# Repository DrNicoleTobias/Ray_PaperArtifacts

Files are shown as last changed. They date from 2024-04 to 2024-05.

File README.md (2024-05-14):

# Ray Sensor Documentation Notes

Ray is a batteryless, doorframe/passageway-mounted room-level occupancy monitoring sensor that uses changes in indoor ambient light reflections to detect people entering and exiting a room or hallway and estimate their direction of travel.

<table style="width: 100%; border-collapse: collapse;">
  <tr>
    <td style="width: 100%; text-align: center;">
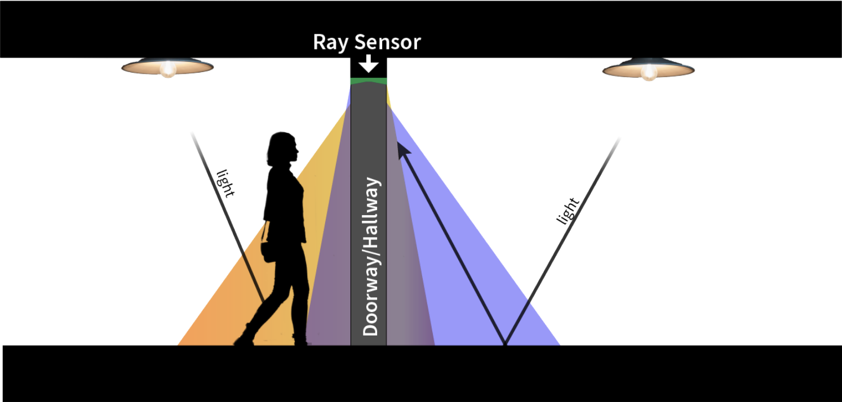
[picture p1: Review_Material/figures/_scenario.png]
Ray Use Scenario
      
      <br>
      <strong>Ray Use Scenario/Concept</strong>
    </td>
  </tr>
</table>

In this document, we provide the abstract of the work with highlights from our experiments, comments for the JSys reviewers, a layout of the folder/file structure, and instructions on how to build a Ray sensor and set it and a base station up for deployment.

# Abstract
Room-level occupancy-tracking systems enable intelligent control of building functions like air conditioning and power delivery to adapt to the needs of their occupants. Unfortunately, existing occupancy-tracking systems are bulky, have short battery lifetimes, are not privacy-preserving, or only provide coarse-grain occupancy information. Furthermore, retrofitting existing infrastructure with wired sensors is prohibitively expensive.

In this paper, we present Ray, a batteryless, doorframe/passageway-mounted room-level occupancy monitoring sensor that uses changes in indoor ambient light reflections to detect people entering and exiting a room or hallway and estimate direction of travel. We evaluated Ray in mixed lighting conditions on both sides of the doorway in an office-style setting, using subjects with a wide variety of physical characteristics. We conducted 881 controlled experiments in 7 doorways with 9 individuals and achieved a total detection accuracy of 100% and movement direction accuracy averaging 96.4%. Furthermore, we deployed Ray sensors for 64 days in 5 locations, comparing them with a commercial batteryless occupancy sensor. Ray outperformed the commercial sensor, particularly where traffic is moderate to heavy. Ray demonstrates that ambient light reflections provide both a promising low-cost, long-term sustainable option for monitoring how people use buildings and an exciting new research direction for batteryless computing.

# Artifact Evaluation - For JSys Reviewers
The artifacts associated with this paper consist of both hardware and software for building a functioning deployment of the Ray sensor.

We are including the custom PCB designs, Bill of Materials, and 3D prototype housing files used to create a Ray sensor. PDFs of the schematic and Design files are also included for reviewer convenience. Software for training and the firmware that runs the Ray sensor and base station are also provided. Documentation includes how to build, set up, tune, train, and deploy a Ray sensor as well as how to set up a base station for receiving the sensor data.

As the claims of this work are of the effectiveness of our custom Ray sensor, it is hard to automate items for testing and evaluation without actually having a physical sensor built, trained, and deployed for reviewers to test. After speaking with the chair of the Artifact Evaluation Board, we determined the best way to demonstrate the usability and reproducibility of this work is by providing the design files (raw and as PDFs for convenience), and making several demonstration videos to show the system working in controlled scenarios, in the presence of confounding cases, and when comparing to a commercial occupancy sensor. We hope they allow enough insight to judge the effectiveness, claims, and reproducibility of the work as it is hard to exactly recreate some of these experiments as they were gathered from live individuals walking through passageways.

# Folder/File Layout
This repo stores code, hardware files, and other technical documents for the project. Subdirectories are described below:

## Hardware
This folder contains all of the custom PCB Eagle design files (PDFs of the schematic and board design files are also included for reviewer convenience), Bill of Materials (BOM), and 3D prototype housing/enclosures files used to create a Ray sensor.

## Review_Material
This folder contains some of the additional artifact information for the working sensor including a Video Demo (.mp4) and a sampling of the data collected from both the controlled and uncontrolled experiments of the paper.  The Video Demo showcases the Ray sensor operating during a range of activities. These include people walking through doorways under the sensor, pass-by events where a person walks near the sensor but does not pass under it, and confounding cases like lingering and many people walking in a tight group. We also demonstrate in the video a comparison between the  sensor and the commercially available EnOcean sensor (a batteryless PIR-based occupancy sensor), showing that Ray is able to more accurately estimate the number of people during higher traffic conditions. 

Due to the nature of this project, much of the data gathering and ground truth labeling required manual intervention and processing to account for the amount of corner cases and fuzzy timing between two different sensors and ground truth.  A sampling of the manual data gathering for the controlled and uncontrolled experiments has been provided and the resulting excel files for the uncontrolled experiments are provided for review.  There are no scripts to run, table data for the uncontrolled experiments (Tables 5 and 6) came directly from excel formulas in the excel files for each location.

## Software
All software provided is either C code compiled and run on the MSP430FR5994 chips used for our sensor and base station or Python3 scripting code that is processed on a base station or laptop. Because there are variations in component quality and in doorway and lighting conditions, users want to train the classifier model on data more closely related to the test environment to improve accuracy. In that event, The following subfolders contain the code needed to gather the raw features from a Ray sensor (0_Get_Features) and train a new decision tree classifier model using those features (1_Train_Model). Once trained, the model will need to be manually implemented in the experiment code subfolders 2_Controlled_Studies and 3_Uncontrolled_Studies (specific locations to change are mentioned in those folders' ReadMe documentation.

### 0_Get_Features
This folder contains the firmware for both the Ray sensor and for a base station for gathering raw training data. The data gathered by the base station and sensor firmware here is intended for training a supervised classification model, in our case a decision tree model. This model should capture directional information from many individual events of common in and out events and can also include some additional example training data for some confounding, yet common, cases such as pass-by events. Have sample subjects walk in and out in a controlled manner to capture what the raw features from the sensor look like under local lighting conditions and environment. Collect this data using what is received at the base station and the result for that data that you wish to train with in a CSV file for use in training the model in the next step.

### 1_Train_Model
This folder contains a Python script called makedecisions.py that will use the CSV file of data gathered from the 0_Get_Features scripts/code in order to train a new decision tree to update the models for testing or real world deployment.

### 2_Controlled_Studies
This folder contains the firmware for both the Ray sensor and for a base station to receive packets from a Ray Sensor using the CC1101 Radio with a MSP430FR994 LaunchPad where the Ray Sensor sends a single packet for individual controlled events.

### 3_Uncontrolled_Studies
This folder contains the firmware for both the Ray sensor and for a base station to receive full packets from a deployed Ray Sensor using the CC1101 Radio with a MSP430FR994 LaunchPad where the Ray Sensor to send complete packets containing a sequence of 5 events, an estimate of their time between events, heartbeats in the absence of activity for 2 minutes, and history of the last two packets sent for redundancy.

# Building a Ray Sensor

In this section, we describe the steps it takes to build a physical Ray Sensor for deployment.

<table style="width: 150%; border-collapse: collapse;">
  <tr>
    <td style="width: 50%; text-align: center;">
      Ray Use Scenario
      <br>
      <strong>Ray PCB Close Up</strong>
    </td>
    <td style="width: 100%; text-align: center;">
      Ray Use Scenario
      <br>
      <strong>Ray Full Sensor</strong>
    </td>
  </tr>
</table>

## Housing/Enclosure, Parts, and Assembly
Our prototype hardware integrates a modular custom printed circuit board (PCB) housed in a 3D-printed plastic enclosure, four solar panels, and a TI CC1101 radio.

### Custom PCB
The PCB for the Ray sensor consists of three modular parts: a Solar_Module, a MCU_Module, and a Radio_Module. All design files for these modules and the Bill of Materials for all necessary PCB components can be found in the Hardware/PCB_Designs/ folder. Boards can be fabricated at many places online, such as OSHpark etc, and the components can be populated by hand or by a manufacturer as well. Design files can be viewed directly by a program like Eagle, but PDFs have been made available for convenience of viewing. The Solar_Module attaches to the MCU_Module and the MCU_Module attaches to the Radio_Module.

### 3D Enclosure
The 3D printed mounting system is made of PLA plastic and contains the PCB, solar cells, and necessary wiring connecting them. Enclosure designs to house the PCB and attach the solar panels to can be found in Hardware/3D_Enclosure/PCB_Housing_and_20_DegBody_Assembly.stl with a second file Hardware/3D_Enclosure/PCB_Housing_Cap.stl to make a cap to cover the PCB during deployment. The enclosure provides a nesting place for the solar cells, which angles the solar cell slots such that two of the four of the solar cells are pointed toward the entry, while the rest are pointed toward the exit.

### Connecting Solar Panels
Four solar panels need to be attached to the enclosure, where they will be divided into two sets of two panels each, one facing inward (the direction the radio antenna is pointing) and one set facing outward. The inward set of solar panels are connected in series and connected to the SOLAR1 terminal of the Solar Module PCB. The outward facing panels are also connected in series and then added to the SOLAR2 terminal.

### Tune the Detectors
Ray uses a detection circuit to determine when to wake up the microcontroller to assess the possible event. The detector circuitry is tunable using trim potentiometers (trim pots) pre-installation in deployment. Testers may find that, depending on the lighting conditions of a particular doorway, the sensitivity of the detector circuit's trim pots may need adjusting. We found in our experiments that we did need to adjust the trim pots some for the general lighting conditions and found that they generally worked for other similar lighting conditions without needing to be readjusted for every doorway. Using a screwdriver on TM1 for monitoring SOLAR1 or TM2 for monitoring SOLAR2 from the Solar_Module PCB schematics, turning to one direction will move the detection threshold and make the detectors more sensitive while turning in the opposite direction will make them less sensitive.

### Attaching a Radio
The Ray PCB also uses a TI CC1101 radio for communication that is to be connected to the Radio_Module in Hardware/PCB_Designs/. The TI CC1101 radio board is an off-the-shelf board that we designed a plug-in for on the Radio_Module boards. For our purposes, we considered the direction the antenna was pointing to be inward when mounting the sensor for practice, but one could train and adjust the code if pointing the other direction is preferred.

### Installing on a doorway
With all the parts assembled, tuned, connected, and attached to the 3D printed enclosure, the Ray sensor can be attached to the top of a doorway/passageway frame with solar panels facing down any preferred orientation. For our experiments, we affixed the 3D enclosure to a piece of wood with magnets screwed to the other side for ease in attaching and removing the sensor on different doorway/passageway frames, as most within our office building had metal frames or structures.

## Setting up a Base Station
To receive the data packets from the Ray Sensor, you will need a MSP430FR5994 LaunchPad and another off-the-shelf CC1101 Radio.  The radio will need to be connected to the LaunchPad’s pins as follows:
```
	*MSP430FR5994*	←    *CC1101*
		VCC	←	VCC
	 	GND	←	GND
	 	P3.4	←	GDO0
	 	P3.6	←	GDO2
	 	P4.3  	←	CSN
	 	P5.0  	←	MOSI
	 	P5.1 	←	MISO
	 	P5.2  	←	SCK 
```
And as documented in the top comment of each basestation_receive.c code in the folders containing base station code. If these pins need to be modified for a particular setup, there is an /includes/pins.h file in each folder containing base station code that can be easily modified.  Once attached, the base station firmware will need to be installed to the LaunchPad simply by connecting the LaunchPad by USB to a computer with msp-gcc installed.  Navigate to the firmware folder of interest, update the makefile as suggested in that folder’s readme, and then simply run “make install” to install the firmware on the LaunchPad.   Data can be gathered by simply reading off what is sent over serial or by using a script that grabs what is coming across from the LaunchPad over serial to a database.

## Training the event classification model
### Gather Raw Feature Data
All code needed to gather features to train a new model is located in the /Software/0_Get_Features/ folder for both the base station and the sensor.  Connect the LaunchPad to install the sensors firmware using the on board programmer (requires removing some jumpers) then return the jumpers and install the base station firmware for data collection.  Attach the sensor to a doorway or passageway face down, orientated in the direction you wish to train as inward vs outward.  Gather the data sent from the sensor to the base station over the serial port from many different individual controlled events and denote the ground truth for supervised training.  Record all of this data in a CSV file that will be used to train a new decision tree model.

### Train Model
To train a new decision for a new deployable environment, the following Python3 libraries must be installed: pandas, graphviz, and scikit-learn.  Once installed, navigate to the Software/1_Train_Model/ folder and locate the makedecisions.py file.  The file will need an updated path to the CSV feature data that was collected and there are several different classifier options available to train with.  Simply run “python3 makedecisions.py” to execute that code.  A visual graph will be generated for you to assess just how the training data falls in the model.
Some sample training data is available in that folder from our experimental setup that can be run with the makedecisions.py script in its current state to test how that script works.

### Translate Decision Tree Diagram to Implementation**
Now that a tree has been generated by the makedecisions.py script and the training data gathered, it will need to be manually translated and implemented in the deployable code for evaluating_event() found in both 2_Controlled_Experiments/RaySensor/SensorControlExperiments.c and 3_Uncontrolled_Experiments/RaySensor/SensorControlExperiments.c.  The documentation in both places will reference the line numbers where that function resides.  Once implemented, the firmware can be installed/uploaded to the sensor and the sensor can be deployed.

### Installing Firmware
The Ray firmware is designed to be ultra-low power, even in active mode, and has low computational complexity, offloading the bulk of the detection to the hardware circuits. All firmware code in the Software folder basically requires the same setup in order to program either the launchpad or the Ray Sensor.
1. Change the SUPPORT_FILE_DIRECTORY in the makefile to your msp430 gcc include
   path.
2. Hook up a MSP430FR5994 LaunchPad to your computer.
3. Connect the sensor to the Programmer pins on the LaunchPad (some jumpers may need to be removed to accomplish this) and plug them in to the appropriate programming pins on the MCU_Module.
4. Use "make install" to load the program into your device.
5. Detach from the programmer and reconnect the PCB in the enclosure and the unit is ready to be deployed. (Skip steps 3 and 5 if programming a MSP430 LaunchPad for a base station)

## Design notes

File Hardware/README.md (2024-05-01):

This folder contains all PCB hardware module files, Bill of Materials (BOM) associated with each module and the design files to 3D print a prototyping enclosure and cap/cover for the finished sensor PCB.

# PCB_Designs
This folder contains all of the design files for the custom Ray PCB modules (Solar, MCU, and Radio) as well as PDFs of these design files for viewers convenience.  These files were created using the AutoDesk Eagle Software.

# 3D_Enclosure
This folder is for the various 3D housing models that have been created for housing the custom PCB and solar panels for the final Ray Sensor.  

**BOM.xlsx**
This is the Bill of Materials that lists the parts/components used for each of the custom PCB modules (arranged by tabs).

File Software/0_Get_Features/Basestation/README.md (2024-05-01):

#### Intro
This is the firmware for a base station to  Receive packets using the CC1101 Radio with a MSP430FR994 launchpad.

#### Setup
1. Change the SUPPORT_FILE_DIRECTORY in the makefile to your msp430 gcc include
   path.
2. Hook up a MSP430FR5994 LaunchPad to your computer.
3. Use "make install" to load the program into your device.

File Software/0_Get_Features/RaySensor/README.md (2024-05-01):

#### Intro
This is the firmware for the Ray Sensor to send Raw Feature packets using the CC1101 Radio with a MSP430FR994 launchpad.  The features can be trimmed down to just ch1_start, ch1_end, ch2_start, ch2_end and the rest post processed from those values if you need to save energy due to packet size.

#### Setup
1. Change the SUPPORT_FILE_DIRECTORY in the makefile to your msp430 gcc include
   path.
2. Hook up a MSP430FR5994 LaunchPad to your computer.
3. Connect the sensor to the Programmer pins on the launchpad (You may need to remove some jumpers to accomplish this) and plug them in to the appropriate programming pins on the MCU_Module.
4. Use "make install" to load the program into your device.
5. Detach from programmer and reconnect the PCB in the enclosure and you are ready to deploy.

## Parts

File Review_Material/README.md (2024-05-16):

# Review_Materials

This folder contains some of the additional artifact information for the working sensor including a Video Demo (.mp4) and a sampling of the data collected from both the controlled and uncontrolled experiments of the paper. 

## Controlled Tests
<table style="width: 100%; border-collapse: collapse;">
  <tr>
    <td style="width: 100%; text-align: center;">
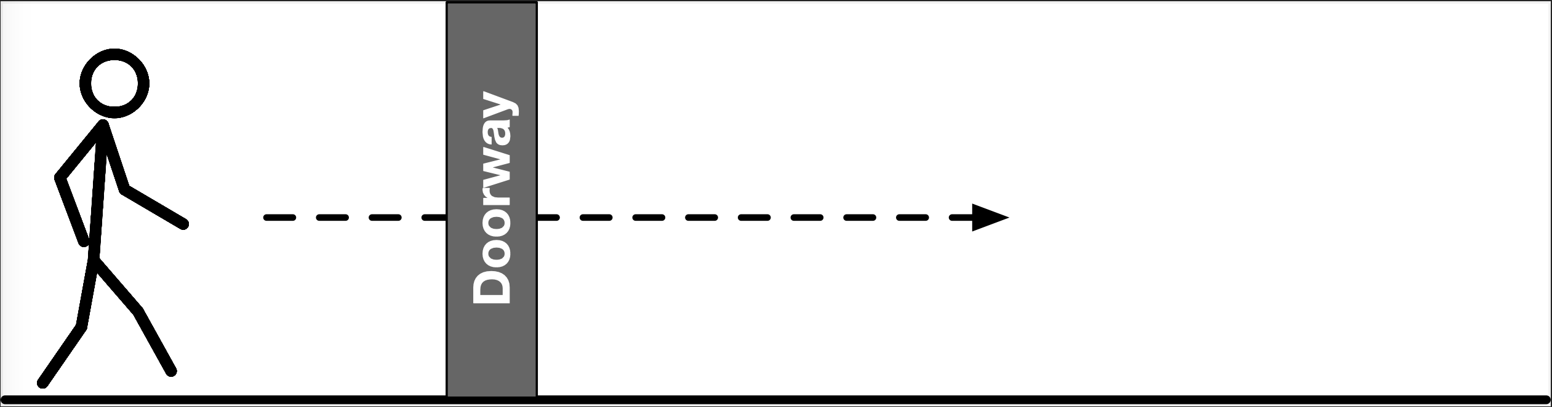
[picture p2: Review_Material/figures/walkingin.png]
Testing the Sensor: Controlled
      
      <br>
      <strong>Testing the Sensor: Controlled</strong>
    </td>
  </tr>
</table>
For the controlled experiments we collected data manually with the sensor sending out a single packet after each detected event.  We asked a subject to walk through the passageway where we would record the direction classified by out sensor in the column for the ground truth of the sensor as you can see in some of the samples provided in controlled_data_samples.pdf.  Most of the recordings were pretty straight forward, but occasionally other people (not affiliated with the experiment) would traverse the hallway or near the doorway and would trigger the sensor.  When this occurred, we marked that at a clobbered packet, discounted that info as it was not part of the control, and requested the subject to do another clean run to make up for the clobbered test.  This file shows that our sensor did well at detecting all of the events but occasionally classified them incorrectly.

## Video Demo

The Video Demo (SensorDemo.mp4) showcases the Ray sensor operating during a range of activities. These include people walking through doorways under the sensor, pass-by events where a person walks near the sensor but does not pass under it, and confounding cases like lingering and many people walking in a tight group. We also demonstrate in the video a comparison between the sensor and the commercially available EnOcean sensor (a batteryless PIR-based occupancy sensor), showing that Ray is able to more accurately estimate the number of people during higher traffic conditions.

## Uncontrolled Deployment

<table style="width: 100%; border-collapse: collapse;">
  <tr>
    <td style="width: 100%; text-align: center;">
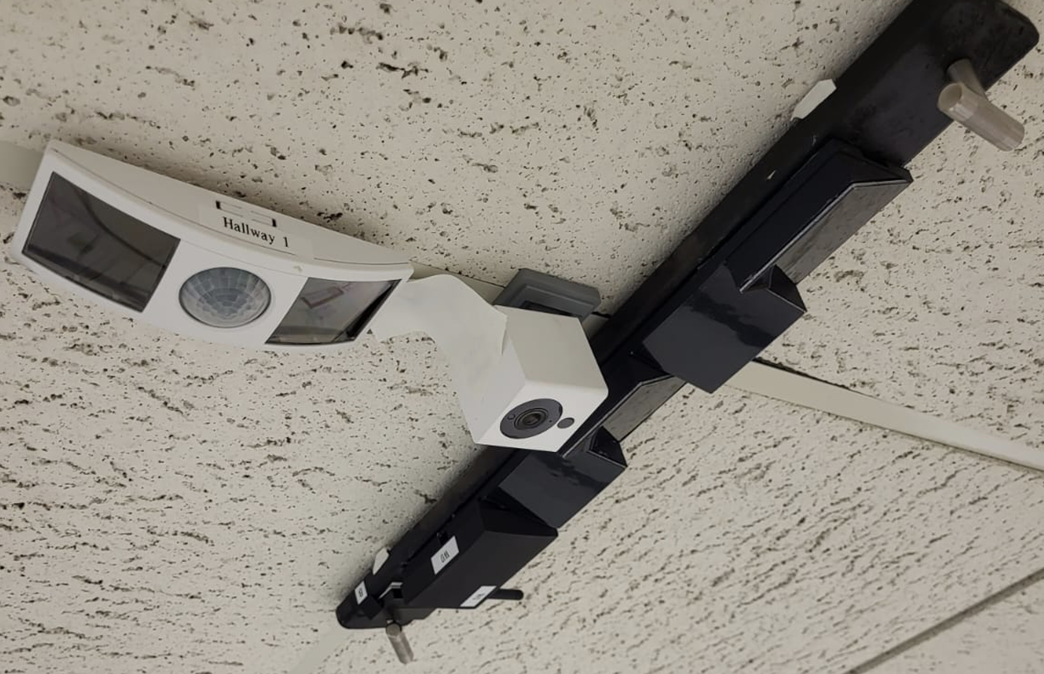
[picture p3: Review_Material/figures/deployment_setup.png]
Deployment Setup
      
      <br>
      <strong>Deployment Setup</strong>
    </td>
  </tr>
</table>

Due to the nature of this project, much of the data gathering and ground truth labeling required manual intervention and processing to account for the amount of corner cases and fuzzy timing between two different sensors and ground truth. A sampling of the manual data gathering for the controlled and uncontrolled experiments has been provided and the resulting excel files for the uncontrolled experiments are provided for review. There are no scripts to run, table data for the uncontrolled experiments (Tables 5 and 6) came directly from excel formulas in the excel files for each location.

### Ground Truth
Ground truth was captured by an off the shelf Wyze camera that was constantly powered and capturing data.  Video was collected, processed to pull out any frames with movement, and then manually labeled.  The field of view was different for the camera than for either sensor and with reliable power had a more accurate sense of time.  This made matching up our sensor data and commercial sensor data to compare a bit of a manual process as well.

### Our Sensor vs Ground Truth
<table style="width: 100%; border-collapse: collapse;">
  <tr>
    <td style="width: 100%; text-align: center;">
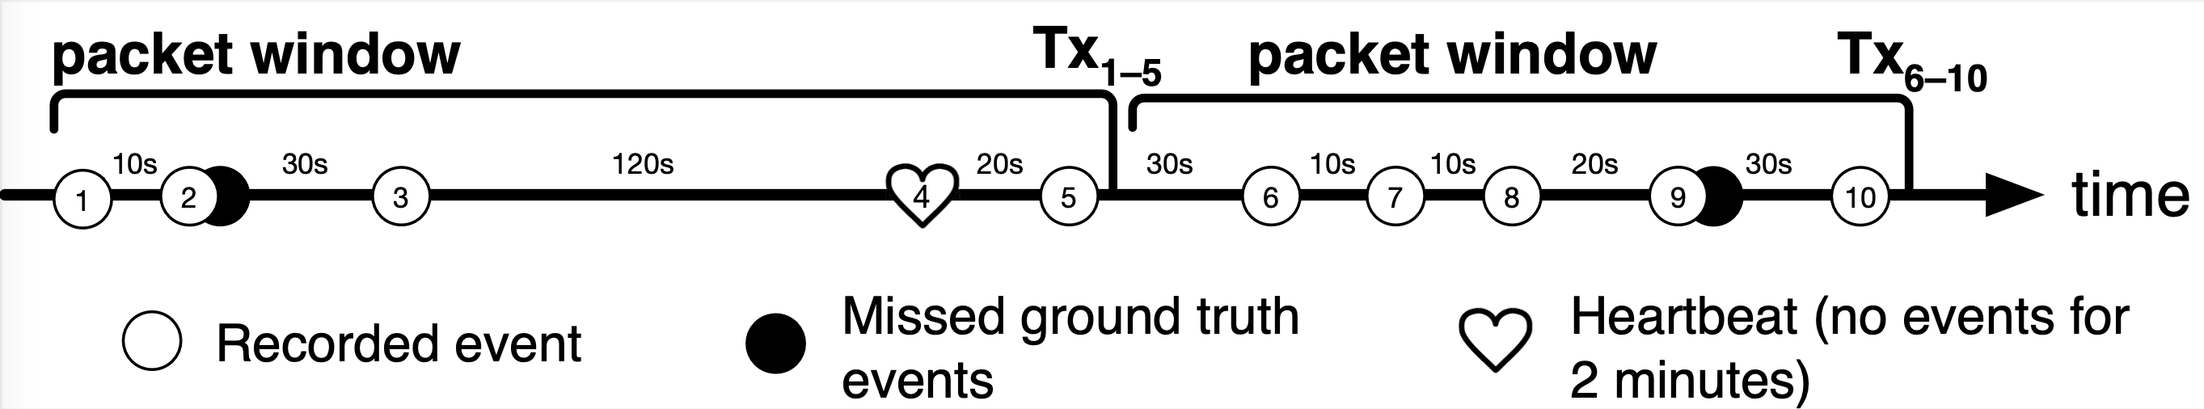
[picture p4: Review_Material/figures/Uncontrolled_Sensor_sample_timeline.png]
Example Sensor Event Timeline
      
      <br>
      <strong>Example Sensor Event Timeline</strong>
    </td>
  </tr>
</table>

### Our Sensor vs Commercial Sensor (EnOcean)

<table style="width: 100%; border-collapse: collapse;">
  <tr>
    <td style="width: 100%; text-align: center;">
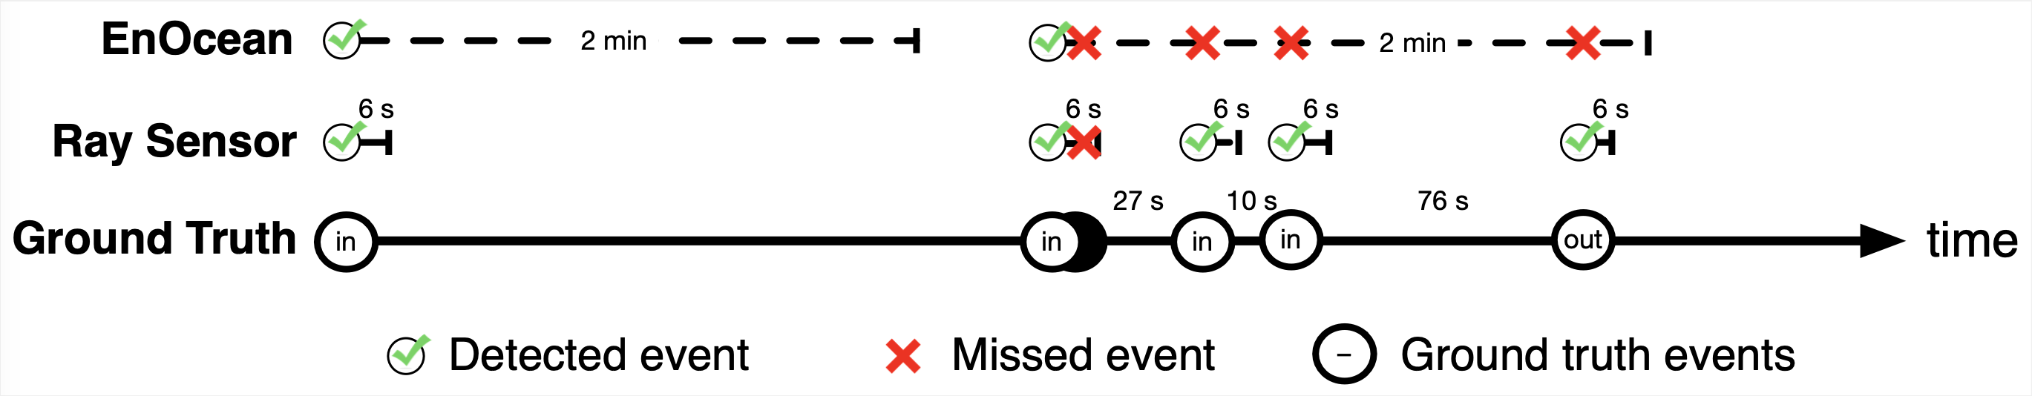
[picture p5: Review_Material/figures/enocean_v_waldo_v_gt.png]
Example Sensor Comparison Timeline
      
      <br>
      <strong>Example Sensor Comparison Timeline</strong>
    </td>
  </tr>
</table>

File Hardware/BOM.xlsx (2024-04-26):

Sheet: SolorPanel_Mod
Index | Quantity | Part Number | Manufacturer P/N | Description | Customer Reference | Unit Price USD | Extended Price USD | Price per 1000 | Extended Price per 1000 | Purchased From
1 | 2 | ED10561-ND | OSTVN02A150 | CONN TERM BLOCK 2.54MM 2POS PCB | Solar1, Solar2 | 0.92 | $1.84 | $312.49 | $624.98 | Digi-Key
2 | 1 | P0.0GCT-ND | ERJ-3GEY0R00V | RES SMD 0 OHM JUMPER 1/10W 0603 | R0 | 0.1 | $0.10 | $7.65 | $7.65 | Digi-Key
4 | 1 | 749-1754-1-ND | MCT06030C5102FP500 | RES 51K OHM 1% 1/10W 0603 | R2 | 0.15 | $0.15 | $48.88 | $48.88 | Digi-Key
6 | 1 | YAG4565CT-ND | RT0603BRD07499KL | RES SMD 499K OHM 0.1% 1/10W 0603 | R4 | 0.31 | $0.31 | $43.56 | $43.56 | Digi-Key
7 | 2 | 511-SFR03EZPF7503CT-ND | SFR03EZPF7503 | 750 kOhms ±1% 0.1W, 1/10W Chip Resistor 0603 | R1, R10 | 0.14 | $0.28 | $21.38 | $42.76 | Digi-Key
8 | 1 | 311-1.20MHRCT-ND | RC0603FR-071M2L | RES SMD 1.2M OHM 1% 1/10W 0603 | R3 | 0.1 | $0.10 | $3.45 | $3.45 | Digi-Key
9 | 1 | YAG3326CT-ND | RC0603FR-071M3L | RES SMD 1.3M OHM 1% 1/10W 0603 | R5 | 0.1 | $0.10 | $3.45 | $3.45 | Digi-Key
10 | 4 | 311-2.00MHRCT-ND | RC0603FR-072ML | RES SMD 2M OHM 1% 1/10W 0603 | R6, R7, R8, R9 | 0.1 | $0.40 | $3.45 | $13.80 | Digi-Key
13 | 4 | 478-1227-1-ND | 06035C103KAT2A | CAP CER 10000PF (10nF) 50V X7R 0603 | C1, C4, C5, C6 | 0.1 | $0.40 | $7.53 | $30.12 | Digi-Key
14 | 1 | 1276-1012-1-ND | CL10F104ZB8NNNC | CAP CER 0.1UF 50V Y5V 0603 | C3 | 0.1 | $0.10 | $6.61 | $6.61 | Digi-Key
16 | 2 | 490-10510-1-ND | GRM21BR60G107ME15L | CAP CER 100UF 4V X5R 0805 | C2*stacked | 1.04 | $2.08 | $1040.00 | $2080.00 | Digi-Key
17 | 1 | BZT52C5V1-FDICT-ND | BZT52C5V1-7-F | DIODE ZENER 5.1V 500MW SOD123 | Z1 | 0.22 | $0.22 | $45.42 | $45.42 | Digi-Key
18 | 1 | RB751S40T1GOSCT-ND | RB751S40T1G | DIODE SCHOTTKY 30V 30MA SOD523 | D1 | 0.21 | $0.21 | $44.52 | $44.52 | Digi-Key
19 | 1 | 576-2923-1-ND | MIC841HYC5-TR | IC COMP SNGL W/REF SC70-5 | MIC | 0.77 | $0.77 | $600.00 | $600.00 | Digi-Key
20 | 1 | 1662-2522-1-ND | S-1313D22-N4T1U4 | IC REG LINEAR 2.2V 200MA SC82AB | REG | 1.45 | $1.45 | $663.00 | $663.00 | Mouser
21 | 2 | TC33X-104ECT-ND | TC33X-2-104E | TRIMMER 100K OHM 0.1W J LEAD TOP | TM1, TM2 | 0.28 | $0.56 | $174.22 | $348.44 | Digi-Key
22 | 2 | 296-37910-1-ND | TLV3691IDCKR | IC COMPARATOR NANO-POWER SC70-5 | C_COMP, B_COMP | 1.31 | $2.62 | $596.28 | $1192.56 | Digi-Key
23 | 4 | n/a | SKU 313070004 | 0.5W Solar Panel 55x70 | solar panels | 1.95 | $7.80 | $1660.00 | $6640.00 | SEEEDstudio
24 | 1 | 401-1999-1-ND | JS102011SAQN | SWITCH SLIDE SPDT 300MA 6V | S1 | 0.64 | $0.64 | $433.70 | $433.70 | Digi-Key
25 | 1 | 609-3371-ND | 68602-208HLF | CONN HEADER 8POS .100 STR 15AU | J1 | 0.59 | $0.59 | $306.47 | $306.47 | Digi-Key
26 | 10 | A106145CT-ND | RCU-0C | PC TEST POINT NATURAL | VIN, VCC, BDIFF, CDIFF, BRAW, CRAW, BREF, CREF, BRES, CRES | 0.26 | $2.60 | $123.95 | $1239.50 | Digi-Key
27 | 4 | S9014E-03-ND | GRPB031VWVN-RC | CONN HEADER .050" 3POS PCB GOLD | JP2, JP3, JP23, JP24 | 0.28 | $1.12 | $130.72 | $522.88 | Digi-Key
28 | 4 | 952-1731-ND | M50-2000005 | CONN SHUNT 1.27MM BLACK W/HANDLE | JP2, JP3, JP23, JP24 | 0.44 | $1.76 | $208.56 | $834.24 | Digi-Key
 |  |  |  |  |  | total: | 26.2 |  | 15.77599
 | 52
updated 2/14/23

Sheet: MCU_Mod
Index | Quantity | Part Number | Manufacturer P/N | Description | Customer Reference | Unit Price USD | Extended Price USD | Price per 1000 | Extended Price per 1000 | Purchased From
1 | 1 | 541-820HCT-ND | CRCW0603820RFKEA | RES SMD 820 OHM 1% 1/10W 0603 | R1 | 0.1 | $0.10 | $7.01 | $7.01 | Digi-Key
2 | 1 | RMCF0603FT2M00CT-ND | RMCF0603FT2M00 | RES 2M OHM 1% 1/10W 0603 | R3 | 0.1 | $0.10 | $9.32 | $9.32 | Digi-Key
3 | 1 | RMCF0603JT12M0CT-ND | RMCF0603JT12M0 | RES 12M OHM 5% 1/10W 0603 | R2 | 0.1 | $0.10 | $3.72 | $3.72 | Digi-Key
4 | 1 | 311-47.0KHRCT-ND | RC0603FR-0747KL | RES SMD 47K OHM 1% 1/10W 0603 | R4 | 0.1 | $0.10 | $3.45 | $3.45
5 | 0 | 1276-1192-1-ND | CL10A106KP8NNNC | CAP CER 10UF 10V X5R 0603 | C1*, C6* | 0.19 | $0.00 | $37.85 | $0.00 | Digi-Key
6 | 4 | 1276-1012-1-ND | CL10F104ZB8NNNC | CAP CER 0.1UF 50V Y5V 0603 | C2, C3, C4*, C5*, C9, C10 | 0.1 | $0.40 | $6.61 | $26.44 | Digi-Key
7 | 2 | 1276-2228-1-ND | CL10C220JB8NFNC | CAP CER 22PF 50V C0G/NP0 0603 | C7, C8 | 0.1 | $0.20 | $10.89 | $21.78 | Digi-Key
8 | 1 | 490-4931-1-ND | GCM188R71H222KA37D | CAP CER 2200PF 50V X7R 0603 | C11 | 0.19 | $0.19 | $36.21 | $36.21
9 | 1 | RB751S40T1GOSCT-ND | RB751S40T1G | DIODE SCHOTTKY 30V 30MA SOD523 | D1 | 0.21 | $0.21 | $44.52 | $44.52 | Digi-Key
10 | 1 | 160-1183-1-ND | LTST-C190GKT | LED GREEN CLEAR CHIP SMD | D2 | 0.24 | $0.24 | $44.18 | $44.18 | Digi-Key
11 | 1 | 296-45416-1-ND | MSP430FR5994IRGZT | IC MCU 16BIT 256KB FRAM 48VQFN | U1 | 13.28 | $13.28 | $8650.86 | $8650.86 | Digi-Key
12 | 1 | ISL21080DIH309Z-TKCT-ND | ISL21080DIH309Z-TK | IC VREF SERIES 0.9V SOT23-3 | U2 | 2.06 | $2.06 | $1224.30 | $1224.30 | Digi-Key
13 | 0 | 296-47911-1-ND | LPV821DBVR | ZERO-DRIFT LOW POWER AMPLIFIER | U3*, U4* | 2.42 | $0.00 | $1189.64 | $0.00 | Digi-Key
14 | 1 | SER4071CT-ND | FC-135R 32.7680KA-A3 | CRYSTAL 32.7680KHZ 12.5PF SMT | Q1 | 1.18 | $1.18 | $919.10 | $919.10 | Digi-Key
15 | 1 | 490-5216-1-ND | BLM18HE152SN1D | FERRITE BEAD 1.5 KOHM 0603 1LN | L1 | 0.19 | $0.19 | $60.78 | $60.78 | Digi-Key
16 | 2 | S9014E-03-ND | GRPB031VWVN-RC | CONN HEADER .050" 3POS PCB GOLD | Jumpers (ON, Batt_jmp) | 0.28 | $0.56 | $130.72 | $261.44 | Digi-Key
17 | 2 | 952-1731-ND | M50-2000005 | CONN SHUNT 1.27MM BLACK W/HANDLE | Jumpers Caps | 0.44 | $0.88 | $208.56 | $417.12 | Digi-Key
18 | 1 | ED10561-ND | OSTVN02A150 | CONN TERM BLOCK 2.54MM 2POS PCB | Batt | 0.92 | $0.92 | $312.49 | $312.49 | Digi-Key
19 | 1 | S7072-ND | PPTC042LFBN-RC | CONN HEADER FMALE 8PS .1" DL TIN | Solar-1 | 0.67 | $0.67 | $368.64 | $368.64 | Digi-Key
20 | 1 | S7074-ND | PPTC062LFBN-RC | CONN HEADER FMAL 12PS .1" DL TIN | Radio_conn | 0.79 | $0.79 | $433.44 | $433.44 | Digi-Key
21 | 3 | A106145CT-ND | RCU-0C | PC TEST POINT NATURAL | test point probes | 0.26 | $0.78 | $123.95 | $371.85 | Digi-Key
 |  |  |  |  |  | total: | $22.95 |  | $13.22
updated 2/14/23 |  |  |  |  | * = DNP

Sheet: Radio_Mod
Index | Quantity | Part Number | Manufacturer P/N | Description | Customer Reference | Unit Price USD | Extended Price USD | Unit Price per 1000 | Extended Price per 1000 | Purchased From
1 | 1 | 749-1615-1-ND | MCT06030C2203FP500 | RES 220K OHM 1% 1/10W 0603 | R2 | 0.15 | $0.15 | $22.64 | $22.64 | Digi-Key
2 | 2 | RMCF0603JT12M0CT-ND | RMCF0603JT12M0 | RES 12M OHM 5% 1/10W 0603 | R1, R3 | 0.1 | $0.20 | $3.72 | $7.44
3 | 2 | 490-10510-1-ND | GRM21BR60G107ME15L | CAP CER 100UF 4V X5R 0805 | C1*stacked | 1.04 | $2.08 | $1040.00 | $2080.00 | Digi-Key
4 | 1 | RB751S40T1GOSCT-ND | RB751S40T1G | DIODE SCHOTTKY 30V 30MA SOD523 | D1 | 0.21 | $0.21 | $44.52 | $44.52 | Digi-Key
5 | 2 | 3313J-1-205ECT-ND | 3313J-1-205E | TRIMMER 2M OHM 0.125W J LEAD TOP | TM1, TM2 | 0.29 | $0.58 | $186.34 | $372.68 | Digi-Key
6 | 1 | 1662-2522-1-ND | S-1313D22-N4T1U4 | IC REG LINEAR 2.2V 200MA SC82AB | REG | 1.45 | $1.45 | $663.00 | $663.00 | Digi-Key
7 | 2 | 296-37910-1-ND | TLV3691IDCKR | IC COMPARATOR NANO-POWER SC70-5 | Hi-lo-1, Hi-lo-2 | 1.31 | $2.62 | $596.28 | $1192.56 | Digi-Key
8 | 1 | S6105-ND | PPTC052LFBN-RC | CONN HEADER FEM 10POS .1" DL TIN | cc1101_conn | 0.69 | $0.69 | $378.72 | $378.72 | Digi-Key
9 | 1 | S2021E-06-ND | PBC06DABN | CONN HEADER .100 DUAL STR 12POS | radio_conn | 0.98 | $0.98 | $608.40 | $608.40 | Digi-Key
10 | 6 | A106145CT-ND | RCU-0C | PC TEST POINT NATURAL | test point probes | 0.26 | $1.56 | $123.95 | $743.70 | Digi-Key
11 | 3 | S9014E-03-ND | GRPB031VWVN-RC | CONN HEADER .050" 3POS PCB GOLD | Jumpers (ON, Batt_jmp) | 0.28 | $0.84 | $130.72 | $392.16 | Digi-Key
12 | 3 | 952-1731-ND | M50-2000005 | CONN SHUNT 1.27MM BLACK W/HANDLE | Jumpers Caps | 0.44 | $1.32 | $208.56 | $625.68 | Digi-Key
13 | 1 | N/a | RF1100SE | CC1101 Wireless RF Transceiver 315/433/868/915MHZ + SMA Antenna Wireless Module | CC1101 Radio + Antenna | 11.5 | $11.50 | $1150.00 | $1150.00 | Amazon
 |  |  |  |  |  | total: | $24.18 |  | $8.28
updated 2/14

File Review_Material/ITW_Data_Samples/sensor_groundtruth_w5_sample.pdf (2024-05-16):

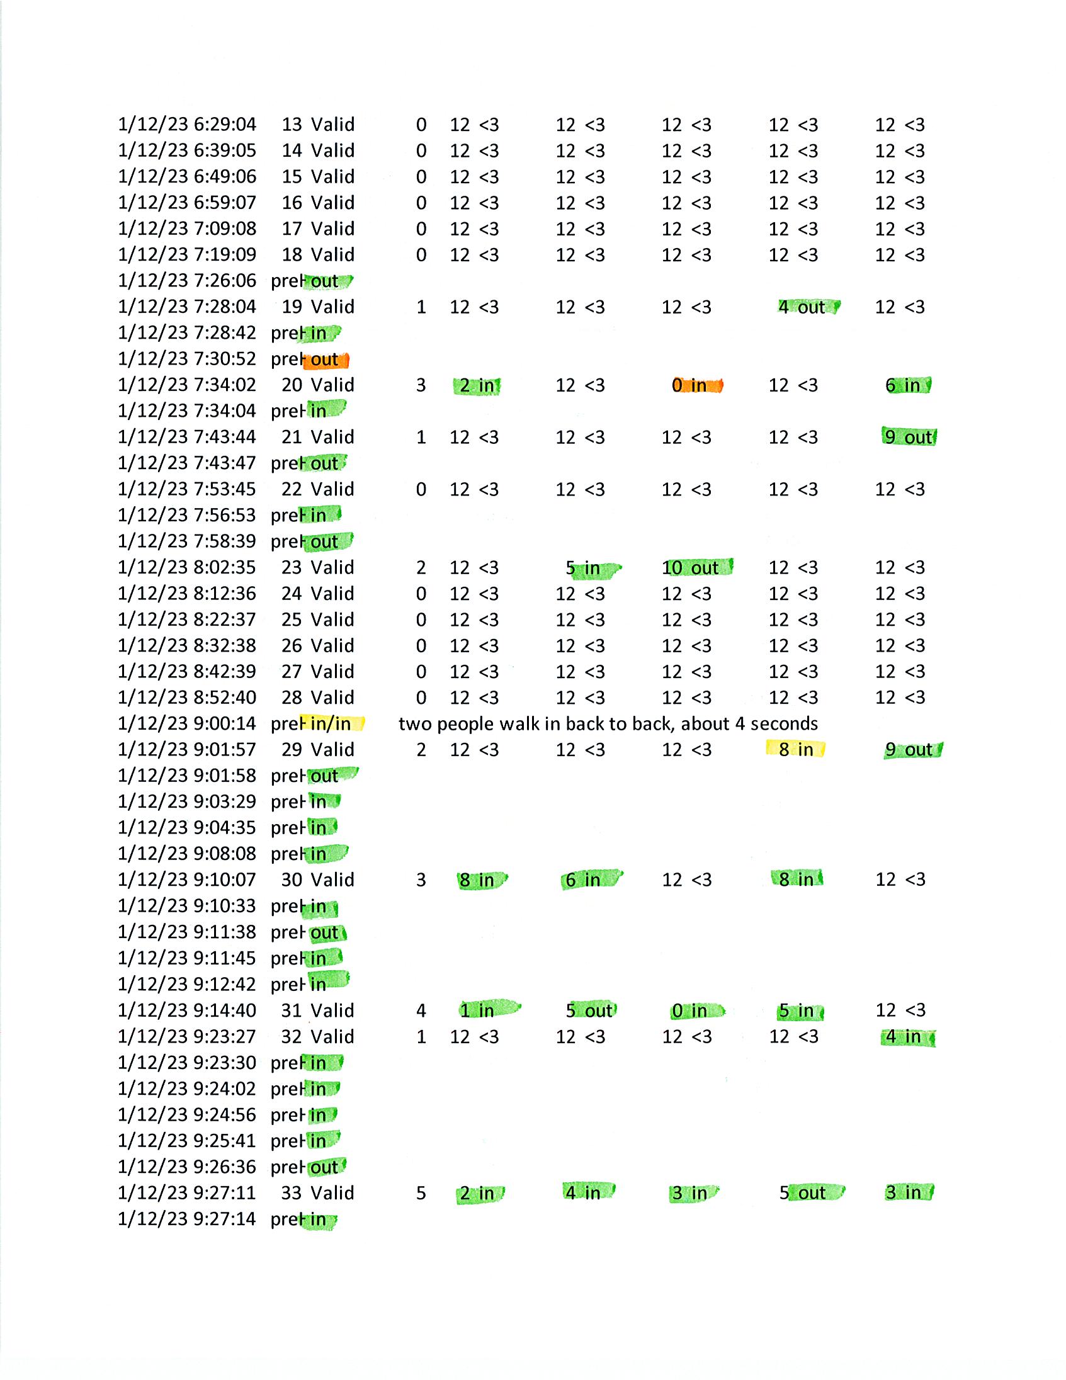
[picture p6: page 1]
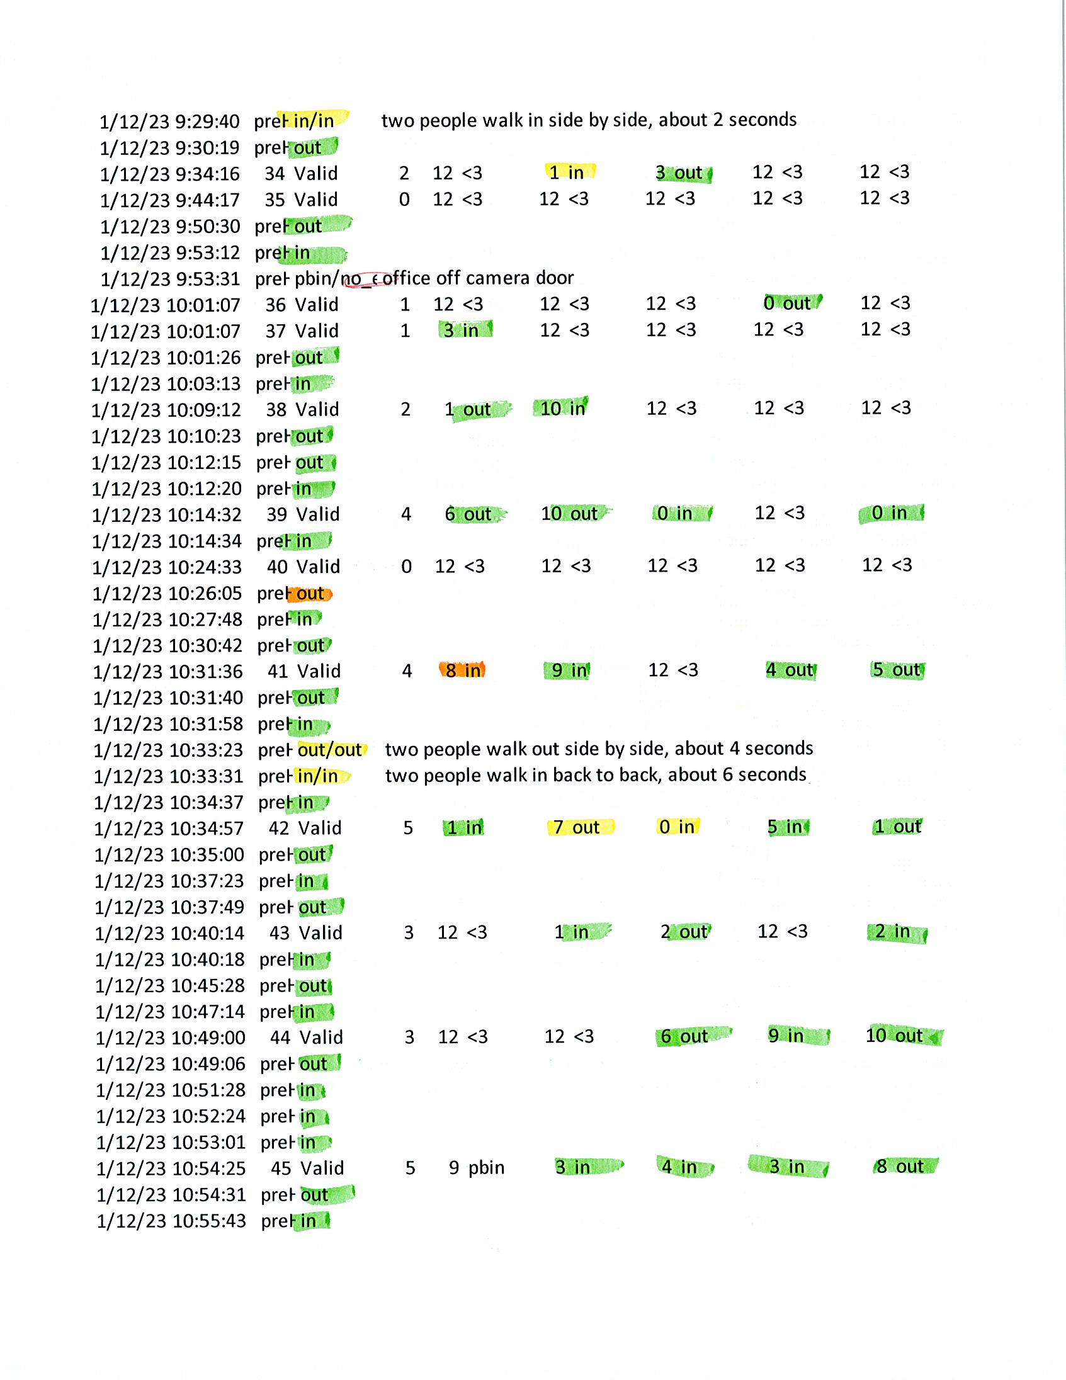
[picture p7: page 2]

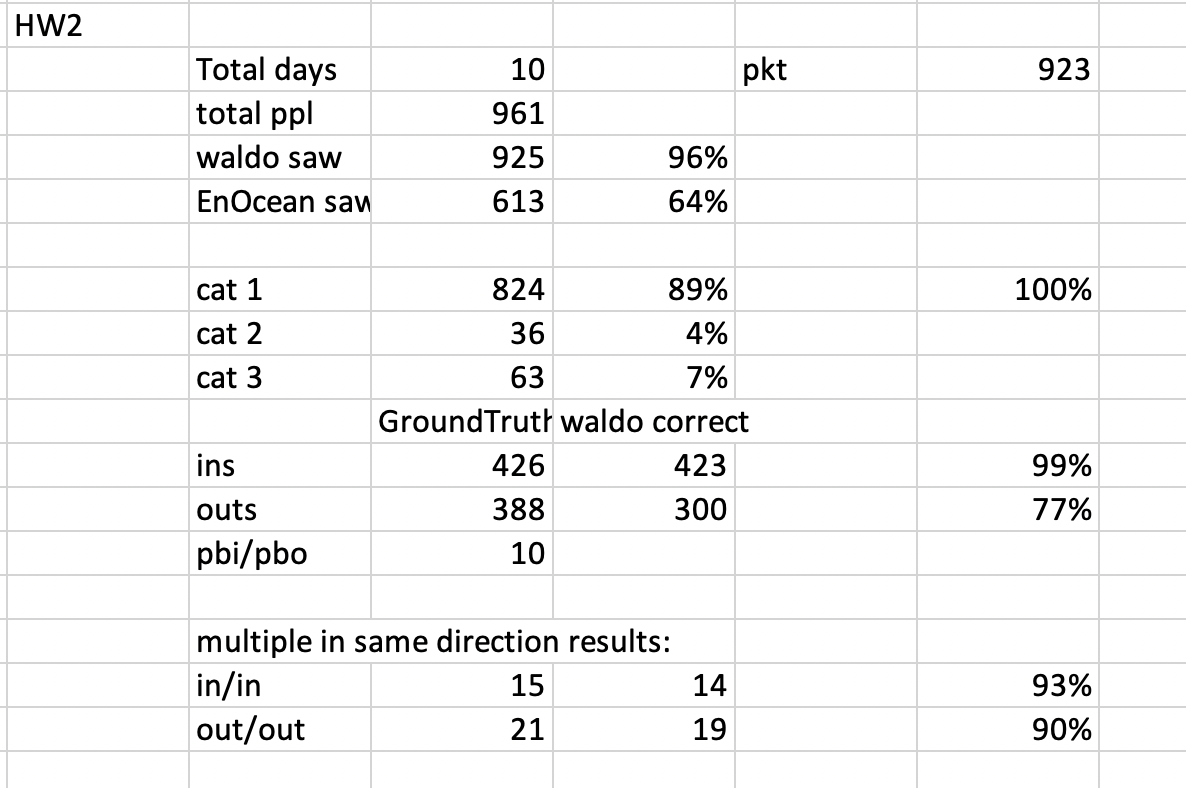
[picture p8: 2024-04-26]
Review_Material/ITW_Data_Samples/W2_HW2_Summary.png

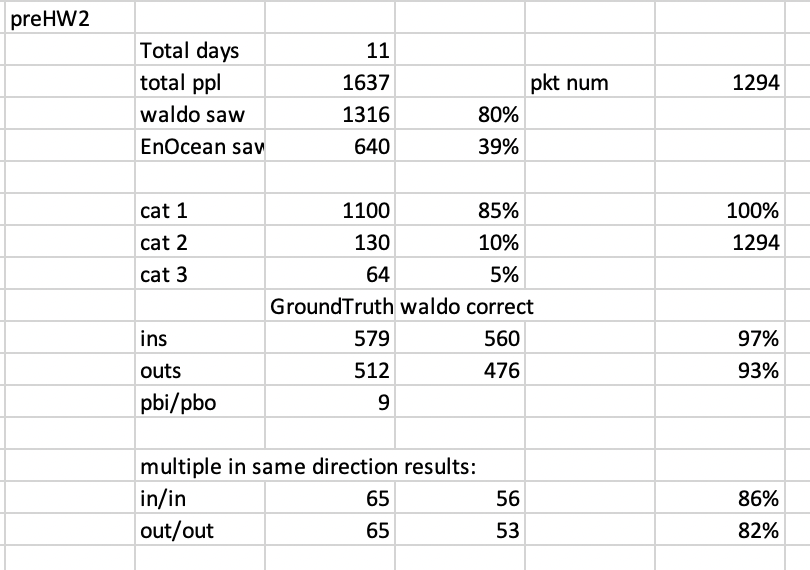
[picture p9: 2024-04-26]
Review_Material/ITW_Data_Samples/W5_preHW2_Summary.png

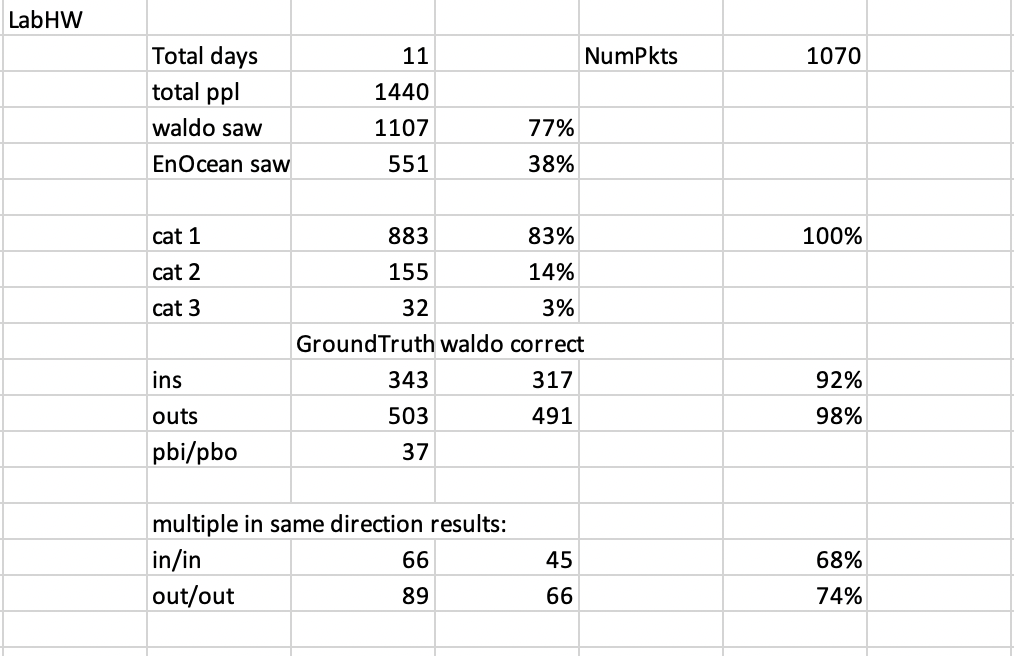
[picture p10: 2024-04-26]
Review_Material/ITW_Data_Samples/W4_LabHW_Summary.png

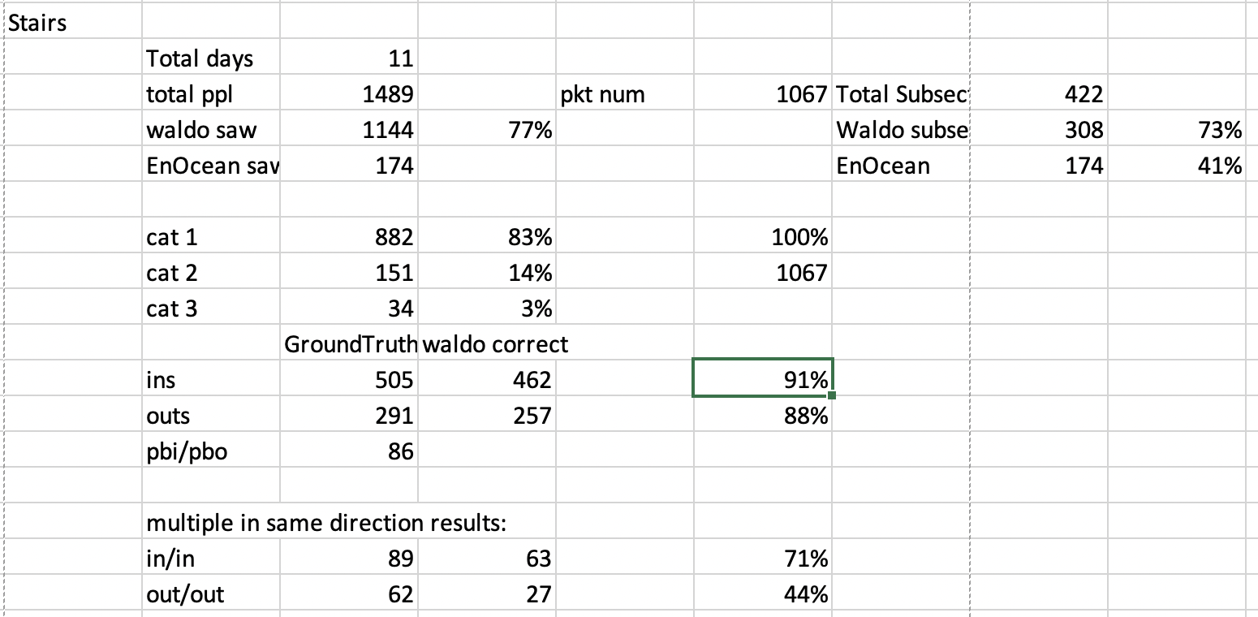
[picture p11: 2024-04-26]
Review_Material/ITW_Data_Samples/W3_Stairs_Summary.png

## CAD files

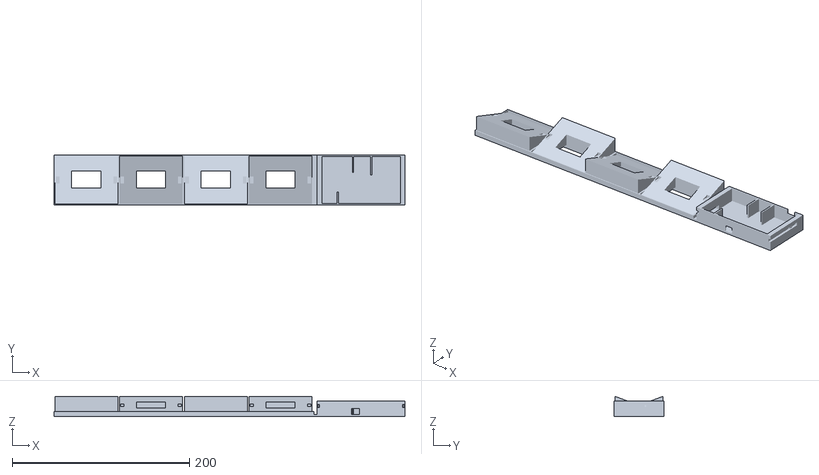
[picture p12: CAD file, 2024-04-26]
Hardware/3D_Enclosure/PCB_Housing_and_20_DegBody_Assembly.stl
395.9 x 56.0 x 22.8

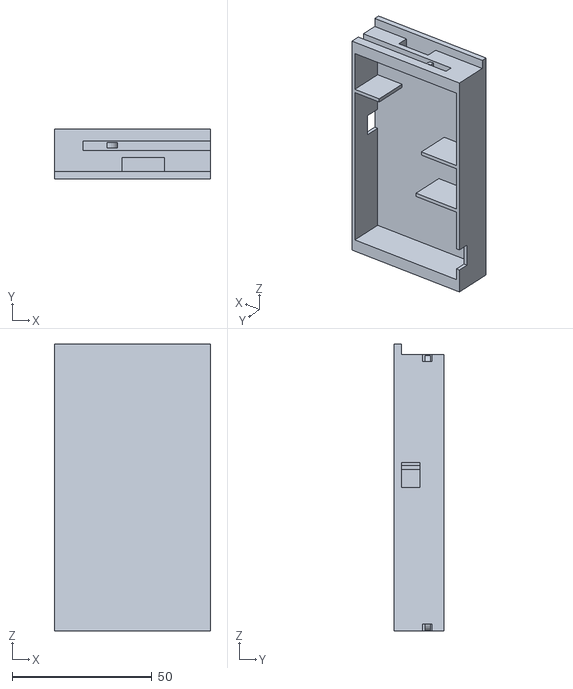
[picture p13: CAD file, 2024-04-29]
Hardware/3D_Enclosure/PCB_Housing.stl
56.0 x 17.8 x 102.9

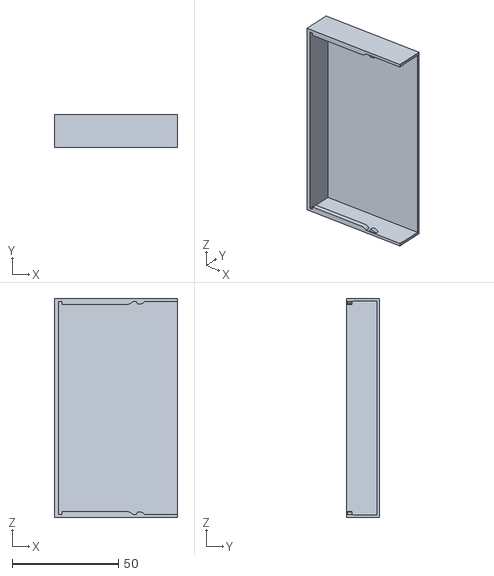
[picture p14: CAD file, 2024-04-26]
Hardware/3D_Enclosure/PCB_Housing_Cap.stl
58.0 x 15.3 x 103.1

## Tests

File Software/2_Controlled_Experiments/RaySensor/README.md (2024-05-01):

#### Intro
SensorControlExperiments.c is the firmware for the Ray Sensor to send a single packet for individual controlled events from its Radio_Module and CC1101 Radio provided there is enough energy available to do so.  Each packet will containing a sequence of the classified result as well as some feature data in the event that you want to infer why an event was a false positive etc.  Be sure to update the evaluate_event() method on line 395 with the equivalent decision tree code from the model that was trained previously.

#### Setup
1. Change the SUPPORT_FILE_DIRECTORY in the makefile to your msp430 gcc include
   path.
2. Hook up a MSP430FR5994 LaunchPad to your computer.
3. Connect the sensor to the Programmer pins on the launchpad (You may need to remove some jumpers to accomplish this) and plug them in to the appropriate programming pins on the MCU_Module.
4. Use "make install" to load the program into your device.
5. Detach from programmer and reconnect the PCB in the enclosure and you are ready to deploy.

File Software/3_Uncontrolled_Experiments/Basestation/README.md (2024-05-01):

#### Intro
This is the firmware for a base station to Receive packets using the CC1101 Radio with a MSP430FR994 launchpad.

#### Setup
1. Change the SUPPORT_FILE_DIRECTORY in the makefile to your msp430 gcc include
   path.
2. Hook up a MSP430FR5994 LaunchPad to your computer.
3. Use "make install" to load the program into your device.

#### Gathering Data
You can choose to grab the data direct from a serial port and direct it to a file or grab the information and send it to a database.  ITWbaystation.py is a python3 script that we would run on our basestation that the MSP430 Launchpad was connected to by USB to grab the data and send it to an SQL Database for later processing.  If you want to use this script you would need to update line 22 with the appropriate serial port, and lines 54-57 and 60-64 with appropriate values for your database and basestation ID if you have more than one basestation.

#### Commercial Sensor Comparison (EnOcean)
The folder EnOcean_Sensor_PacketDecoder contains 2 python scripts and instructions on their use to collect and decode the packets sent from the commercial sensor for later comparison with the our Sensor's data and Ground Truth.

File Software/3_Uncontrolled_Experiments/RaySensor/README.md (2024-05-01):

#### Intro
ITWDeploymentCode.c is the firmware for the Ray Sensor to send complete packets from its Radio_Module and CC1101 Radio provided there is enough energy available to do so.  Each packet will containing a sequence of 5 events, an estimate of their time between events, and history of the last two packets sent for redundancy.  This version of the code also includes sending heartbeat event when there has been no activity detected in approximately 2 minutes. Be sure to update the evaluate_event() method on line 453 with the equivalent decision tree code from the model that was trained previously.

#### Setup
1. Change the SUPPORT_FILE_DIRECTORY in the makefile to your msp430 gcc include
   path.
2. Hook up a MSP430FR5994 LaunchPad to your computer.
3. Connect the sensor to the Programmer pins on the launchpad (You may need to remove some jumpers to accomplish this) and plug them in to the appropriate programming pins on the MCU_Module.
4. Use "make install" to load the program into your device.
5. Detach from programmer and reconnect the PCB in the enclosure and you are ready to deploy.

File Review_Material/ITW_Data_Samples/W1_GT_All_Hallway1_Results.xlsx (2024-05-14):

Date/Time | Location | GT People Count/event | Category | Ground Truth Label | Description of ground truth if not simple in/out event | Sensor and GT agree | Multiple people same direction results | Waldo/Ray Classifiation | Detect ppl/event | EnOcean Detection
2022-12-09 06:52 | Hallway1 | 1 | 1 | in |  |  |  | pbi | 1 | hit | HW1
2022-12-09 06:53 | Hallway1 | 1 | 1 | out |  | out |  | out | 1 | miss |  | Total days | 11
2022-12-09 06:56 | Hallway1 | 1 | 1 | in |  | in |  | in | 1 | hit |  | total ppl | 452 |  | pkt num | 437
2022-12-09 07:08 | Hallway1 | 1 | 1 | out |  | out |  | out | 1 | hit |  | waldo saw | 434 | 96.01769912%
2022-12-09 07:09 | Hallway1 | 1 | 1 | in |  |  |  | pbi | 1 | miss |  | EnOcean saw | 304 | 67.25663717%
2022-12-09 07:43 | Hallway1 | 1 | 1 | out |  | out |  | out | 1 | hit
2022-12-09 07:45 | Hallway1 | 1 | 1 | in |  |  |  | pbi | 1 | hit |  | cat 1 | 399 | 91.30434783% |  | 99.77116705%
2022-12-09 07:46 | Hallway1 | 1 | 1 | in |  | in |  | in | 1 | miss |  | cat 2 | 16 | 3.661327231% |  | 436
2022-12-09 07:47 | Hallway1 | 1 | 1 | out | out, but slowly looking up at the camera (grace) | out |  | out | 1 | miss |  | cat 3 | 21 | 4.805491991%
2022-12-09 07:54 | Hallway1 | 1 | 1 | out |  | out |  | out | 1 | hit |  |  | GroundTruth | waldo correct
2022-12-09 08:20 | Hallway1 | 1 | 1 | out |  | out |  | out | 1 | hit |  | ins | 201 | 143 |  | 71.14427861%
2022-12-09 08:39 | Hallway1 | 1 | 1 | in |  | in |  | in | 1 | hit |  | outs | 190 | 182 |  | 95.78947368%
2022-12-09 08:39 | Hallway1 | 1 | 1 | out |  | out |  | out | 1 | miss |  | pbi/pbo | 8 | 4 |  | 50%
2022-12-09 08:40 | Hallway1 | 1 | 1 | in |  | in |  | in | 1 | miss
2022-12-09 08:45 | Hallway1 | 1 | 1 | in |  |  |  | pbi | 1 | hit |  | multiple in same direction results:
2022-12-09 08:48 | Hallway1 | 1 | 1 | out |  | out |  | out | 1 | hit |  | in/in | 9 | 8 |  | 88.88888889%
2022-12-09 08:56 | Hallway1 | 1 | 1 | in |  | in |  | in | 1 | hit |  | out/out | 7 | 6 |  | 85.71428571%
2022-12-09 08:57 | Hallway1 | 1 | 3 | pbout/in | kai goes into office |  |  | in | 1 | miss
2022-12-09 09:00 | Hallway1 | 1 | 3 | in/linger | student to kai's office |  |  | pbo/pbo | 1 | hit
2022-12-09 09:05 | Hallway1 | 1 | 1 | in | Sami comes in to office | in |  | in | 1 | hit
2022-12-09 09:19 | Hallway1 | 1 | 1 | out |  | out |  | out | 1 | hit
2022-12-09 09:25 | Hallway1 | 1 | 1 | out |  | out |  | out | 1 | hit
2022-12-09 09:28 | Hallway1 | 1 | 1 | out |  | out |  | out | 1 | hit
2022-12-09 09:32 | Hallway1 | 1 | 3 | out/linger | Sami leaves office then walks over to tutoring lab, about 7 seconds |  |  | pbo/pbo | 1 | hit
2022-12-09 09:33 | Hallway1 | 1 | 1 | in |  |  |  | pbi | 1 | miss
2022-12-09 09:37 | Hallway1 | 1 | 1 | out |  | out |  | out | 1 | hit
2022-12-09 09:43 | Hallway1 | 1 | 1 | out |  | out |  | out | 1 | hit
2022-12-09 09:45 | Hallway1 | 1 | 1 | in |  | in |  | in | 1 | hit
2022-12-09 09:48 | Hallway1 | 1 | 1 | in |  |  |  | pbi | 1 | hit
2022-12-09 09:57 | Hallway1 | 1 | 1 | in | student from last event exits in after closing the door |  |  | out | 1 | hit
2022-12-09 10:21 | Hallway1 | 1 | 1 | in |  |  |  | pbi | 1 | hit
2022-12-09 10:23 | Hallway1 | 1 | 1 | in |  | in |  | in | 1 | hit
2022-12-09 10:24 | Hallway1 | 1 | 1 | out |  | out |  | out | 1 | miss
2022-12-09 10:30 | Hallway1 | 1 | 1 | in |  | in |  | in | 1 | hit
2022-12-09 10:33 | Hallway1 | 1 | 1 | out |  | out |  | out | 1 | hit
2022-12-09 10:35 | Hallway1 | 1 | 1 | pbout | sami lingering outside of the tutoring room | pb |  | pbo | 1 | hit
2022-12-09 10:36 | Hallway1 | 1 | 3 | curiosity | sami walks under sensor from tutoring room, waves, then turns back to tutoring room |  |  | pbo | 1 | miss
2022-12-09 10:43 | Hallway1 | 1 | 1 | out |  | out |  | out | 1 | hit
2022-12-09 10:44 | Hallway1 | 1 | 1 | in |  | in |  | in | 1 | miss
2022-12-09 10:45 | Hallway1 | 1 | 1 | in |  | in |  | in | 1 | miss
2022-12-09 10:49 | Hallway1 | 1 | 1 | out |  | out |  | out | 1 | hit
2022-12-09 10:51 | Hallway1 | 1 | 1 | in |  | in |  | in | 1 | miss
2022-12-09 10:56 | Hallway1 | 1 | 1 | in |  |  |  | pbi | 1 | hit
2022-12-09 10:56 | Hallway1 | 1 | 1 | out |  | out |  | out | 1 | miss
2022-12-09 10:58 | Hallway1 | 1 | 1 | in |  | in |  | in | 1 | hit
2022-12-09 10:58 | Hallway1 | 1 | 1 | in |  | in |  | in | 1 | miss
2022-12-09 11:05 | Hallway1 | 2 | 2 | out/out | Sami and another person exit out together in quick succession |  | out | out | 1 | hit
2022-12-09 11:09 | Hallway1 | 1 | 1 | out |  | out |  | out | 1 | hit
2022-12-09 11:18 | Hallway1 | 1 | 1 | in |  | in |  | in | 1 | hit
2022-12-09 11:22 | Hallway1 | 1 | 1 | out |  | out |  | out | 1 | hit
2022-12-09 11:23 | Hallway1 | 1 | 1 | in |  |  |  | pbi | 1 | miss
2022-12-09 11:50 | Hallway1 | 1 | 1 | in |  | in |  | in | 1 | hit
2022-12-09 11:52 | Hallway1 | 1 | 1 | in |  |  |  | pbi | 1 | hit
2022-12-09 11:59 | Hallway1 | 1 | 1 | in |  |  |  | pbi | 1 | hit
2022-12-09 12:17 | Hallway1 | 1 | 1 | out |  | out |  | out | 1 | hit
2022-12-09 12:24 | Hallway1 | 1 | 1 | out |  | out |  | out | 1 | hit
2022-12-09 12:26 | Hallway1 | 1 | 1 | out |  | out |  | out | 1 | hit
2022-12-09 12:30 | Hallway1 | 1 | 1 | in |  |  |  | pbi | 1 | hit
2022-12-09 12:31 | Hallway1 | 1 | 1 | out |  | out |  | out | 1 | miss
2022-12-09 12:32 | Hallway1 | 1 | 1 | in |  |  |  | pbi | 1 | miss
2022-12-09 12:44 | Hallway1 | 1 | 1 | in |  | in |  | in | 1 | hit
2022-12-09 12:45 | Hallway1 | 1 | 1 | out |  | out |  | out | 1 | miss
2022-12-09 12:49 | Hallway1 | 1 | 1 | out |  | out |  | out | 1 | hit
2022-12-09 12:50 | Hallway1 | 1 | 1 | in |  | in |  | in | 1 | miss
2022-12-09 13:09 | Hallway1 | 1 | 1 | out |  | out |  | out | 1 | hit
2022-12-09 13:27 | Hallway1 | 1 | 1 | in |  | in |  | in | 1 | hit
2022-12-09 14:05 | Hallway1 | 1 | 1 | out |  | out |  | out | 1 | hit
2022-12-09 14:38 | Hallway1 | 1 | 1 | out |  |  |  | in | 1 | hit
2022-12-09 15:33 | Hallway1 | 1 | 1 | out |  | out |  | out | 1 | hit
2022-12-09 17:41 | Hallway1 | 1 | 1 | in |  |  |  | pbi | 1 | hit
2022-12-09 18:13 | Hallway1 | 1 | 1 | out | to tutoring room | out |  | out | 1 | hit
2022-12-09 18:53 | Hallway1 | 1 | 1 | in |  |  |  | pbi | 1 | hit
2022-12-09 18:54 | Hallway1 | 1 | 1 | out | to tutoring room | out |  | out | 1 | miss
2022-12-09 21:11 | Hallway1 | 1 | 1 | in |  |  |  | pbi | 1 | hit
2022-12-09 21:37 | Hallway1 | 1 | 1 | out |  | out |  | out | 1 | hit
2022-12-09 21:46 | Hallway1 | 1 | 1 | in |  | in |  | in | 1 | hit
2022-12-10 17:52 | Hallway1 | 1 | 1 | in |  | in |  | in | 1 | hit
2022-12-11 16:35 | Hallway1 | 1 | 1 | in |  |  |  | pbi | 1 | hit
2022-12-11 20:21 | Hallway1 | 1 | 1 | in |  | in |  | in | 1 | hit
2022-12-12 01:24 | Hallway1 | 1 | 1 | in |  | in |  | in | 1 | hit
2022-12-12 08:09 | Hallway1 | 1 | 1 | out |  | out |  | out | 1 | hit
2022-12-12 08:10 | Hallway1 | 1 | 1 | in |  | in |  | in | 1 | miss
2022-12-12 08:10 | Hallway1 | 1 | 1 | out |  | out |  | out | 1 | miss
2022-12-12 08:11 | Hallway1 | 1 | 1 | in |  | in |  | in | 1 | hit
2022-12-12 08:12 | Hallway1 | 1 | 1 | out |  | out |  | out | 1 | miss
2022-12-12 08:17 | Hallway1 | 1 | 1 | in |  | in |  | in | 1 | hit
2022-12-12 09:43 | Hallway1 | 1 | 3 | in/linger | janitor passing slowly in for a good 15 seconds sweeping as he passes |  |  | in/in | 1 | hit
2022-12-12 09:44 | Hallway1 | 1 | 1 | out | janitor passes back through and stops on edge of gt video view | out |  | out | 1 | miss
2022-12-12 09:46 | Hallway1 | 1 | 1 | out |  | out |  | out | 1 | hit
2022-12-12 09:51 | Hallway1 | 1 | 1 | in |  |  |  | pbi | 1 | hit
2022-12-12 09:52 | Hallway1 | 1 | 1 | out |  | out |  | out | 1 | miss
2022-12-12 09:54 | Hallway1 | 1 | 1 | in |  | in |  | in | 1 | hit
2022-12-12 10:21 | Hallway1 | 1 | 1 | in |  |  |  | pbi | 1 | hit
2022-12-12 10:32 | Hallway1 | 1 | 1 | out |  | out |  | out | 1 | hit
2022-12-12 10:35 | Hallway1 | 1 | 1 | out |  | out |  | out | 1 | hit
2022-12-12 10:36 | Hallway1 | 1 | 1 | in |  | in |  | in | 1 | miss
2022-12-12 11:02 | Hallway1 | 1 | 1 | in |  | in |  | in | 1 | miss
2022-12-12 11:03 | Hallway1 | 1 | 1 | in | Elliott starts to come in then stops under the sensor and then proceeds in, about 8 seconds | in |  | in | 1 | hit
2022-12-12 11:18 | Hallway1 | 1 | 1 | out |  | out |  | out | 1 | hit
2022-12-12 11:19 | Hallway1 | 1 | 1 | in |  | in |  | in | 1 | miss
2022-12-12 11:20 | Hallway1 | 1 | 1 | out |  | out |  | out | 1 | hit
2022-12-12 11:20 | Hallway1 | 1 | 1 | in |  | in |  | in | 1 | miss
2022-12-12 11:21 | Hallway1 | 1 | 1 | out |  | out |  | out | 1 | miss
2022-12-12 11:22 | Hallway1 | 1 | 1 | in |  |  |  | pbi | 1 | hit
2022-12-12 11:22 | Hallway1 | 1 | 1 | out |  | out |  | out | 1 | miss
2022-12-12 11:25 | Hallway1 | 1 | 1 | in |  |  |  | pbi | 1 | hit
2022-12-12 11:27 | Hallway1 | 1 | 1 | out |  | out |  | out | 1 | hit
2022-12-12 11:27 | Hallway1 | 1 | 1 | in |  |  |  | pbi | 1 | miss
2022-12-12 11:41 | Hallway1 | 1 | 1 | out |  | out |  | out | 1 | hit
2022-12-12 11:42 | Hallway1 | 1 | 1 | in |  |  |  | pbi | 1 | miss
2022-12-12 11:49 | Hallway1 | 1 | 1 | out |  | out |  | out | 1 | hit
2022-12-12 11:59 | Hallway1 | 1 | 1 | in |  | in |  | in | 1 | hit
2022-12-12 12:14 | Hallway1 | 1 | 1 | in |  | in |  | in | 1 | hit
2022-12-12 12:15 | Hallway1 | 1 | 1 | out |  | out |  | out | 1 | miss
2022-12-12 12:17 | Hallway1 | 1 | 1 | out |  | out |  | out | 1 | hit
2022-12-12 12:22 | Hallway1 | 1 | 1 | in |  |  |  | pbi | 1 | hit
2022-12-12 12:36 | Hallway1 | 1 | 1 | out |  | out |  | out | 1 | hit
2022-12-12 12:37 | Hallway1 | 1 | 1 | in |  |  |  | pbi | 1 | miss
2022-12-12 13:07 | Hallway1 | 1 | 1 | out |  | out |  | out | 1 | hit
2022-12-12 13:09 | Hallway1 | 1 | 1 | in |  | in |  | in | 1 | miss
2022-12-12 13:09 | Hallway1 | 1 | 1 | in |  | in |  | in | 1 | hit
2022-12-12 13:09 | Hallway1 | 1 | 1 | out |  | out |  | out | 1 | miss
2022-12-12 13:11 | Hallway1 | 1 | 3 | uturn | in then switch back to out |  |  | pbo | 1 | miss
2022-12-12 13:13 | Hallway1 | 1 | 1 | out |  | out |  | out | 1 | hit
2022-12-12 13:16 | Hallway1 | 1 | 1 | in |  | in |  | in | 1 | hit
2022-12-12 13:46 | Hallway1 | 1 | 1 | out |  | out |  | out | 1 | hit
2022-12-12 13:46 | Hallway1 | 1 | 1 | out |  | out |  | out | 1 | miss
2022-12-12 13:48 | Hallway1 | 1 | 1 | in |  | in |  | in | 1 | hit
2022-12-12 13:52 | Hallway1 | 1 | 1 | out |  | out |  | out | 1 | hit
2022-12-12 13:53 | Hallway1 | 1 | 1 | in |  |  |  | pbi | 1 | miss
2022-12-12 14:01 | Hallway1 | 1 | 1 | in |  | in |  | in | 1 | hit
2022-12-12 14:02 | Hallway1 | 1 | 1 | out |  | out |  | out | 1 | miss
2022-12-12 14:11 | Hallway1 | 1 | 1 | out | slow | out |  | out | 1 | hit
2022-12-12 14:11 | Hallway1 | 1 | 1 | in |  |  |  | pbi | 1 | miss
2022-12-12 14:20 | Hallway1 | 1 | 1 | in |  | in |  | in | 1 | hit
2022-12-12 14:21 | Hallway1 | 1 | 1 | out |  | out |  | out | 1 | miss
2022-12-12 14:41 | Hallway1 | 1 | 1 | out |  | out |  | out | 1 | hit
2022-12-12 14:48 | Hallway1 | 2 | 2 | out/out | two people walk out in succession, one a second after the other |  |  | pbo | 1 | hit
2022-12-12 14:50 | Hallway1 | 2 | 2 | in/in | two people walk in in succession, one a second after the other |  | in | in | 1 | hit
2022-12-12 15:03 | Hallway1 | 1 | 1 | out |  | out |  | out | 1 | hit
2022-12-12 15:04 | Hallway1 | 1 | 1 | in |  |  |  | pbi | 1 | miss
2022-12-12 15:26 | Hallway1 | 1 | 1 | out |  | out |  | out | 1 | hit
2022-12-12 15:28 | Hallway1 | 1 | 1 | in |  |  |  | pbi | 1 | hit
2022-12-12 16:15 | Hallway1 | 1 | 1 | out |  |  |  | pbi | 1 | hit
2022-12-12 16:16 | Hallway1 | 1 | 1 | in |  | in |  | in | 1 | miss
2022-12-12 16:22 | Hallway1 | 1 | 1 | out |  | out |  | out | 1 | miss
2022-12-12 16:22 | Hallway1 | 1 | 1 | in |  |  |  | pbi | 1 | miss
2022-12-12 16:54 | Hallway1 | 1 | 1 | in |  | in |  | in | 1 | hit
2022-12-12 18:50 | Hallway1 | 1 | 1 | in |  | in |  | in | 1 | hit
2022-12-12 18:53 | Hallway1 | 1 | 1 | out |  | out |  | out | 1 | hit
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

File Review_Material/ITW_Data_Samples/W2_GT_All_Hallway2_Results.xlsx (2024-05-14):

Date/Time | Location | GT People Count/event | Category | Ground Truth Label | Description of ground truth if not simple in/out event | Sensor and GT agree | Multiple people same direction results | Waldo/Ray Classifiation | Detect ppl/event | EnOcean Detection
2022-12-09 06:52 | Hallway2 | 1 | 1 | in |  | in |  | in | 1 | hit | HW2
2022-12-09 06:53 | Hallway2 | 1 | 1 | out |  |  |  | pbo | 1 | miss |  | Total days | 10 |  | pkt | 924
2022-12-09 06:56 | Hallway2 | 1 | 1 | in |  | in |  | in | 1 | hit |  | total ppl | 961
2022-12-09 07:09 | Hallway2 | 1 | 3 | uturn | out just enough to toss trash then back in |  |  | in | 1 | hit |  | waldo saw | 925 | 96.25390219%
2022-12-09 07:43 | Hallway2 | 1 | 1 | out |  |  |  | pbo | 1 | hit |  | EnOcean saw | 613 | 63.78772112%
2022-12-09 07:45 | Hallway2 | 1 | 1 | in |  | in |  | in | 1 | miss
2022-12-09 07:46 | Hallway2 | 1 | 1 | in |  | in |  | in | 1 | hit |  | cat 1 | 824 | 89.17748918% |  | 99.89177489%
2022-12-09 07:54 | Hallway2 | 1 | 1 | out |  |  |  | pbo | 1 | hit |  | cat 2 | 36 | 3.896103896%
2022-12-09 08:06 | Hallway2 | 1 | 1 | out |  | out |  | out | 1 | hit |  | cat 3 | 63 | 6.818181818%
2022-12-09 08:10 | Hallway2 | 1 | 1 | in |  | in |  | in | 1 | hit |  |  | GroundTruth | waldo correct
2022-12-09 08:27 | Hallway2 | 1 | 1 | in |  | in |  | in | 1 | hit |  | ins | 426 | 423 |  | 99.29577465%
2022-12-09 08:32 | Hallway2 | 1 | 1 | out |  |  |  | pbo | 1 | hit |  | outs | 388 | 300 |  | 77.31958763%
2022-12-09 08:38 | Hallway2 | 1 | 1 | out | jacob | out |  | out | 1 | hit |  | pbi/pbo | 10 | 6 |  | 60%
2022-12-09 08:38 | Hallway2 | 1 | 1 | in |  | in |  | in | 1 | miss
2022-12-09 08:39 | Hallway2 | 1 | 1 | out |  | out |  | out | 1 | miss |  | multiple in same direction results:
2022-12-09 08:40 | Hallway2 | 1 | 1 | in |  | in |  | in | 1 | hit |  | in/in | 15 | 14 |  | 93.33333333%
2022-12-09 08:45 | Hallway2 | 1 | 1 | in |  | in |  | in | 1 | hit |  | out/out | 21 | 19 |  | 90.47619048%
2022-12-09 08:48 | Hallway2 | 1 | 1 | out |  |  |  | pbo | 1 | hit
2022-12-09 08:56 | Hallway2 | 1 | 1 | in |  | in |  | in | 1 | hit
2022-12-09 08:57 | Hallway2 | 1 | 1 | in |  | in |  | in | 1 | miss
2022-12-09 08:58 | Hallway2 | 1 | 1 | in |  | in |  | in | 1 | hit
2022-12-09 09:01 | Hallway2 | 1 | 1 | out |  | out |  | out | 1 | hit
2022-12-09 09:03 | Hallway2 | 1 | 1 | out |  |  |  | pbo | 1 | miss
2022-12-09 09:05 | Hallway2 | 1 | 1 | in |  | in |  | in | 1 | hit
2022-12-09 09:06 | Hallway2 | 1 | 1 | in |  | in |  | in | 1 | miss
2022-12-09 09:19 | Hallway2 | 1 | 1 | out |  | out |  | out | 1 | hit
2022-12-09 09:33 | Hallway2 | 1 | 1 | in |  | in |  | in | 1 | hit
2022-12-09 09:33 | Hallway2 | 1 | 1 | out |  | out |  | out | 1 | miss
2022-12-09 09:36 | Hallway2 | 1 | 1 | in |  | in |  | in | 1 | hit
2022-12-09 09:37 | Hallway2 | 1 | 1 | out |  | out |  | out | 1 | miss
2022-12-09 09:43 | Hallway2 | 1 | 1 | out |  | out |  | out | 1 | hit
2022-12-09 09:45 | Hallway2 | 1 | 1 | in |  | in |  | in | 1 | hit
2022-12-09 09:48 | Hallway2 | 1 | 1 | in | slowly, messing with bookbag | in |  | in | 1 | hit
2022-12-09 09:52 | Hallway2 | 1 | 1 | in |  | in |  | in | 1 | hit
2022-12-09 09:53 | Hallway2 | 1 | 1 | out |  | out |  | out | 1 | miss
2022-12-09 10:03 | Hallway2 | 1 | 1 | out |  | out |  | out | 1 | hit
2022-12-09 10:35 | Hallway2 | 1 | 3 | uturn | dropping off trash then back in, then back again |  |  | in | 1 | hit
2022-12-09 10:43 | Hallway2 | 1 | 3 | uturn | dropping off trash then back in |  |  | pbi | 1 | hit
2022-12-09 10:44 | Hallway2 | 1 | 3 | pbout/linger/in | linger on pbout, then trash, then finally in |  |  | in/in | 1 | miss
2022-12-09 10:49 | Hallway2 | 1 | 1 | out |  | out |  | out | 1 | hit
2022-12-09 10:51 | Hallway2 | 1 | 1 | in |  | in |  | in | 1 | hit
2022-12-09 10:51 | Hallway2 | 1 | 1 | out |  | out |  | out | 1 | miss
2022-12-09 10:56 | Hallway2 | 1 | 1 | in |  | in |  | in | 1 | hit
2022-12-09 11:05 | Hallway2 | 2 | 2 | out/out | two people, both traveling out in close succession |  | out | out | 1 | hit
2022-12-09 11:09 | Hallway2 | 1 | 1 | out |  |  |  | pbo | 1 | hit
2022-12-09 11:18 | Hallway2 | 1 | 1 | in |  | in |  | in | 1 | hit
2022-12-09 11:22 | Hallway2 | 1 | 1 | out |  | out |  | out | 1 | hit
2022-12-09 11:23 | Hallway2 | 1 | 1 | in |  | in |  | in | 1 | miss
2022-12-09 11:49 | Hallway2 | 1 | 1 | in |  | in |  | in | 1 | hit
2022-12-09 11:59 | Hallway2 | 1 | 1 | in |  | in |  | in | 1 | hit
2022-12-09 12:10 | Hallway2 | 1 | 3 | out/pbout/in | messing with the trashcan for a good 30 seconds |  |  | out/pbo/pbo/in | 1 | hit
2022-12-09 12:17 | Hallway2 | 1 | 1 | out |  | out |  | out | 1 | hit
2022-12-09 12:24 | Hallway2 | 1 | 1 | out |  |  |  | in | 1 | hit
2022-12-09 12:29 | Hallway2 | 1 | 1 | out |  | out |  | out | 1 | hit
2022-12-09 12:30 | Hallway2 | 1 | 1 | in | slowly, messing with recycling | in |  | in | 1 | miss
2022-12-09 12:30 | Hallway2 | 1 | 1 | in |  | in |  | in | 1 | miss
2022-12-09 12:31 | Hallway2 | 1 | 1 | out |  | out |  | out | 1 | hit
2022-12-09 12:32 | Hallway2 | 1 | 1 | in |  | in |  | in | 1 | miss
2022-12-09 12:32 | Hallway2 | 1 | 1 | in |  | in |  | in | 1 | miss
2022-12-09 12:33 | Hallway2 | 1 | 1 | out |  | out |  | out | 1 | miss
2022-12-09 12:44 | Hallway2 | 1 | 1 | in |  | in |  | in | 1 | hit
2022-12-09 12:45 | Hallway2 | 1 | 1 | out |  | out |  | out | 1 | miss
2022-12-09 12:49 | Hallway2 | 1 | 1 | out |  | out |  | out | 1 | hit
2022-12-09 12:50 | Hallway2 | 1 | 1 | in |  | in |  | in | 1 | miss
2022-12-09 12:52 | Hallway2 | 1 | 1 | out |  | out |  | out | 1 | hit
2022-12-09 12:58 | Hallway2 | 1 | 1 | in |  | in |  | in | 1 | hit
2022-12-09 13:09 | Hallway2 | 1 | 1 | out |  | out |  | out | 1 | hit
2022-12-09 13:24 | Hallway2 | 1 | 1 | out |  | out |  | out | 1 | hit
2022-12-09 13:27 | Hallway2 | 1 | 1 | in |  | in |  | in | 1 | hit
2022-12-09 13:29 | Hallway2 | 1 | 1 | in |  | in |  | in | 1 | hit
2022-12-09 13:46 | Hallway2 | 1 | 1 | in |  | in |  | in | 1 | hit
2022-12-09 13:49 | Hallway2 | 1 | 3 | out/pbout | out, slowly messing with the trash then continuing out |  |  | pbo | 1 | hit
2022-12-09 13:54 | Hallway2 | 1 | 3 | pbout/in/pbin | janitor mopping out side of door, walking in, then mopping inside of door for a good 15 seconds |  |  | pbo/pbo | 1 | hit | *
2022-12-09 14:05 | Hallway2 | 1 | 1 | out |  | out |  | out | 1 | hit
2022-12-09 14:38 | Hallway2 | 1 | 1 | out |  | out |  | out | 1 | hit
2022-12-09 21:37 | Hallway2 | 1 | 1 | out |  | out |  | out | 1 | hit
2022-12-09 21:46 | Hallway2 | 1 | 1 | in | trash, then in | in |  | in | 1 | hit
2022-12-10 17:52 | Hallway2 | 1 | 1 | in | normal in | in |  | in | 1 | hit
2022-12-11 14:13 | Hallway2 | 1 | 1 | out |  | out |  | out | 1 | hit
2022-12-11 16:34 | Hallway2 | 1 | 1 | in |  | in |  | in | 1 | hit
2022-12-11 18:49 | Hallway2 | 1 | 1 | in |  | in |  | in | 1 | hit
2022-12-11 20:21 | Hallway2 | 1 | 1 | in |  | in |  | in | 1 | hit
2022-12-12 01:14 | Hallway2 | 1 | 1 | out |  |  |  | pbi | 1 | hit
2022-12-12 01:24 | Hallway2 | 1 | 1 | in |  | in |  | in | 1 | hit
2022-12-12 07:37 | Hallway2 | 1 | 1 | in |  | in |  | in | 1 | hit
2022-12-12 07:42 | Hallway2 | 1 | 1 | out |  | out |  | out | 1 | hit
2022-12-12 07:46 | Hallway2 | 1 | 1 | in |  | in |  | in | 1 | hit
2022-12-12 07:57 | Hallway2 | 1 | 1 | in |  | in |  | in | 1 | hit
2022-12-12 08:02 | Hallway2 | 1 | 1 | out |  |  |  | pbo | 1 | hit
2022-12-12 08:09 | Hallway2 | 1 | 1 | out | jacob | out |  | out | 1 | hit
2022-12-12 08:10 | Hallway2 | 1 | 1 | in | jacob | in |  | in | 1 | miss
2022-12-12 08:10 | Hallway2 | 1 | 1 | out | jacob | out |  | out | 1 | miss
2022-12-12 08:11 | Hallway2 | 1 | 1 | in | jacob | in |  | in | 1 | hit
2022-12-12 08:12 | Hallway2 | 1 | 1 | out | jacob |  |  | pbo | 1 | miss
2022-12-12 08:17 | Hallway2 | 1 | 1 | in | jacob | in |  | in | 1 | hit
2022-12-12 08:55 | Hallway2 | 1 | 1 | in |  | in |  | in | 1 | hit
2022-12-12 08:58 | Hallway2 | 1 | 1 | in |  | in |  | in | 1 | hit
2022-12-12 09:02 | Hallway2 | 2 | 2 | out/out | two people walk out together |  | out | out | 1 | hit
2022-12-12 09:09 | Hallway2 | 1 | 1 | out |  | out |  | out | 1 | hit
2022-12-12 09:14 | Hallway2 | 1 | 1 | in |  | in |  | in | 1 | hit
2022-12-12 09:20 | Hallway2 | 1 | 1 | in |  | in |  | in | 1 | hit
2022-12-12 09:23 | Hallway2 | 1 | 1 | out |  | out |  | out | 1 | hit
2022-12-12 09:23 | Hallway2 | 2 | 2 | in/in | two people walk in together one right after the other |  | in | in | 1 | miss
2022-12-12 09:24 | Hallway2 | 1 | 3 | out/Linger | out/linger with one person and another joins to exit them going out |  |  | out/out | 1 | miss
2022-12-12 09:42 | Hallway2 | 1 | 1 | in |  | in |  | in | 1 | hit
2022-12-12 09:47 | Hallway2 | 1 | 1 | out |  | out |  | out | 1 | hit
2022-12-12 09:50 | Hallway2 | 1 | 1 | in |  | in |  | in | 1 | hit
2022-12-12 09:52 | Hallway2 | 1 | 1 | out |  | out |  | out | 1 | miss
2022-12-12 09:52 | Hallway2 | 1 | 3 | out/pbout | walked out to sweep then stopped |  |  | pbo/pbo | 1 | miss
2022-12-12 09:54 | Hallway2 | 1 | 1 | in |  | in |  | in | 1 | hit
2022-12-12 09:55 | Hallway2 | 1 | 1 | out |  |  |  | pbo | 1 | miss
2022-12-12 09:55 | Hallway2 | 1 | 1 | in |  | in |  | in | 1 | miss
2022-12-12 09:57 | Hallway2 | 1 | 3 | uturn | out for a second and back in |  |  | pbi | 1 | hit
2022-12-12 10:00 | Hallway2 | 1 | 1 | in |  | in |  | in | 1 | hit
2022-12-12 10:01 | Hallway2 | 1 | 1 | out |  | out |  | out | 1 | miss
2022-12-12 10:05 | Hallway2 | 1 | 1 | in |  | in |  | in | 1 | hit
2022-12-12 10:09 | Hallway2 | 1 | 1 | out |  |  |  | pbo | 1 | hit
2022-12-12 10:18 | Hallway2 | 1 | 1 | out |  | out |  | out | 1 | hit
2022-12-12 10:19 | Hallway2 | 1 | 1 | in |  | in |  | in | 1 | miss
2022-12-12 10:21 | Hallway2 | 1 | 1 | in |  | in |  | in | 1 | hit
2022-12-12 10:32 | Hallway2 | 1 | 1 | out |  | out |  | out | 1 | hit
2022-12-12 10:35 | Hallway2 | 1 | 1 | out |  | out |  | out | 1 | hit
2022-12-12 10:36 | Hallway2 | 1 | 1 | in |  | in |  | in | 1 | miss
2022-12-12 10:47 | Hallway2 | 1 | 1 | out |  | out |  | out | 1 | hit
2022-12-12 10:51 | Hallway2 | 1 | 1 | in |  | in |  | in | 1 | hit
2022-12-12 11:24 | Hallway2 | 1 | 1 | in |  | in |  | in | 1 | hit
2022-12-12 11:27 | Hallway2 | 1 | 1 | out |  | out |  | out | 1 | hit
2022-12-12 11:27 | Hallway2 | 1 | 1 | in |  | in |  | in | 1 | miss
2022-12-12 11:27 | Hallway2 | 1 | 1 | in |  | in |  | in | 1 | miss
2022-12-12 11:28 | Hallway2 | 1 | 1 | out |  | out |  | out | 1 | miss
2022-12-12 11:36 | Hallway2 | 1 | 1 | in | janitor walking in slowly with a cart, about 6 seconds | in |  | in | 1 | hit
2022-12-12 11:39 | Hallway2 | 1 | 1 | in |  | in |  | in | 1 | hit
2022-12-12 11:39 | Hallway2 | 1 | 1 | out | janitor walking out slowly with a cart, about 6 seconds | out |  | out | 1 | miss
2022-12-12 11:40 | Hallway2 | 1 | 1 | out |  | out |  | out | 1 | miss
2022-12-12 11:41 | Hallway2 | 1 | 1 | out |  | out |  | out | 1 | hit
2022-12-12 11:41 | Hallway2 | 1 | 1 | in |  | in |  | in | 1 | miss
2022-12-12 11:49 | Hallway2 | 1 | 1 | out |  | out |  | out | 1 | hit
2022-12-12 11:58 | Hallway2 | 1 | 1 | in |  | in |  | in | 1 | hit
2022-12-12 11:58 | Hallway2 | 1 | 1 | in |  | in |  | in | 1 | miss
2022-12-12 12:04 | Hallway2 | 1 | 1 | in |  | in |  | in | 1 | hit
2022-12-12 12:05 | Hallway2 | 1 | 1 | out |  | out |  | out | 1 | miss
2022-12-12 12:08 | Hallway2 | 1 | 1 | in |  | in |  | in | 1 | hit
2022-12-12 12:15 | Hallway2 | 1 | 1 | out |  | out |  | out | 1 | hit
2022-12-12 12:17 | Hallway2 | 1 | 1 | out |  |  |  | pbo | 1 | hit
2022-12-12 12:21 | Hallway2 | 1 | 1 | in |  | in |  | in | 1 | hit
2022-12-12 12:31 | Hallway2 | 1 | 1 | in |  | in |  | in | 1 | hit
2022-12-12 12:32 | Hallway2 | 1 | 1 | out |  | out |  | out | 1 | miss
2022-12-12 12:36 | Hallway2 | 1 | 1 | out |  |  |  | pbo | 1 | hit
2022-12-12 12:37 | Hallway2 | 1 | 1 | in |  | in |  | in | 1 | miss
2022-12-12 12:44 | Hallway2 | 1 | 1 | in |  | in |  | in | 1 | hit
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

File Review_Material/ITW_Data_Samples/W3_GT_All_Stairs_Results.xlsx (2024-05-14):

Date/Time | Location | GT People Count/event | Category | Ground Truth Label | Description of ground truth if not simple in/out event | Sensor and GT agree | Multiple people same direction results | Waldo/Ray Classifiation | Detect ppl/event | EnOcean Detection
2023-01-10 16:42 | Stairs | 1 | 1 | in |  | in |  | in | 1 |  | Stairs
2023-01-10 16:46 | Stairs | 1 | 1 | out |  | out |  | out | 1 |  |  | Total days | 11
2023-01-10 16:46 | Stairs | 1 | 1 | in |  | in |  | in | 1 |  |  | total ppl | 1489 |  | pkt num | 1068 | Total Subsection | 422
2023-01-10 16:47 | Stairs | 1 | 1 | pbin |  | pb |  | pbi | 1 |  |  | waldo saw | 1144 | 76.83008731% |  |  | Waldo subsection | 308 | 72.98578199%
2023-01-10 16:47 | Stairs | 1 | 1 | out |  | out |  | out | 1 |  |  | EnOcean saw | 174 |  |  |  | EnOcean | 174 | 41.23222749%
2023-01-10 16:47 | Stairs | 1 | 1 | in |  |  |  | pbo | 1
2023-01-10 16:47 | Stairs | 3 | 2 | in/in | three people walk in one after the other after the other, 6 seconds |  | in | in | 1 |  |  | cat 1 | 882 | 82.58426966% |  | 99.90636704% | cat1-pb | 796 | 74.5%
2023-01-10 16:47 | Stairs | 1 | 1 | out |  | out |  | out | 1 |  |  | cat 2 | 151 | 14.13857678% |  | 1067
2023-01-10 16:47 | Stairs | 1 | 1 | in |  | in |  | in | 1 |  |  | cat 3 | 34 | 3.183520599% |  |  | cat3+pb | 120 | 11.2%
2023-01-10 16:48 | Stairs | 1 | 1 | out |  | out |  | out | 1 |  |  |  | GroundTruth | waldo correct
2023-01-10 16:48 | Stairs | 1 | 1 | in |  | in |  | in | 1 |  |  | ins | 505 | 462 |  | 91.48514851%
2023-01-10 16:48 | Stairs | 1 | 1 | out |  | out |  | out | 1 |  |  | outs | 291 | 257 |  | 88.3161512%
2023-01-10 16:49 | Stairs | 1 | 1 | in |  | in |  | in | 1 |  |  | pbi/pbo | 86 | 67 |  | 77.90697674%
2023-01-10 16:49 | Stairs | 1 | 1 | out |  | out |  | out | 1
2023-01-10 16:49 | Stairs | 1 | 1 | in |  | in |  | in | 1 |  |  | multiple in same direction results:
2023-01-10 17:06 | Stairs | 2 | 2 | in/in | two people walk in one after the other after the other, 6 seconds |  | in | in | 1 | hit |  | in/in | 89 | 63 |  | 70.78651685%
2023-01-10 17:22 | Stairs | 1 | 1 | out |  | out |  | out | 1 | hit |  | out/out | 62 | 27 |  | 43.5483871%
2023-01-10 17:41 | Stairs | 3 | 2 | in/in | three people walk in one after the other after the other, 6 seconds |  | in | in | 1 | hit
2023-01-10 17:46 | Stairs | 4 | 2 | out/out | four folks walk out one, a second later three more back to back to back, about 10 seconds |  | out | out | 1 | hit
2023-01-10 17:47 | Stairs | 2 | 2 | in/in | two people walk in one after the other after the other, 7 seconds |  | in | in | 1 | miss
2023-01-10 17:49 | Stairs | 2 | 2 | out/out | two people walk out one after the other after the other, 7 seconds |  | out | out | 1 | hit
2023-01-10 17:54 | Stairs | 1 | 1 | out |  | out |  | out | 1 | hit
2023-01-10 19:44 | Stairs | 1 | 1 | in |  | in |  | in | 1 | hit
2023-01-10 19:45 | Stairs | 1 | 1 | in |  | in |  | in | 1 | miss
2023-01-10 19:45 | Stairs | 1 | 1 | in |  | in |  | in | 1 | miss
2023-01-11 01:55 | Stairs | 1 | 1 | in |  | in |  | in | 1 | hit
2023-01-11 06:49 | Stairs | 1 | 1 | out |  | out |  | out | 1 | hit
2023-01-11 06:51 | Stairs | 1 | 1 | in |  | in |  | in | 1 | miss
2023-01-11 07:34 | Stairs | 1 | 1 | out |  | out |  | out | 1 | hit
2023-01-11 07:40 | Stairs | 1 | 1 | in |  | in |  | in | 1 | hit
2023-01-11 07:41 | Stairs | 1 | 1 | out |  | out |  | out | 1 | miss
2023-01-11 08:11 | Stairs | 1 | 1 | in |  | in |  | in | 1 | hit
2023-01-11 08:18 | Stairs | 1 | 1 | in |  | in |  | in | 1 | hit
2023-01-11 08:27 | Stairs | 1 | 1 | in |  | in |  | in | 1 | hit
2023-01-11 08:30 | Stairs | 1 | 1 | in | entering amy's lab, about 8 seconds | in |  | in | 1 | hit
2023-01-11 08:34 | Stairs | 1 | 1 | in |  | in |  | in | 1 | hit
2023-01-11 08:40 | Stairs | 1 | 1 | out | out from prior event | out |  | out | 1 | hit
2023-01-11 08:41 | Stairs | 1 | 1 | in |  | in |  | in | 1 | miss
2023-01-11 08:42 | Stairs | 1 | 1 | out |  | out |  | out | 1 | hit
2023-01-11 08:47 | Stairs | 1 | 1 | out |  | out |  | out | 1 | hit
2023-01-11 08:52 | Stairs | 1 | 1 | in |  | in |  | in | 1 | hit
2023-01-11 08:57 | Stairs | 1 | 1 | in |  | in |  | in | 1 | hit
2023-01-11 08:59 | Stairs | 1 | 1 | in |  | in |  | in | 1 | hit
2023-01-11 09:01 | Stairs | 1 | 1 | in |  | in |  | in | 1 | miss
2023-01-11 09:11 | Stairs | 1 | 1 | out |  | out |  | out | 1 | hit
2023-01-11 09:28 | Stairs | 1 | 1 | in |  | in |  | in | 1 | hit
2023-01-11 09:30 | Stairs | 4 | 2 | in/in | in to amy's lab, pause to open door, then followed closely by 3 others, about 9 seconds |  |  | in/in | 2 | hit
2023-01-11 09:39 | Stairs | 1 | 1 | in |  |  |  | pbo | 1 | hit
2023-01-11 09:41 | Stairs | 1 | 1 | in |  | in |  | in | 1 | miss
2023-01-11 09:42 | Stairs | 1 | 1 | out |  |  |  | pbo | 1 | hit
2023-01-11 09:44 | Stairs | 1 | 1 | in |  | in |  | in | 1 | hit
2023-01-11 09:51 | Stairs | 2 | 2 | out/out | two people exit together slowly |  | out | out | 1 | hit
2023-01-11 09:56 | Stairs | 2 | 2 | in/in |  |  | in | in | 1 | hit
2023-01-11 09:57 | Stairs | 1 | 1 | pbin |  | pb |  | pbi | 1 | miss
2023-01-11 09:58 | Stairs | 2 | 2 | in/in | two people walk in one after the other, about 7 seconds |  | in | in | 1 | miss
2023-01-11 09:59 | Stairs | 1 | 1 | in |  | in |  | in | 1 | hit
2023-01-11 10:01 | Stairs | 2 | 2 | in/in | two people walk in together, one is crazy tall, about 9 seconds |  | in | in | 1 | hit
2023-01-11 10:01 | Stairs | 1 | 1 | in |  | in |  | in | 1 | miss
2023-01-11 10:02 | Stairs | 1 | 1 | in |  | in |  | in | 1 | miss
2023-01-11 10:03 | Stairs | 1 | 1 | out |  | out |  | out | 1 | miss
2023-01-11 10:04 | Stairs | 1 | 1 | in |  | in |  | in | 1 | hit
2023-01-11 10:05 | Stairs | 1 | 1 | in |  | in |  | in | 1 | hit
2023-01-11 10:05 | Stairs | 2 | 2 | in/in | two people walk in one after the other, about 6 seconds |  | in | in | 1 | miss
2023-01-11 10:05 | Stairs | 1 | 1 | out |  |  |  | in | 1 | miss
2023-01-11 10:06 | Stairs | 1 | 1 | in |  | in |  | in | 1 | miss
2023-01-11 10:10 | Stairs | 1 | 1 | in |  | in |  | in | 1 | hit
2023-01-11 10:21 | Stairs | 1 | 1 | in |  | in |  | in | 1 | hit
2023-01-11 10:22 | Stairs | 1 | 1 | out |  | out |  | out | 1 | miss
2023-01-11 10:27 | Stairs | 4 | 2 | out/out | four people come out of amy's lab back to back, about 8 seconds |  | out | out | 1 | hit
2023-01-11 10:29 | Stairs | 1 | 1 | in |  | in |  | in | 1 | hit
2023-01-11 10:30 | Stairs | 1 | 1 | in |  | in |  | in | 1 | miss
2023-01-11 10:31 | Stairs | 1 | 1 | out | about 5 seconds | out |  | out | 1 | hit
2023-01-11 10:32 | Stairs | 1 | 1 | in | in to amy's lab, pause by door | in |  | in | 1 | miss
2023-01-11 10:33 | Stairs | 1 | 1 | pbin | someone else comes out of Amy's lab then walks down the hall | pb |  | pbi | 1 | miss
2023-01-11 10:35 | Stairs | 1 | 1 | pbin | person comes back to amy's lab | pb |  | pbi | 1 | hit
2023-01-11 10:38 | Stairs | 1 | 1 | out |  | out |  | out | 1 | hit
2023-01-11 10:38 | Stairs | 6 | 2 | out/out | 6 people walk out one after the other, about 15 seconds |  |  | pbi/pbo | 2 | miss
2023-01-11 10:38 | Stairs | 1 | 1 | out |  |  |  | in | 1 | miss
2023-01-11 10:43 | Stairs | 1 | 1 | pbin | someone comes out of amy's lab | pb |  | pbi | 1 | hit
2023-01-11 10:43 | Stairs | 1 | 1 | in |  |  |  | pbo | 1 | miss
2023-01-11 10:50 | Stairs | 1 | 1 | pbin | person comes back to amy's lab | pb |  | pbi | 1 | hit
2023-01-11 10:51 | Stairs | 1 | 1 | in |  | in |  | in | 1 | miss
2023-01-11 10:52 | Stairs | 1 | 1 | out |  | out |  | out | 1 | hit
2023-01-11 10:55 | Stairs | 1 | 1 | out |  | out |  | out | 1 | hit
2023-01-11 10:55 | Stairs | 2 | 2 | in/in | two people come in a bit spread out but in around 6 seconds |  | in | in | 1 | miss
2023-01-11 11:05 | Stairs | 1 | 1 | in |  |  |  | pbo | 1 | hit
2023-01-11 11:06 | Stairs | 2 | 2 | in/in |  |  | in | in | 1 | miss
2023-01-11 11:06 | Stairs | 1 | 1 | in |  | in |  | in | 1 | miss
2023-01-11 11:07 | Stairs | 1 | 1 | in |  | in |  | in | 1 | hit
2023-01-11 11:07 | Stairs | 1 | 1 | out |  | out |  | out | 1 | miss
2023-01-11 11:08 | Stairs | 1 | 1 | in |  | in |  | in | 1 | miss
2023-01-11 11:08 | Stairs | 1 | 1 | in |  | in |  | in | 1 | miss
2023-01-11 11:09 | Stairs | 1 | 1 | out |  | out |  | out | 1 | hit
2023-01-11 11:11 | Stairs | 1 | 1 | in |  | in |  | in | 1 | miss
2023-01-11 11:13 | Stairs | 1 | 1 | in |  | in |  | in | 1 | hit
2023-01-11 11:13 | Stairs | 1 | 1 | in |  | in |  | in | 1 | miss
2023-01-11 11:18 | Stairs | 1 | 1 | out |  | out |  | out | 1 | hit
2023-01-11 11:27 | Stairs | 1 | 1 | pbin |  | pb |  | pbi | 1 | hit
2023-01-11 11:29 | Stairs | 1 | 1 | pbin |  | pb |  | pbi | 1 | hit
2023-01-11 11:41 | Stairs | 1 | 1 | in |  | in |  | in | 1 | hit
2023-01-11 11:42 | Stairs | 1 | 1 | out | came out of amy's lab | out |  | out | 1 | miss
2023-01-11 11:45 | Stairs | 1 | 1 | in | came in to amy's lab | in |  | in | 1 | hit
2023-01-11 11:52 | Stairs | 1 | 1 | out | came out of amy's lab | out |  | out | 1 | hit
2023-01-11 11:54 | Stairs | 3 | 2 | out/out | one person exits, probably counts as it's own out, then two people come out together, about 10 seconds |  |  | in/in | 2 | hit
2023-01-11 11:54 | Stairs | 7 | 2 | out/out | seven people go out back to back to back, about 13 seconds |  |  | in | 1 | miss
2023-01-11 11:56 | Stairs | 1 | 1 | out | out with a bit of a pause before continuing out, about 3 seconds | out |  | out | 1 | hit
2023-01-11 12:03 | Stairs | 2 | 2 | in/in | two people come in back to back, about 6 seconds |  | in | in | 1 | hit
2023-01-11 12:05 | Stairs | 1 | 1 | out |  | out |  | out | 1 | hit
2023-01-11 12:07 | Stairs | 1 | 1 | in |  | in |  | in | 1 | hit
2023-01-11 12:10 | Stairs | 1 | 1 | in |  | in |  | in | 1 | hit
2023-01-11 12:23 | Stairs | 1 | 1 | in |  | in |  | in | 1 | hit
2023-01-11 12:35 | Stairs | 1 | 1 | in | slowly stops under the sensor to check out the cards on the floor, about 8 seconds | in |  | in | 1 | miss
2023-01-11 12:35 | Stairs | 1 | 1 | in |  | in |  | in | 1 | miss
2023-01-11 12:38 | Stairs | 1 | 1 | in | in to amy's lab, pause by door | in |  | in | 1 | hit
2023-01-11 12:38 | Stairs | 1 | 1 | pbin | out of amy's lab to down the hall | pb |  | pbi | 1 | miss
2023-01-11 12:40 | Stairs | 1 | 1 | pbin | back into amy's lab | pb |  | pbi | 1 | hit
2023-01-11 12:43 | Stairs | 1 | 1 | out | out of amy's lab to out | out |  | out | 1 | hit
2023-01-11 12:52 | Stairs | 1 | 1 | in | in to amy's lab, pause by door | in |  | in | 1 | hit
2023-01-11 12:58 | Stairs | 1 | 1 | in |  |  |  | pbo | 1 | hit
2023-01-11 12:59 | Stairs | 1 | 1 | out | out of amy's lab to out | out |  | out | 1 | miss
2023-01-11 13:01 | Stairs | 1 | 1 | out |  | out |  | out | 1 | hit
2023-01-11 13:05 | Stairs | 1 | 1 | out |  | out |  | out | 1 | hit
2023-01-11 13:14 | Stairs | 1 | 1 | in |  | in |  | in | 1 | hit
2023-01-11 13:27 | Stairs | 1 | 1 | in |  | in |  | in | 1 | hit
2023-01-11 13:43 | Stairs | 1 | 1 | in |  | in |  | in | 1 | hit
2023-01-11 13:44 | Stairs | 1 | 1 | out |  | out |  | out | 1 | miss
2023-01-11 13:55 | Stairs | 1 | 1 | in |  | in |  | in | 1 | hit
2023-01-11 14:02 | Stairs | 1 | 1 | in |  | in |  | in | 1 | hit
2023-01-11 14:05 | Stairs | 1 | 1 | out |  | out |  | out | 1 | hit
2023-01-11 14:07 | Stairs | 1 | 1 | in |  | in |  | in | 1 | hit
2023-01-11 14:10 | Stairs | 1 | 1 | out |  | out |  | out | 1 | hit
2023-01-11 14:12 | Stairs | 1 | 1 | out |  | out |  | out | 1 | hit
2023-01-11 14:14 | Stairs | 1 | 1 | in |  | in |  | in | 1 | miss
2023-01-11 14:15 | Stairs | 1 | 1 | in |  | in |  | in | 1 | hit
2023-01-11 14:16 | Stairs | 1 | 1 | in |  | in |  | in | 1 | miss
2023-01-11 14:19 | Stairs | 1 | 1 | in |  | in |  | in | 1 | hit
2023-01-11 14:19 | Stairs | 2 | 2 | in/in | two people come in back to back, about 6 seconds |  | in | in | 1 | miss
2023-01-11 14:20 | Stairs | 1 | 1 | in |  | in |  | in | 1 | miss
2023-01-11 14:21 | Stairs | 1 | 1 | in |  | in |  | in | 1 | hit
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

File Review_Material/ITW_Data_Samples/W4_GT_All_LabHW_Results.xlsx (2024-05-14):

Date/Time | Location | GT People Count/event | Category | Ground Truth Label | Description of ground truth if not simple in/out event | Sensor and GT agree | Multiple people same direction results | Waldo/Ray Classifiation | Detect ppl/event | EnOcean Detection
2023-01-10 16:42 | LabHW | 1 | 1 | out |  | out |  | out | 1 | hit
2023-01-10 16:42 | LabHW | 1 | 1 | in |  | in |  | in | 1 | miss | LabHW
2023-01-10 16:45 | LabHW | 1 | 1 | out |  | out |  | out | 1 | hit |  | Total days | 11 |  | NumPkts | 1071
2023-01-10 16:46 | LabHW | 1 | 1 | in |  | in |  | in | 1 | miss |  | total ppl | 1440
2023-01-10 16:46 | LabHW | 1 | 1 | out |  | out |  | out | 1 | miss |  | waldo saw | 1107 | 76.875%
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

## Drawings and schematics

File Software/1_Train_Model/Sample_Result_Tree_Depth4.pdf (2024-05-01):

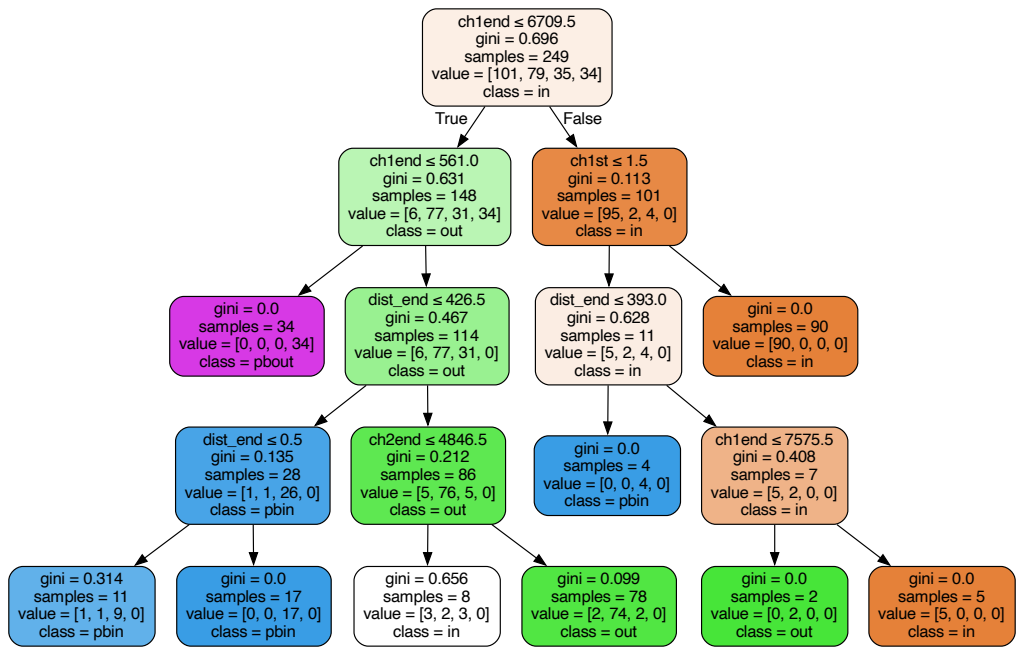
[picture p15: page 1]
ch1end ≤ 6709.5 gini = 0.696 samples = 249 value = [101, 79, 35, 34] class = in; ch1end ≤ 561.0 gini = 0.631 samples = 148 value = [6, 77, 31, 34] class = out; True; ch1st ≤ 1.5 gini = 0.113 samples = 101 value = [95, 2, 4, 0] class = in; False; gini = 0.0 samples = 34 value = [0, 0, 0, 34] class = pbout; dist_end ≤ 426.5 gini = 0.467 samples = 114 value = [6, 77, 31, 0] class = out; dist_end ≤ 0.5 gini = 0.135 samples = 28 value = [1, 1, 26, 0] class = pbin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

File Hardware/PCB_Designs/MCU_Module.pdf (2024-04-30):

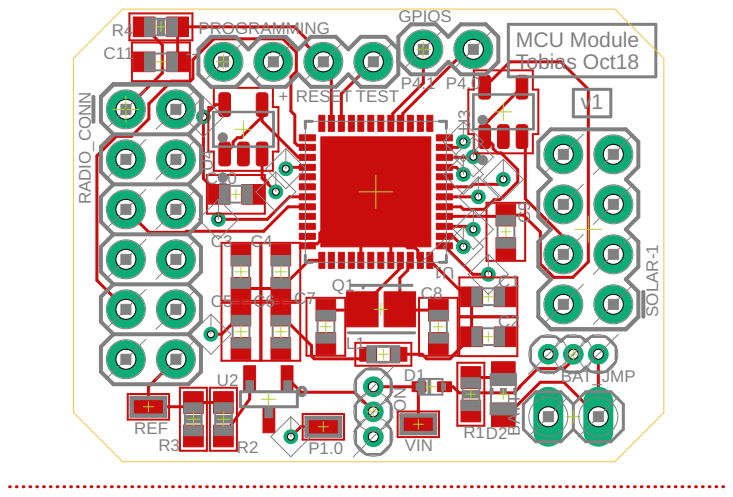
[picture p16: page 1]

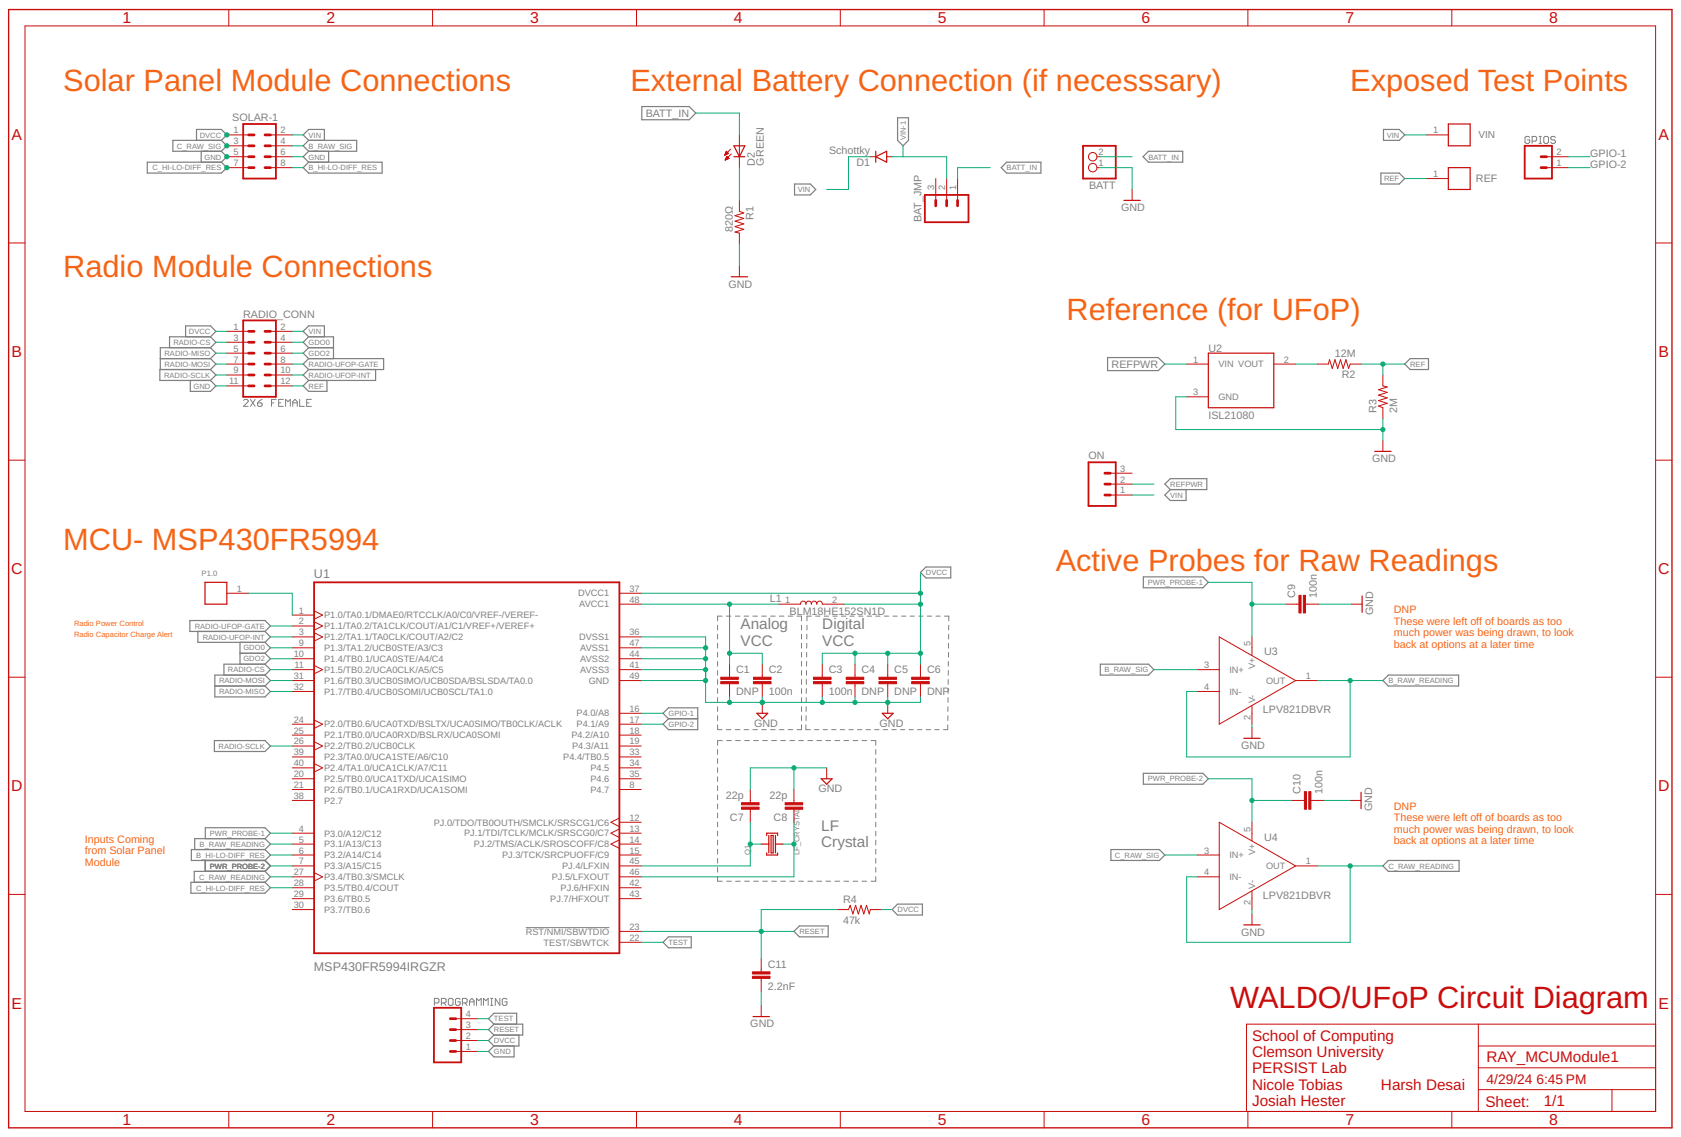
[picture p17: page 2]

Solar Panel Module Connections

External Battery Connection (if necesssary)

37 DVSS1
48 AVSS2 36 | BLM18HE152SN1D Analog VCC VCC Digital

DNP
These were left off of boards as too much power was being drawn, to look back at options at a later time

Radio Power Control Radio Capacitor Charge Alert

LF_CRYSTAL 100n 100n DNP DNP GND GND

12 PJ.1/TDI/TCLK/MCLK/SRSCG0/C7
13 PJ.2/TMS/ACLK/SROSCOFF/C8
14 PJ.3/TCK/SRCPUOFF/C9

Inputs Coming
from Solar Panel Module

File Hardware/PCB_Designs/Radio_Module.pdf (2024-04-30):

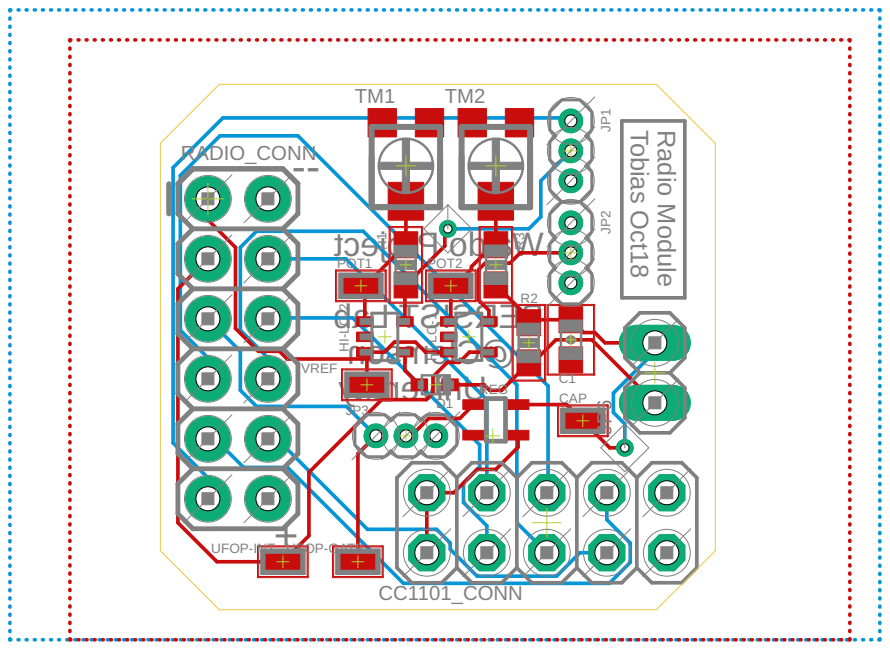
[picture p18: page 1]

UFOP-INT UFOP-GATE

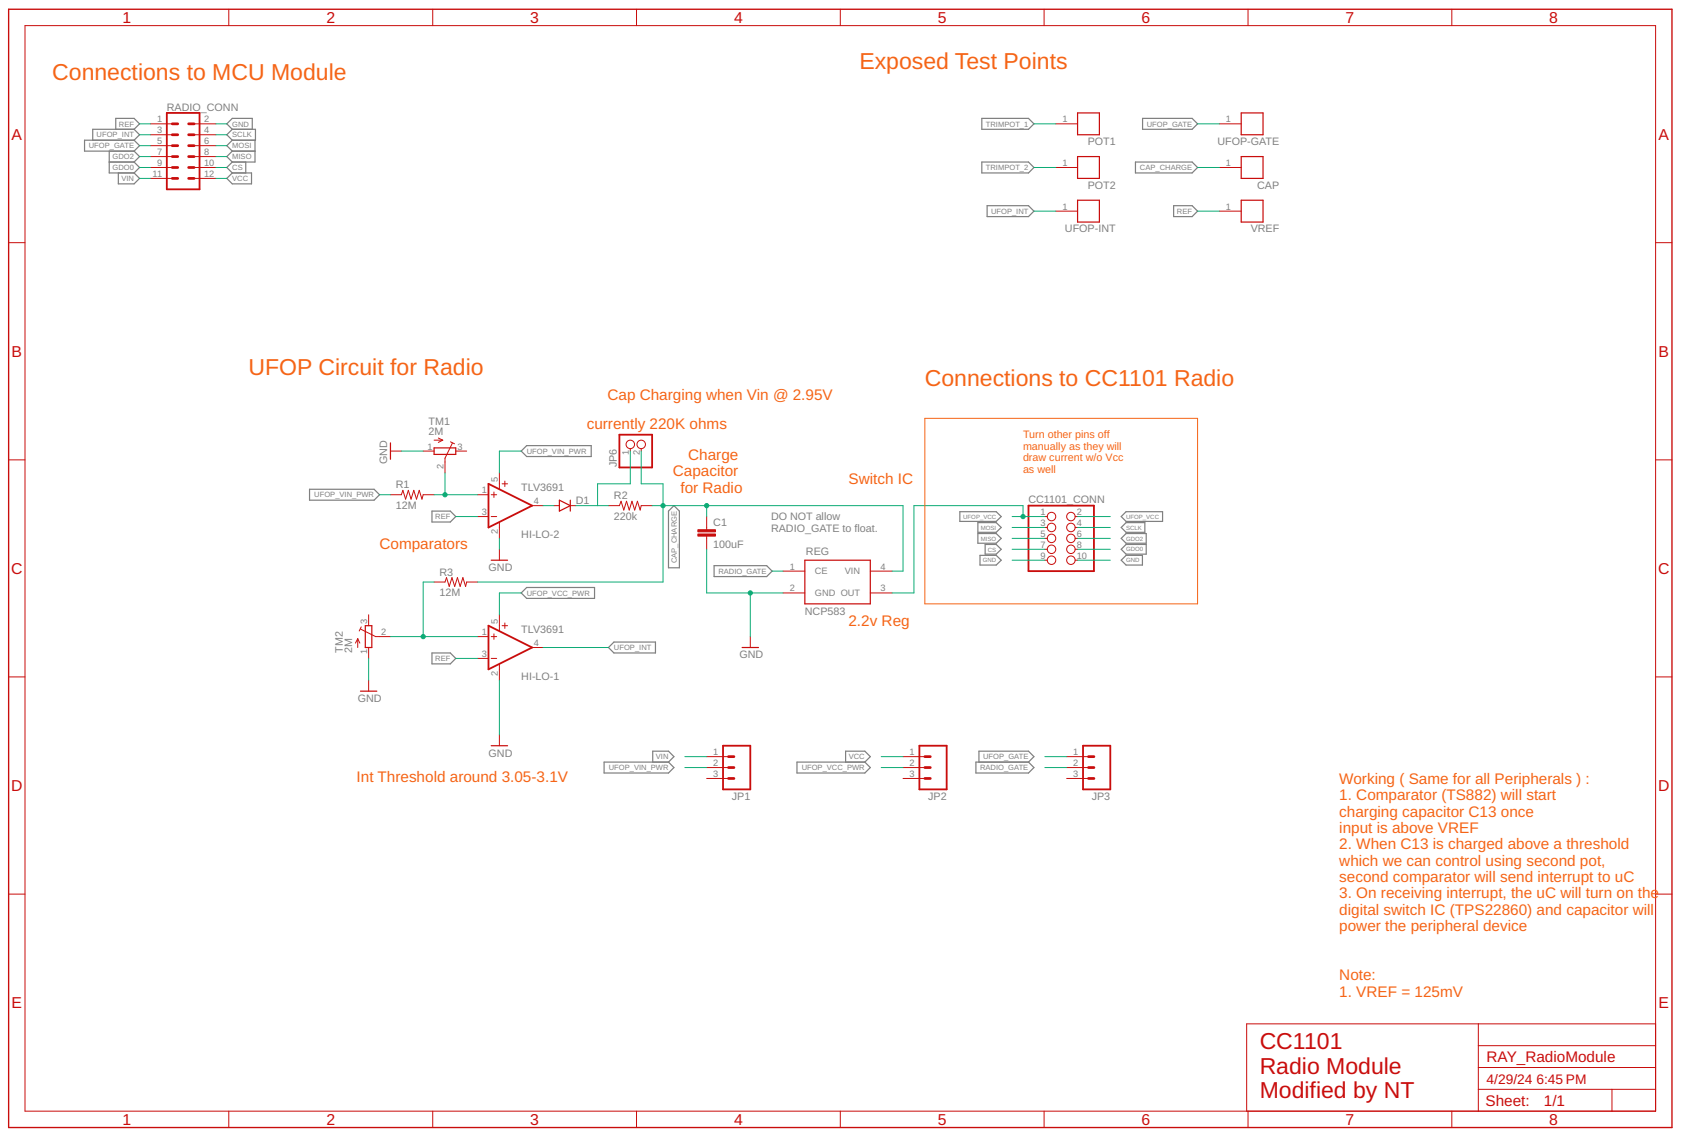
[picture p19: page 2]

UFOP Circuit for Radio

Cap Charging when Vin @ 2.95V

Working ( Same for all Peripherals ) : 1. Comparator (TS882) will start charging capacitor C13 once

input is above VREF
2. When C13 is charged above a threshold which we can control using second pot, second comparator will send interrupt to uC

3. On receiving interrupt, the uC will turn on the
digital switch IC (TPS22860) and capacitor will power the peripheral device

CC1101 Radio Module

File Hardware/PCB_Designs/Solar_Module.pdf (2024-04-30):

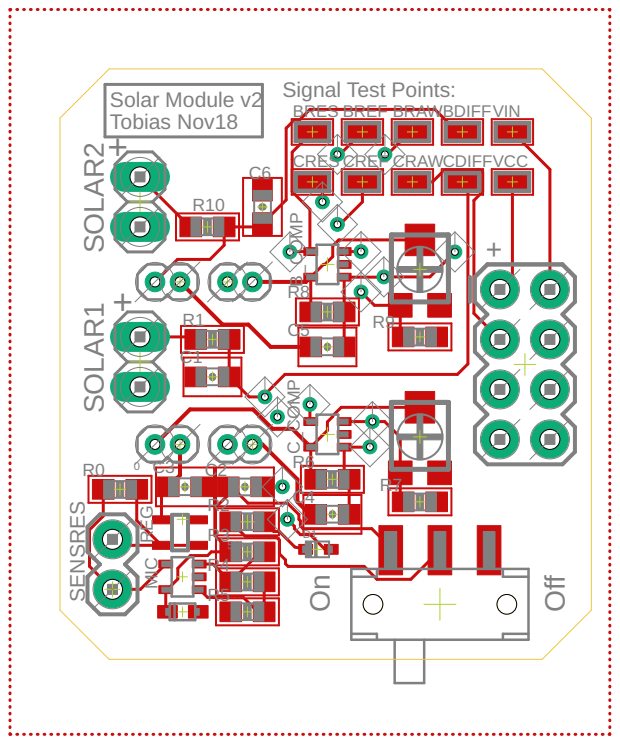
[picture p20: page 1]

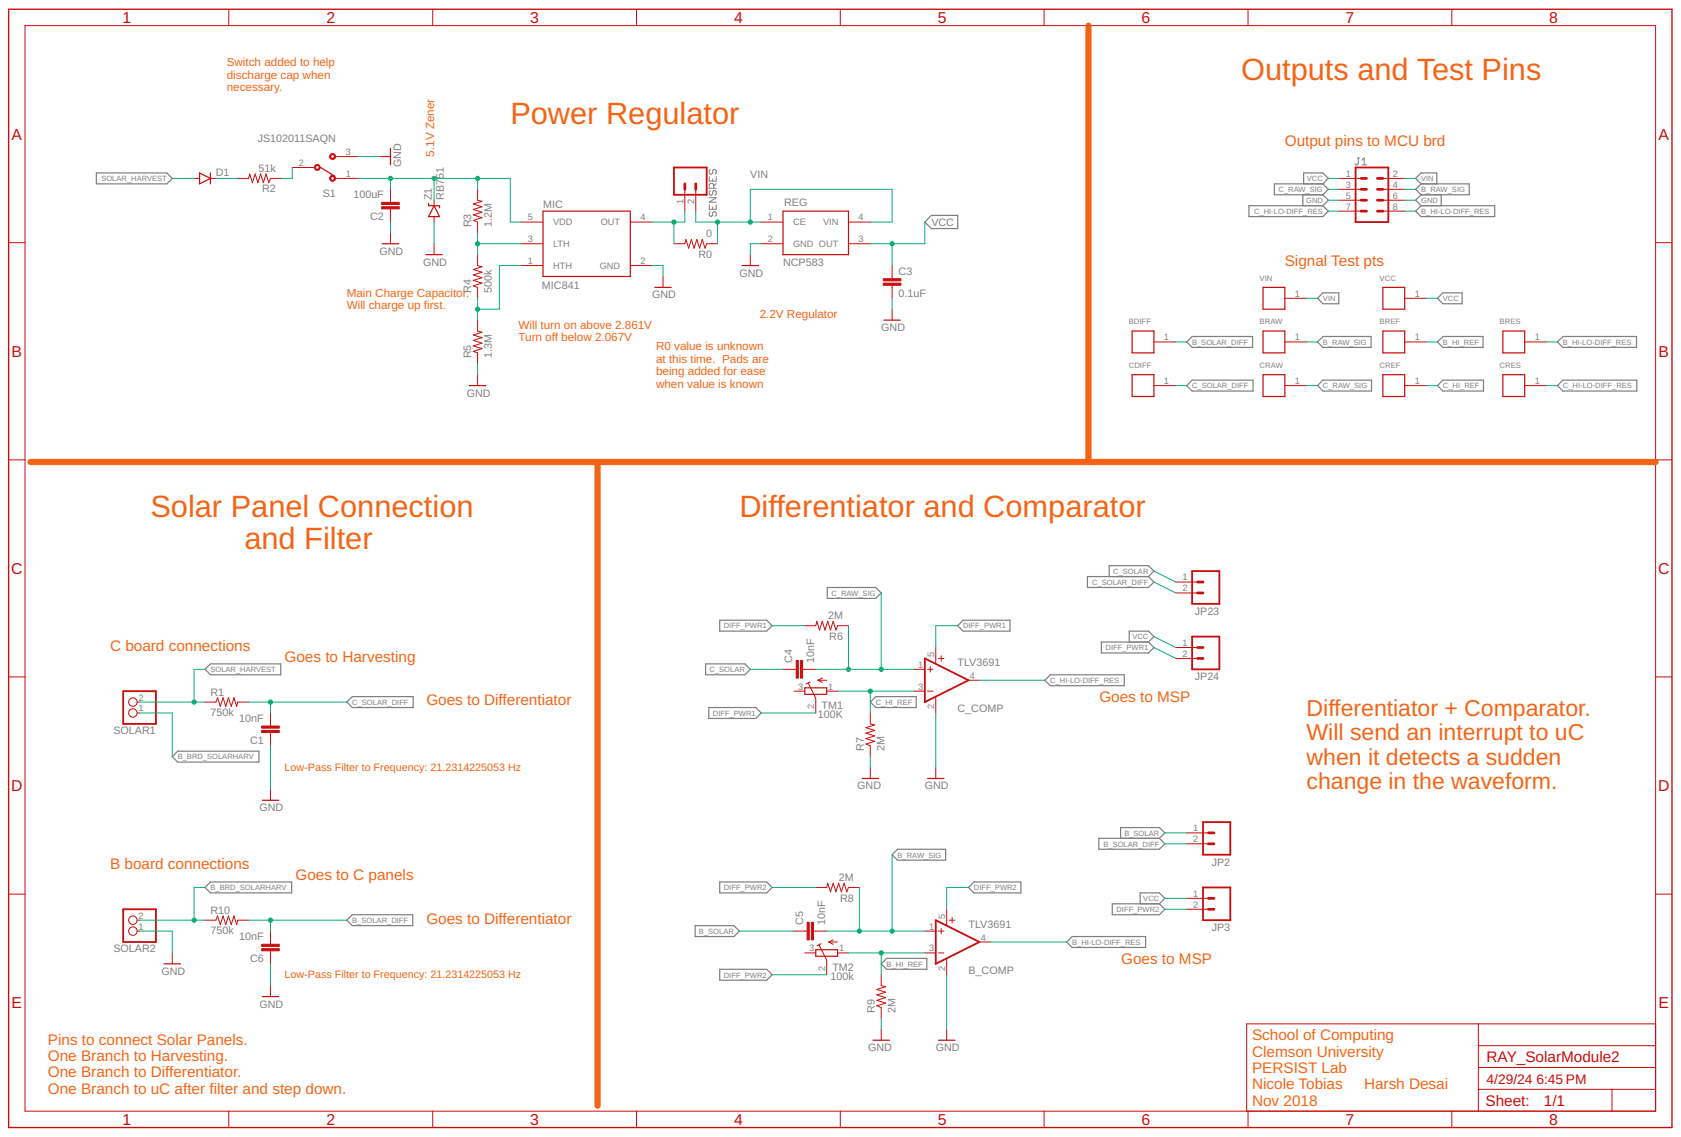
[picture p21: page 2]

Switch added to help discharge cap when necessary. Power Regulator | Outputs and Test Pins

5.1V Zener Will turn on above 2.861V

Output pins to MCU brd Signal Test pts

Main Charge Capacitor. Will charge up first.

R0 value is unknown
at this time. Pads are
being added for ease when value is known

change in the waveform. Goes to Differentiator

when it detects a sudden

Low-Pass Filter to Frequency: 21.2314225053 Hz

Pins to connect Solar Panels. One Branch to Harvesting. One Branch to Differentiator. One Branch to uC after filter and step down.

School of Computing Clemson University PERSIST Lab Nicole Tobias Harsh Desai Nov 2018

Sheet: 1/1

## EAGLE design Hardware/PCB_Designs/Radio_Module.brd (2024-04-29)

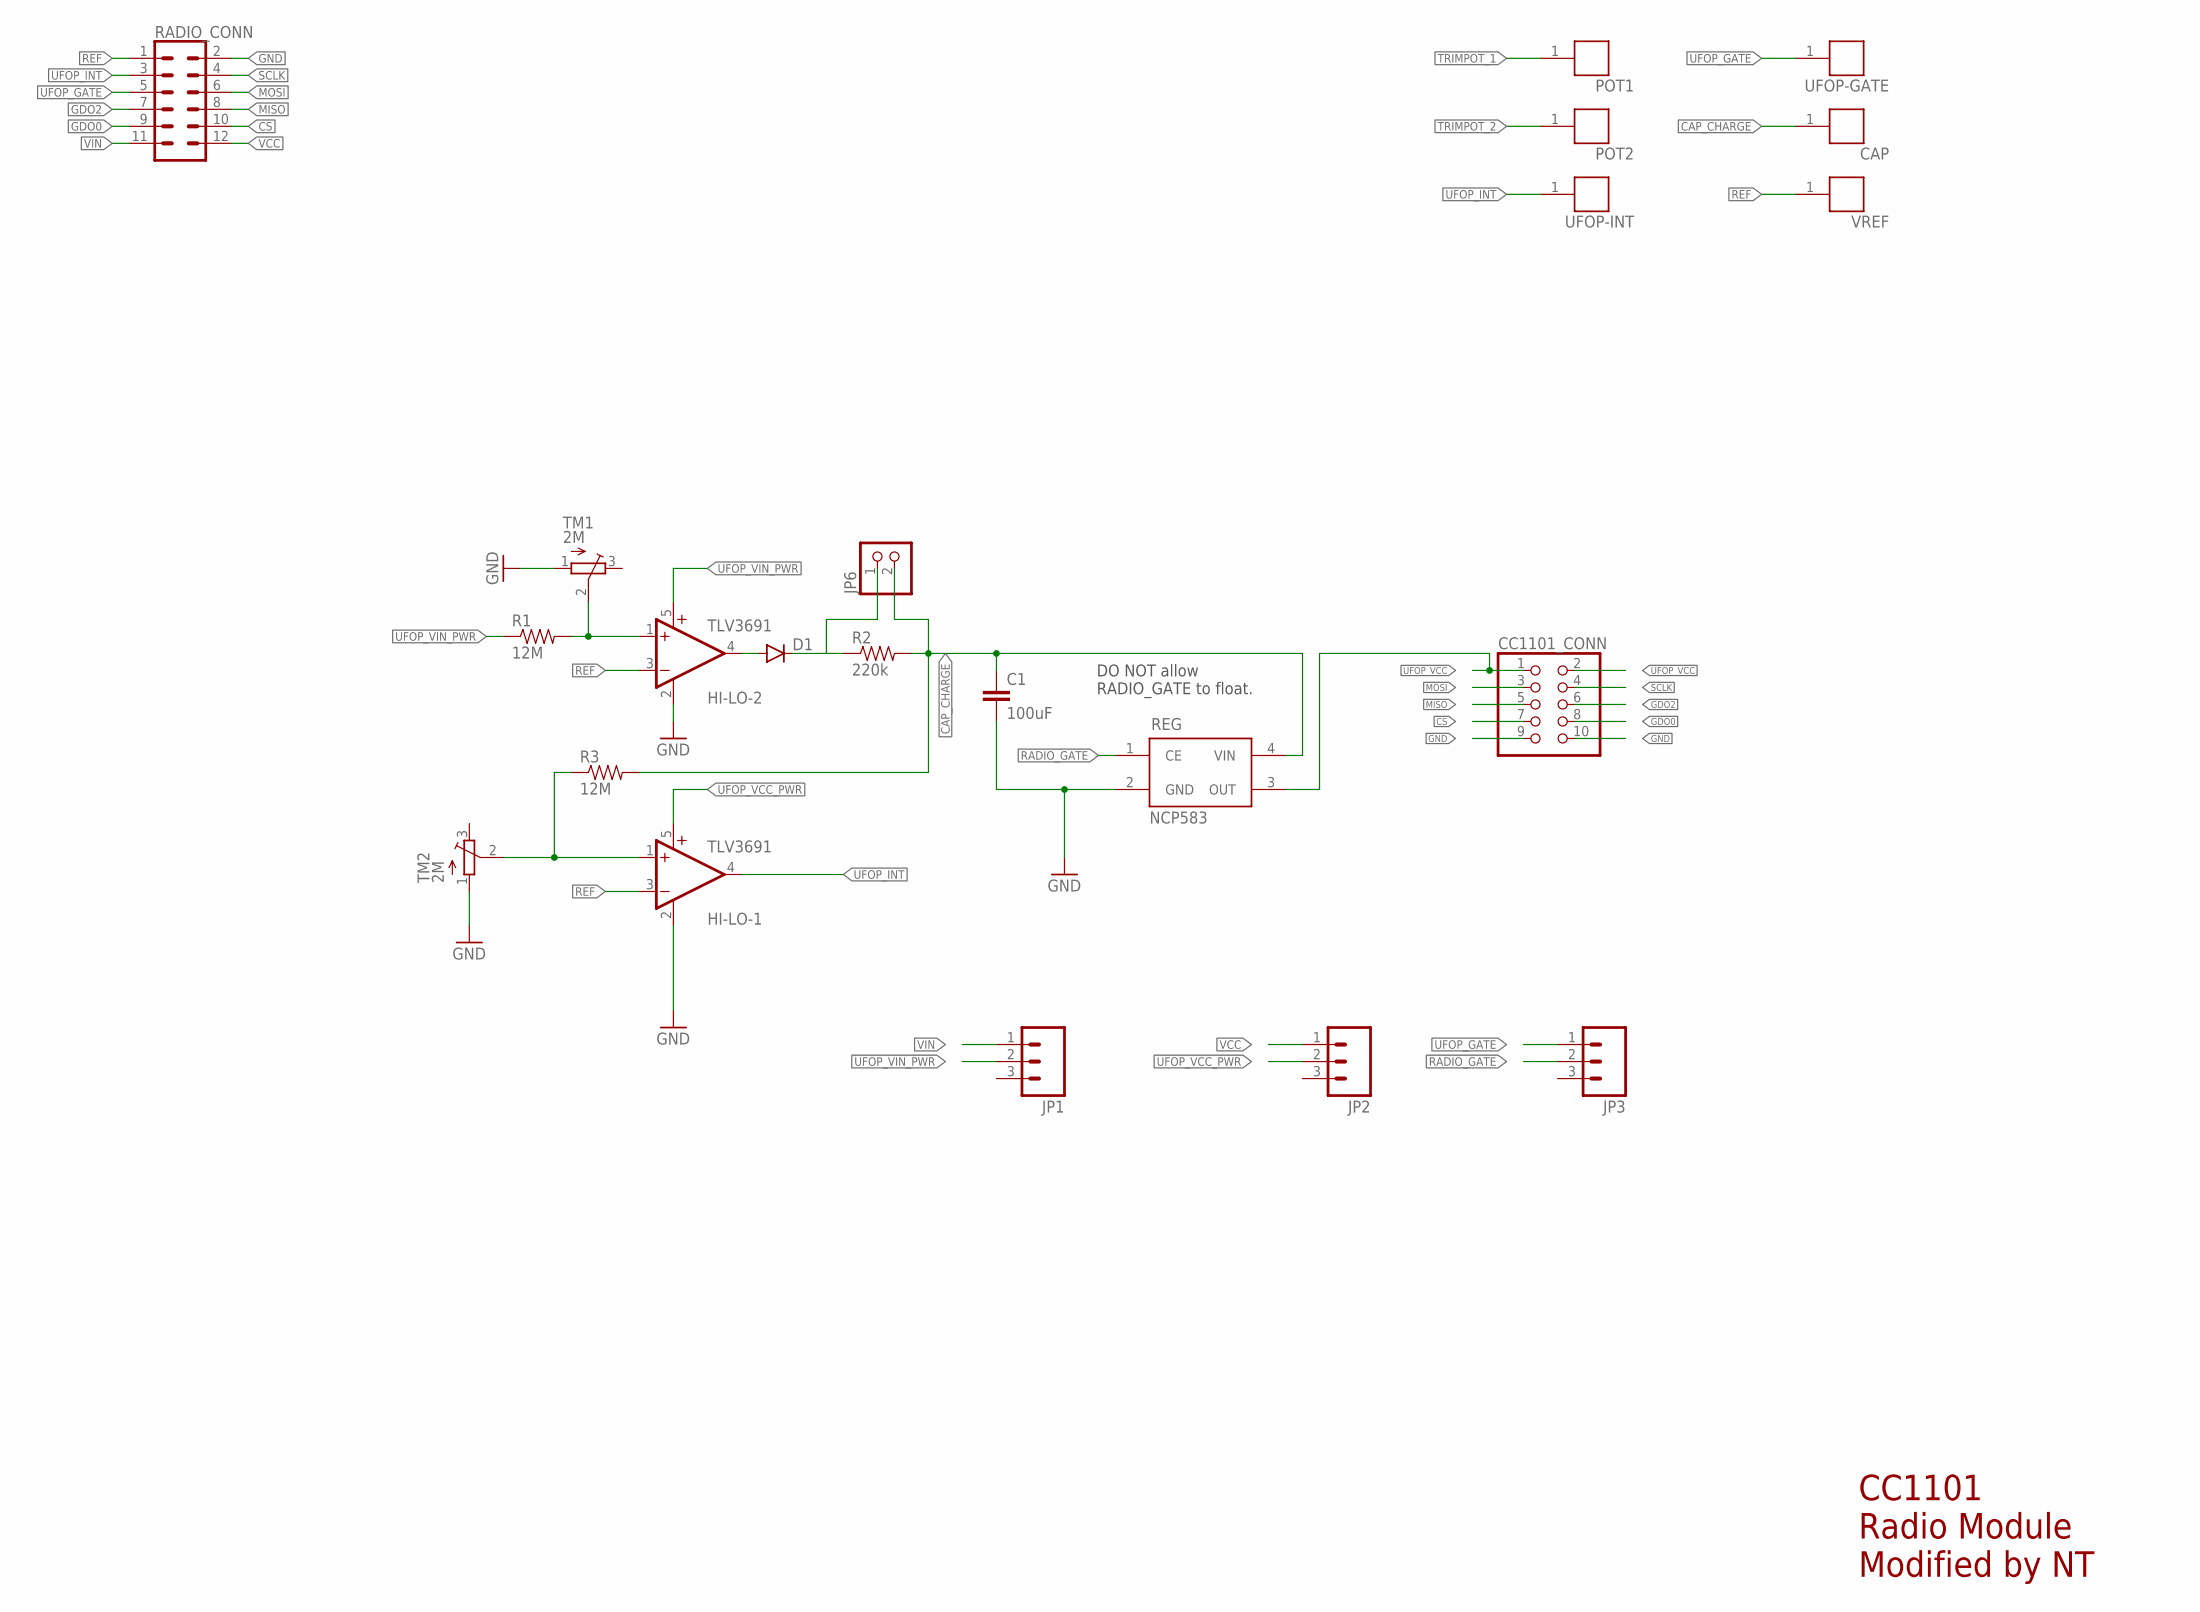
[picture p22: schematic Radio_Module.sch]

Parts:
C1: 100uF; 0603-CAP; DIGIKEY 490-9969-1-ND
CAP: RCU-0C; TE_RCU-0C
CC1101_CONN: PINHD-2X5; 2X05
D1: DIODESOD523; SOD523
HI-LO-1, HI-LO-2: TLV3691; SC70-5
JP1, JP2, JP3: M03; 1X03-1.27MM
JP6: PINHD-1X2; 1X02
POT1, POT2: RCU-0C; TE_RCU-0C
R1: 12M; 0603-RES
R2: 220k; 0603-RES; DIGIKEY 311-2.00MHRCT-ND
R3: 12M; 0603-RES; DIGIKEY 311-2.00MHRCT-ND
RADIO_CONN: CONN_06X2PTH_FEMALE; 2X6
REG: NCP583; SC82-AB_1PRIMARY
TM1, TM2: 2M; TC33X
UFOP-GATE: RCU-0C; TE_RCU-0C
UFOP-INT: RCU-0C; TE_RCU-0C
VREF: RCU-0C; TE_RCU-0C

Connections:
CAP_CHARGE: C1.1, CAP.1, JP6.2, R2.2, R3.2, REG.4 (VIN)
CS: CC1101_CONN.7, RADIO_CONN.10
GDO0: CC1101_CONN.8, RADIO_CONN.9
GDO2: CC1101_CONN.6, RADIO_CONN.7
GND: C1.2, CC1101_CONN.9, CC1101_CONN.10, HI-LO-1.2 (GND), HI-LO-2.2 (GND), RADIO_CONN.2, REG.2 (GND), TM1.1 (A), TM2.1 (A)
MISO: CC1101_CONN.5, RADIO_CONN.8
MOSI: CC1101_CONN.3, RADIO_CONN.6
unnamed: D1.C, JP6.1, R2.1
unnamed: D1.A, HI-LO-2.4 (OUT)
RADIO_GATE: JP3.2, REG.1 (CE)
REF: HI-LO-1.3 (-IN), HI-LO-2.3 (-IN), RADIO_CONN.1, VREF.1
SCLK: CC1101_CONN.4, RADIO_CONN.4
TRIMPOT_1: HI-LO-2.1 (+IN), POT1.1, R1.2, TM1.2 (S)
TRIMPOT_2: HI-LO-1.1 (+IN), POT2.1, R3.1, TM2.2 (S)
UFOP_GATE: JP3.1, RADIO_CONN.5, UFOP-GATE.1
UFOP_INT: HI-LO-1.4 (OUT), RADIO_CONN.3, UFOP-INT.1
UFOP_VCC: CC1101_CONN.1, CC1101_CONN.2, REG.3 (OUT)
UFOP_VCC_PWR: HI-LO-1.5 (V+), JP2.2
UFOP_VIN_PWR: HI-LO-2.5 (V+), JP1.2, R1.1
VCC: JP2.1, RADIO_CONN.12
VIN: JP1.1, RADIO_CONN.11

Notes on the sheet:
CC1101 Radio Module Modified by NT
DO NOT allow RADIO_GATE to float.

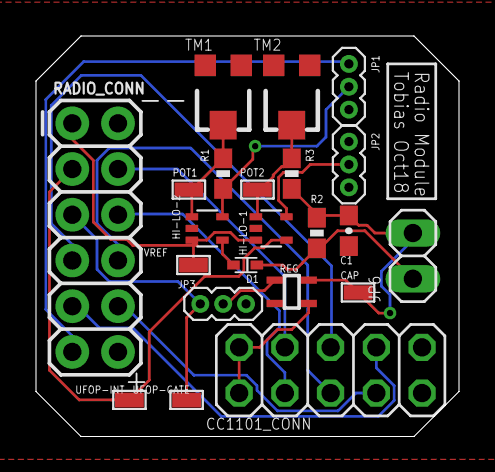
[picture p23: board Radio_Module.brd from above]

Board: 2 copper layers, 23.5 x 22.2 mm, 22 parts (0 on the bottom side), 21 nets.

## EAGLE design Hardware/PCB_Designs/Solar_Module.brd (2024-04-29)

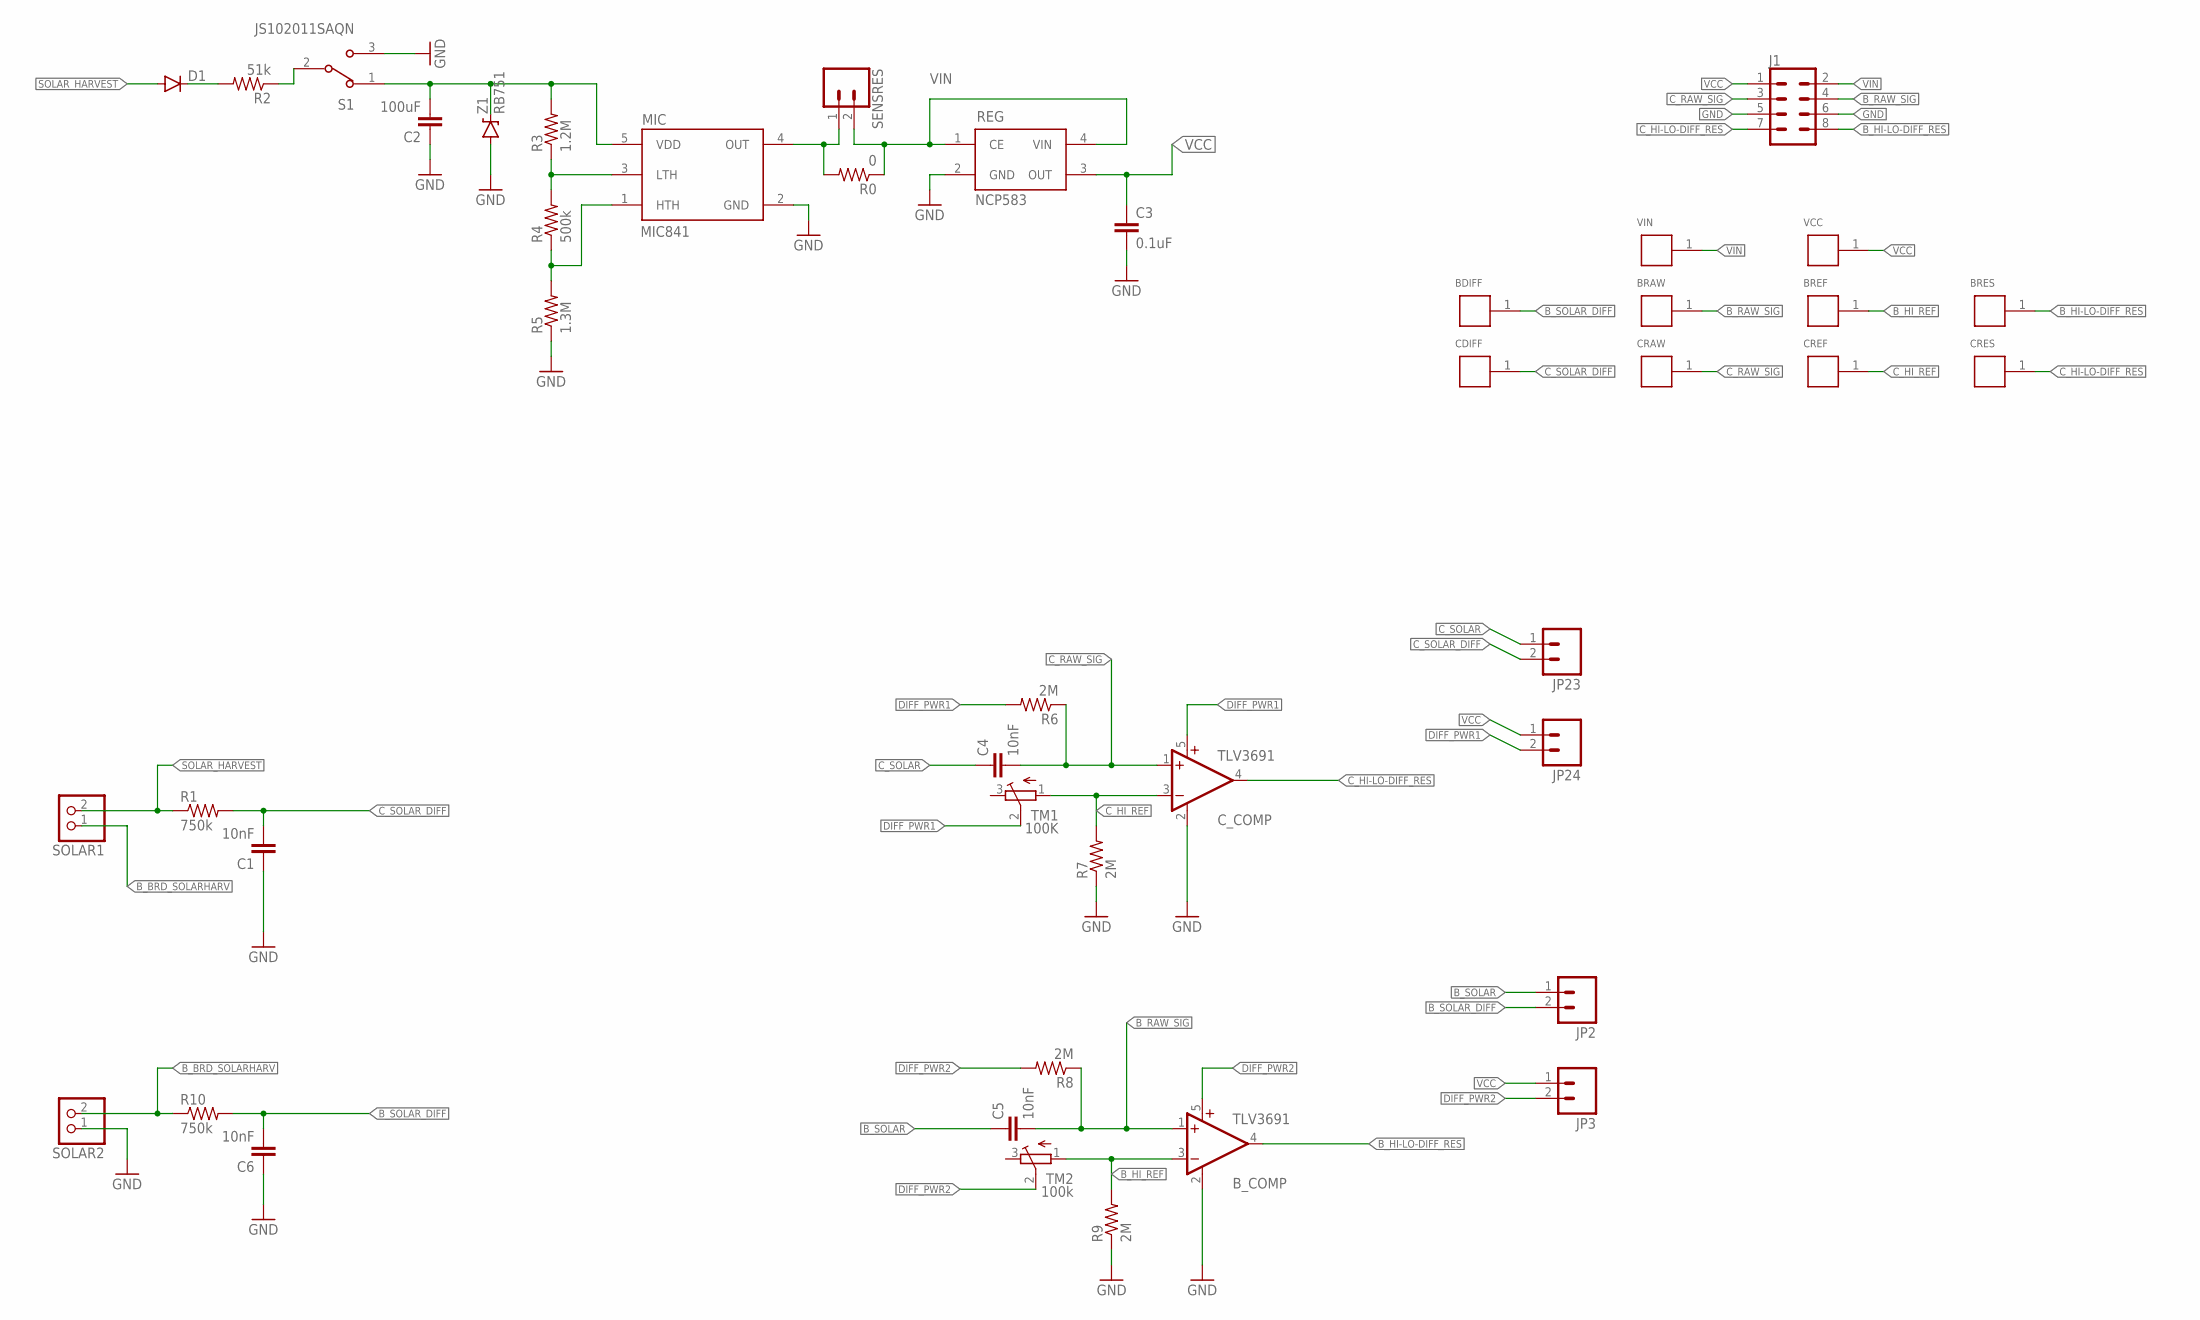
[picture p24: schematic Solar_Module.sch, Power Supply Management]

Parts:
BDIFF: RCU-0C; TE_RCU-0C
BRAW: RCU-0C; TE_RCU-0C
BREF: RCU-0C; TE_RCU-0C
BRES: RCU-0C; TE_RCU-0C
B_COMP: TLV3691; SC70-5
C1, C4, C5, C6: 10nF; 0603-CAP
C2: 100uF; 0603-CAP
C3: 0.1uF; 0603-CAP
CDIFF: RCU-0C; TE_RCU-0C
CRAW: RCU-0C; TE_RCU-0C
CREF: RCU-0C; TE_RCU-0C
CRES: RCU-0C; TE_RCU-0C
C_COMP: TLV3691; SC70-5
D1: DIODESOD523; SOD523
J1: CONN_04X2; 2X4
JP2, JP3, JP23, JP24: M02; 1X02-1.27MM
MIC: MIC841; SC70-5
R0: 0; 0603-RES
R1, R10: 750k; 0603-RES
R2: 51k; 0603-RES
R3: 1.2M; 0603-RES
R4: 500k; 0603-RES
R5: 1.3M; 0603-RES
R6, R7, R8, R9: 2M; 0603-RES
REG: NCP583; SC82-AB_1PRIMARY
S1: JS102011SAQN; SW_JS102011SAQN
SENSRES: CONN_02; 1X02
SOLAR1, SOLAR2: PINHD-1X2; 1X02
TM1: 100K; TC33X
TM2: 100k; TC33X
VCC: RCU-0C; TE_RCU-0C
VIN: RCU-0C; TE_RCU-0C
Z1: RB751; SOD-523

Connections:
B_BRD_SOLARHARV: R10.1, SOLAR1.1, SOLAR2.2
B_HI-LO-DIFF_RES: BRES.1, B_COMP.4 (OUT), J1.8
B_HI_REF: BREF.1, B_COMP.3 (-IN), R9.2, TM2.1 (A)
B_RAW_SIG: BRAW.1, B_COMP.1 (+IN), C5.2, J1.4, R8.1
B_SOLAR: C5.1, JP2.1
B_SOLAR_DIFF: BDIFF.1, C6.2, JP2.2, R10.2
C_HI-LO-DIFF_RES: CRES.1, C_COMP.4 (OUT), J1.7
C_HI_REF: CREF.1, C_COMP.3 (-IN), R7.2, TM1.1 (A)
C_RAW_SIG: C4.2, CRAW.1, C_COMP.1 (+IN), J1.3, R6.1
C_SOLAR: C4.1, JP23.1
C_SOLAR_DIFF: C1.2, CDIFF.1, JP23.2, R1.2
DIFF_PWR1: C_COMP.5 (V+), JP24.2, R6.2, TM1.2 (S)
DIFF_PWR2: B_COMP.5 (V+), JP3.2, R8.2, TM2.2 (S)
GND: B_COMP.2 (GND), C1.1, C2.1, C3.2, C6.1, C_COMP.2 (GND), J1.5, J1.6, MIC.2 (GND), R5.1, R7.1, R9.1, REG.2 (GND), S1.3, SOLAR2.1, Z1.ANODE (A)
MIC_INPUT: C2.2, MIC.5 (VDD), R3.2, S1.1, Z1.CATHODE (C)
unnamed: D1.C, R2.2
unnamed: MIC.4 (OUT), R0.2, SENSRES.1
unnamed: R2.1, S1.2
unnamed: MIC.3 (LTH), R3.1, R4.2
unnamed: MIC.1 (HTH), R4.1, R5.2
SOLAR_HARVEST: D1.A, R1.1, SOLAR1.2
VCC: C3.1, J1.1, JP3.1, JP24.1, REG.3 (OUT), VCC.1
VIN: J1.2, R0.1, REG.1 (CE), REG.4 (VIN), SENSRES.2, VIN.1

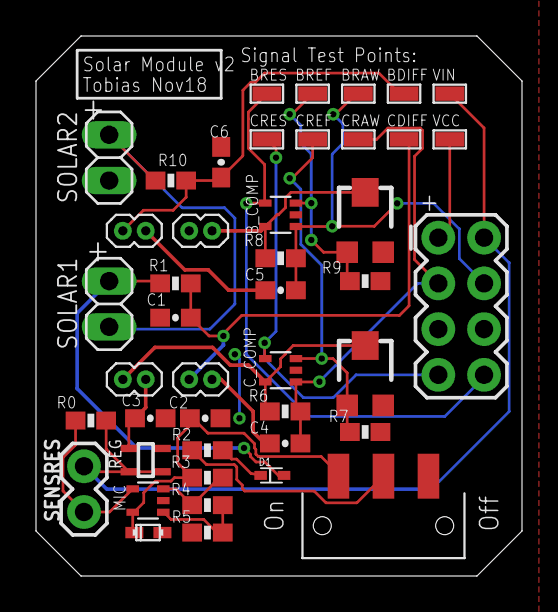
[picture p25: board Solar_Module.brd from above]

Board: 2 copper layers, 27.0 x 30.0 mm, 44 parts (0 on the bottom side), 23 nets.

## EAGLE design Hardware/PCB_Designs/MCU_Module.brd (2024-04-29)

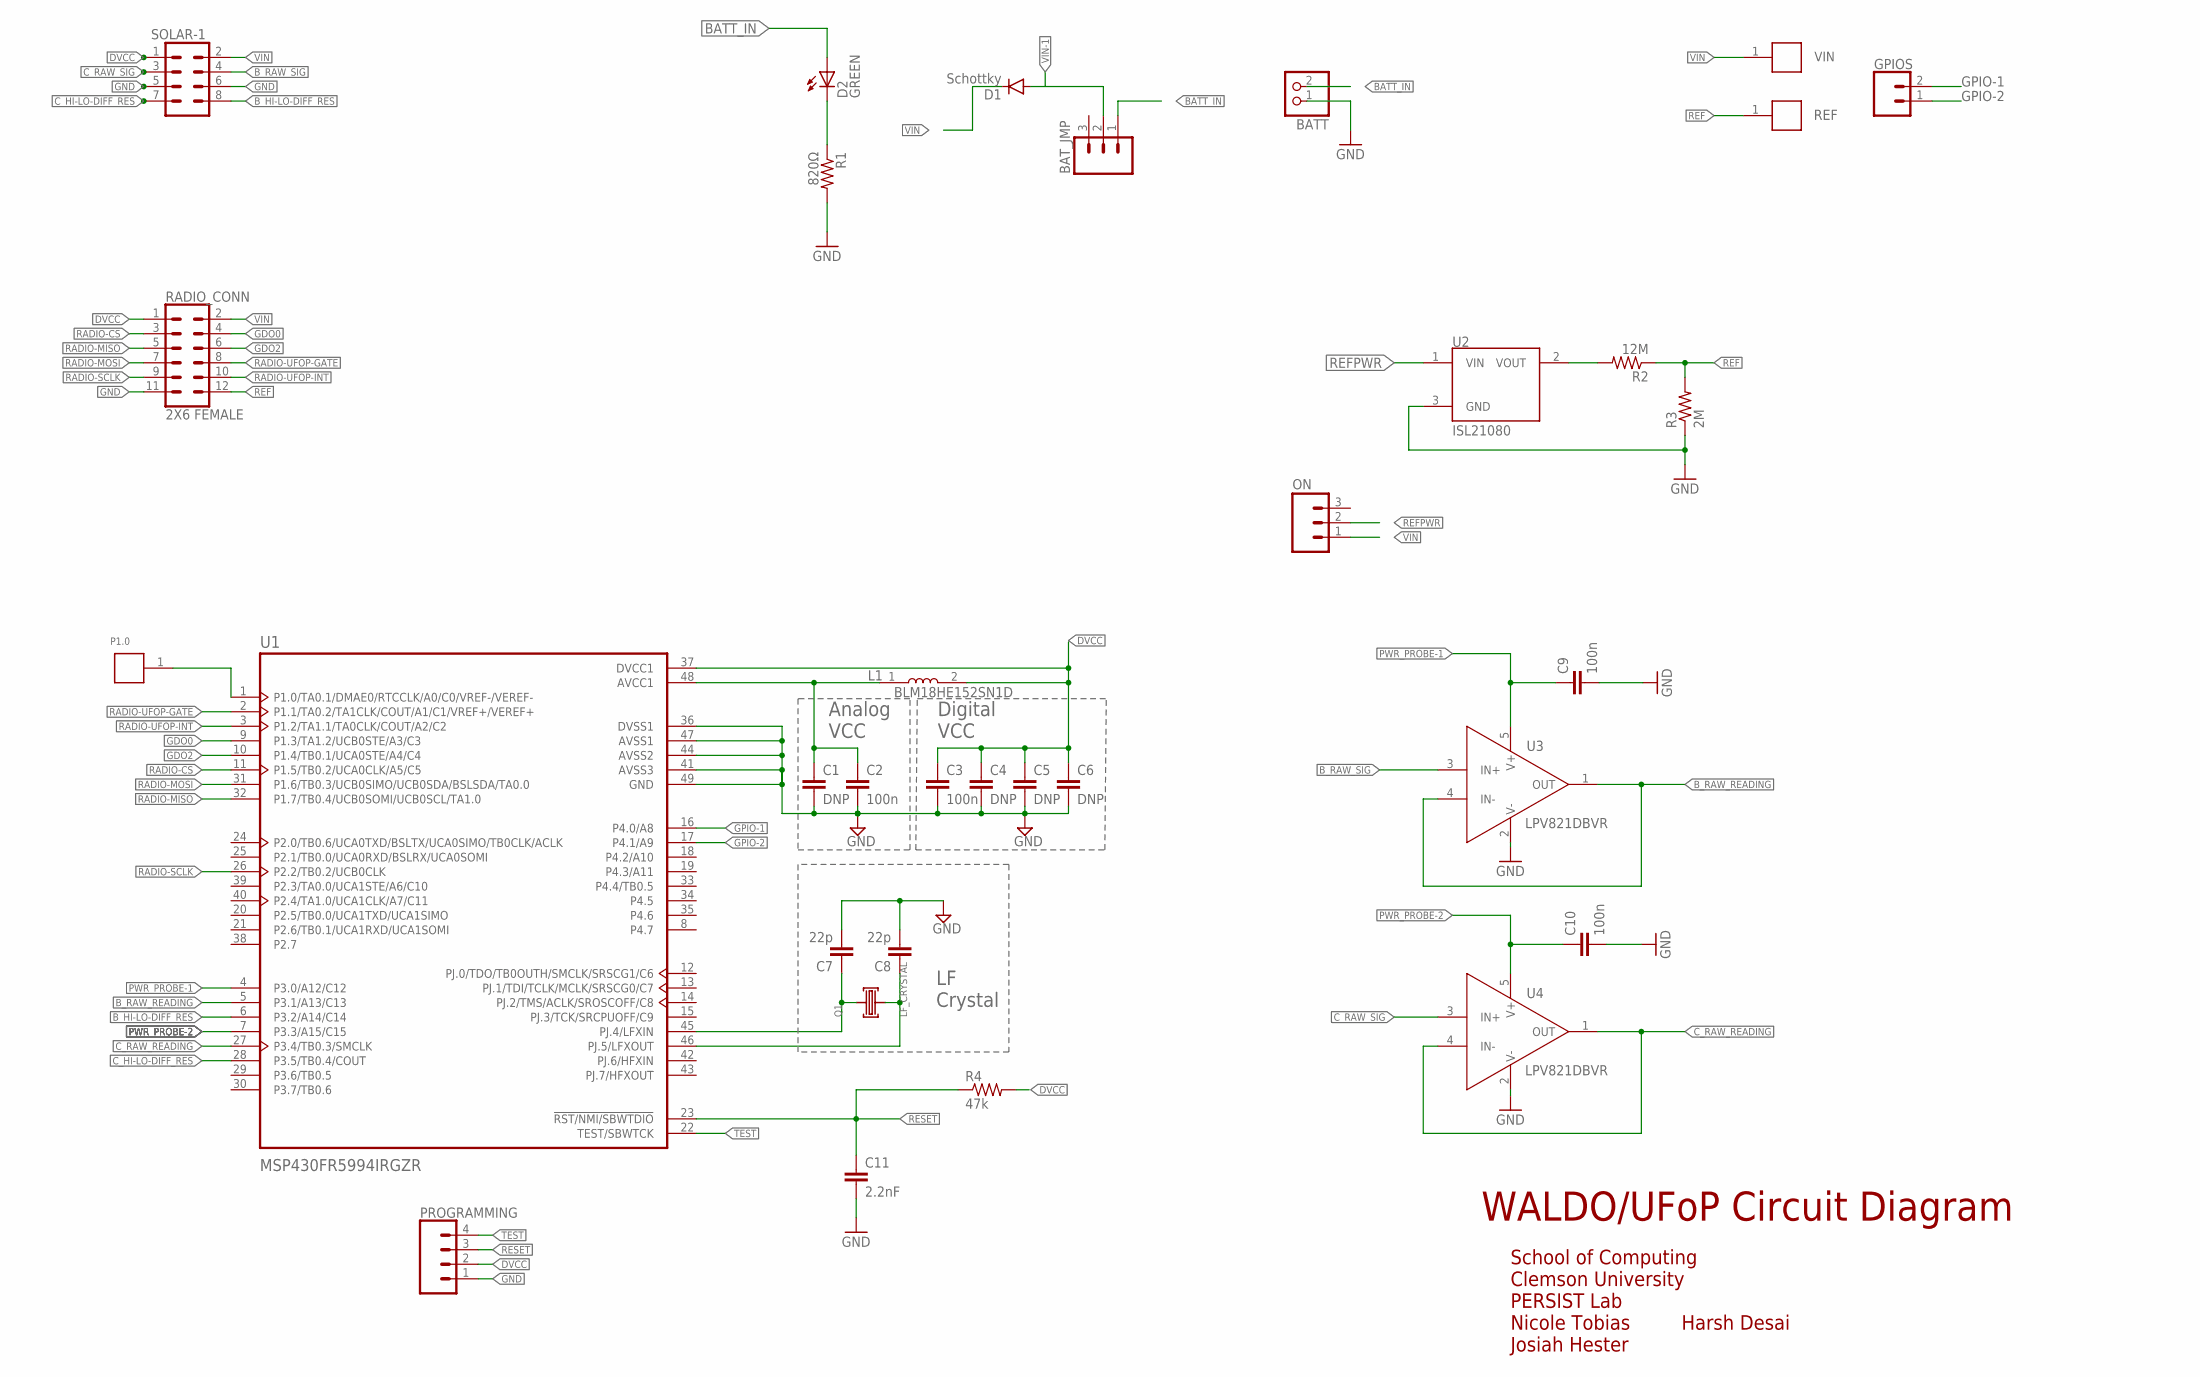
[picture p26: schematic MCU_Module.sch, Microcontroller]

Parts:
BATT: PINHD-1X2; 1X02
BAT_JMP: M03; 1X03-1.27MM
C1, C4, C5, C6: DNP; C0603
C2, C3, C9, C10: 100n; C0603
C7, C8: 22p; C0603
C11: 2.2nF; C0603
D1: Schottky; SOD523
D2: GREEN; CHIP-LED0805
GPIOS: CONN_02; 1X02
L1: BLM18HE152SN1D; INDC1608X95
ON: M03; 1X03-1.27MM
P1.0: RCU-0C; TE_RCU-0C
PROGRAMMING: CONN_04; 1X04
Q1: LF_CRYSTAL
R1: 820Ω; 0603-RES
R2: 12M; 0603-RES; DIGIKEY 541-6.20MHCT-ND
R3: 2M; 0603-RES; DIGIKEY 311-1.00MHRCT-ND
R4: 47k; 0603-RES; DIGIKEY 311-1.00MHRCT-ND
RADIO_CONN: 2X6 FEMALE; 2X6
REF: RCU-0C; TE_RCU-0C
SOLAR-1: CONN_04X2; 2X4
U1: MSP430FR5994IRGZR; QFN50P700X700X100-49N
U2: ISL21080; SOT-23; DIGIKEY ISL21080DIH309Z-TKCT-ND
U3, U4: LPV821DBVR; SOT95P280X145-5N
VIN: RCU-0C; TE_RCU-0C

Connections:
AVCC: C1.1, C2.1, L1.1, U1.48 (AVCC1)
BATT_IN: BATT.2, BAT_JMP.1, D2.A
B_HI-LO-DIFF_RES: SOLAR-1.8, U1.6 (P3.2/A14/C14)
B_RAW_READING: U1.5 (P3.1/A13/C13), U3.1 (OUT), U3.4 (IN-)
B_RAW_SIG: SOLAR-1.4, U3.3 (IN+)
C_HI-LO-DIFF_RES: SOLAR-1.7, U1.28 (P3.5/TB0.4/COUT)
C_RAW_READING: U1.27 (P3.4/TB0.3/SMCLK), U4.1 (OUT), U4.4 (IN-)
C_RAW_SIG: SOLAR-1.3, U4.3 (IN+)
DVCC: C3.1, C4.1, C5.1, C6.1, L1.2, PROGRAMMING.2, R4.2, RADIO_CONN.1, SOLAR-1.1, U1.37 (DVCC1)
GDO0: RADIO_CONN.4, U1.9 (P1.3/TA1.2/UCB0STE/A3/C3)
GDO2: RADIO_CONN.6, U1.10 (P1.4/TB0.1/UCA0STE/A4/C4)
GND: BATT.1, C1.2, C2.2, C3.2, C4.2, C5.2, C6.2, C7.2, C8.2, C9.2, C10.2, C11.2, PROGRAMMING.1, R1.2, R3.1, RADIO_CONN.11, SOLAR-1.5, SOLAR-1.6, U1.36 (DVSS1), U1.41 (AVSS3), U1.44 (AVSS2), U1.47 (AVSS1), U1.49 (GND), U2.3 (GND), U3.2 (V-), U4.2 (V-)
GPIO-1: GPIOS.2, U1.16 (P4.0/A8)
GPIO-2: GPIOS.1, U1.17 (P4.1/A9)
unnamed: P1.0.1, U1.1 (P1.0/TA0.1/DMAE0/RTCCLK/A0/C0/VREF-/VER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)
unnamed: D2.C, R1.1
unnamed: R2.2, U2.2 (VOUT)
unnamed: C8.1, Q1.2, U1.46 (PJ.5/LFXOUT)
unnamed: C7.1, Q1.1, U1.45 (PJ.4/LFXIN)
PWR_PROBE-1: C9.1, U1.4 (P3.0/A12/C12), U3.5 (V+)
PWR_PROBE-2: C10.1, U1.7 (P3.3/A15/C15), U4.5 (V+)
RADIO-CS: RADIO_CONN.3, U1.11 (P1.5/TB0.2/UCA0CLK/A5/C5)
RADIO-MISO: RADIO_CONN.5, U1.32 (P1.7/TB0.4/UCB0SOMI/UCB0SCL/TA1.0)
RADIO-MOSI: RADIO_CONN.7, U1.31 (P1.6/TB0.3/UCB0SIMO/UCB0SDA/BSLSDA/TA0.0)
RADIO-SCLK: RADIO_CONN.9, U1.26 (P2.2/TB0.2/UCB0CLK)
RADIO-UFOP-GATE: RADIO_CONN.8, U1.2 (P1.1/TA0.2/TA1CLK/COUT/A1/C1/VREF+/VERE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)
RADIO-UFOP-INT: RADIO_CONN.10, U1.3 (P1.2/TA1.1/TA0CLK/COUT/A2/C2)
REF: R2.1, R3.2, RADIO_CONN.12, REF.1
REFPWR: ON.2, U2.1 (VIN)
RESET: C11.1, PROGRAMMING.3, R4.1, U1.23 (!RST/NMI/SBWTDIO)
TEST: PROGRAMMING.4, U1.22 (TEST/SBWTCK)
VIN: D1.C, ON.1, RADIO_CONN.2, SOLAR-1.2, VIN.1
VIN-1: BAT_JMP.2, D1.A

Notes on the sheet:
WALDO/UFoP Circuit Diagram
School of Computing Clemson University PERSIST Lab Nicole Tobias Harsh Desai Josiah Hester
Analog
VCC
Digital
Crystal

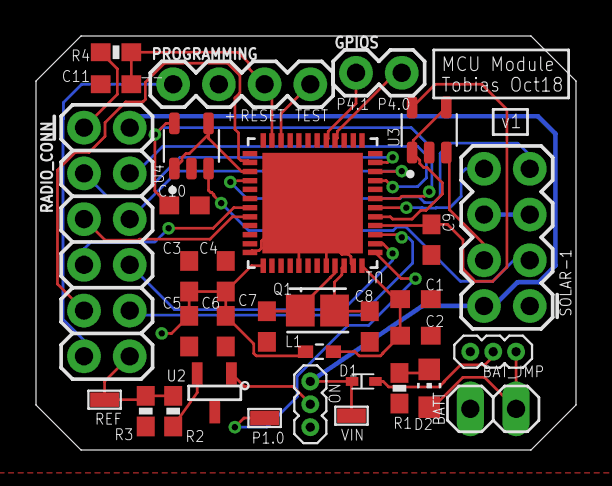
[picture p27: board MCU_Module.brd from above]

Board: 2 copper layers, 30.0 x 23.0 mm, 33 parts (0 on the bottom side), 33 nets.

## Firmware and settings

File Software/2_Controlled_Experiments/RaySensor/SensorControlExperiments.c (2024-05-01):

#include <msp430fr5994.h>
#include <string.h>
#include "cc1101.h"

// ****** Macro Declaration ******
#define TX_BUFFER_SIZE        40 //key + 13*3         // Size of Data Packet to send on Radio
//#define TIMER_HZ          1250                    //if VLO, use 1250 (this gives ~1.2s);           
#define TIMER_HZ              4096                    //if LFXT, use 4096 
#define TIMER_THRESHOLD       24576//(6*Timer_hz)//20480//(5*TIMER_HZ)      // TIMER_THRESHOLD = 4096 -> Timer interrupt at 1s , set accordingly
#define TIMERA1_THRESHOLD     40960//(10*TIMER_HZ)
#define FRAM_START_ADDRESS    0x10000
#define FRAM_BUF_SIZE         50
#define NUMEVENTS             3    //number of event that are being kept up with at a given time.
#define EVENTBYTES            9   //number of items being stored for each event (startx2, endx2, CRC = 5 items @ 10 bytes, plus an additional 1 byte for event # => totaling 11 bytes)
#define PKTTBYTES             9
#define WAITTIME              5
#define WALDO_ID              50
//#define BLIP_THRESHOLD        2

// ****** Variable Declaration ******
uint8_t tx_buffer[61]={0};
volatile unsigned char state_variable, interrupt_channel, timerA0_flag, timerA1_flag, timerB0_flag;
volatile unsigned short int timer_start;
const unsigned int CRC_Init = 0xFFFF;
unsigned int CRC_Result;                    // Holds results obtained through the CRC16 module

uint8_t FRAM_buffer[FRAM_BUF_SIZE] __attribute__((section(".nv")));

volatile uint8_t event_count = 0, interrupt_flag, /*lpm_flag,*/ radio_flag, iet_ct = 0, 
                shamt = 0, ins = 0, outs = 0, passbys = 0, restarts = 0, other = 0, result = 0, 
                flipB = 0, flipC = 0, accumBdown = 0, accumCdown = 0 ;
volatile int ch1_start, ch2_start, ch1_end, ch2_end, ct_Bdown, ct_Cdown, ct_Bup, ct_Cup,
                ch1_len, ch2_len, dist_st, dist_end, rel_dist_st, rel_dist_end, comB, comC, ch1_st_temp, ch2_st_temp;

// ****** Function Declaration ******
void initialize_system_clock();  // To set up the clock sources and frequency
void optimize_unused_pins();     // To set all other pins to input pulldown to minimize power draw
void initialize_system_pins();   // To set up interrupt pins and GPIOs

void delay_timerA0(int);         // Delay using Timer A0, 1s = 32768/8 = 4096
void delay_timerB0(int);         // Delay using Timer B0, 1s = 32768/8 = 4096
void start_timerA0();            // Start Timer A0 for time specified by value of TIMER_THRESHOLD
void start_timer_A1();           // Start Timer A1 for time specified by value of TIMERA1_THRESHOLD
void stop_timer_A1();

void go_to_sleep();
void enable_detectorISRs();
void disable_detectorISRs();
uint8_t evaluate_event();           // What to do when timer A fires signaling end of event
void send_radio_pkt(uint8_t *tx_data, uint8_t size);  //void call_radio(unsigned char length, unsigned char data);  //void pin_setup_after_radio_charged();

/****** Main Function ******/
int main(void)
{
  WDTCTL = WDTPW | WDTHOLD;         // stop watchdog timer
  PM5CTL0 &= ~LOCKLPM5;             // Unlock LOCKLPM5 bit

  //Initialize all the pins and clock settings at start-up
  optimize_unused_pins();           // Set all appropriate input pins to input pulldown to optimize energy consumption
  initialize_system_pins();                // Setup pins as interrupts and GPIOs
  disable_detectorISRs();
  initialize_system_clock();        // Set clock source and frequency to 16MHz

  P1DIR |= BIT0;
  P1OUT &= ~BIT0;
  P4DIR |= BIT0;
  P4OUT &= ~BIT0;

  delay_timerA0(5);       // Start up delay (~5 seconds); This allows system to settle during power-up before checking for events    
  //go_to_sleep(-1);  //for debugging only

  enable_detectorISRs(); 
  
  // Set initial flags and variables
  interrupt_flag = 0;               // Checks if any Port interrupt has fired
  //lpm_flag = 1;                     // 1: LPM4  |   0: LPM3
  radio_flag = 0;                   // 1: Radio Interrupt Triggered
  interrupt_channel = 0;            // Indicates which port fired the interrupt
  timerA0_flag = 0;                 // 1: Timer A ISR has fired
  timer_start = 0;                  // 1: Timer has already been started by some process | 
                                    //     0: Timer not started

  memset(FRAM_buffer, 0, FRAM_BUF_SIZE); //initialize FRAM_buffer to zero (for now, at least.)

  // Start, end times and signal width for both channels wrt first interrupt ie all times are from when the
  // first channel starts (one start value will be equal or close to zero)
  ch1_start = ch1_end = -1;
  ch2_start = ch2_end = -1;
  ch1_len = ch2_len = 0;
  dist_st = dist_end = 0;
  ct_Bup = ct_Bdown = 0;
  ct_Cup = ct_Cdown = 0;
  comB = comC = 0;
  accumBdown = accumCdown = 0;
    
  uint8_t ref_idx = 0, cur_idx = 0;

  //start_timer_A1();
  while(1)
  {
    go_to_sleep();

      // ****** The following part of the code runs only when some interrupt (Port or timer) wakes up the MCU ******
      // ****** Otherwise, the MCU always remains in LPM4 (LPM3 is used when start the timer for event_eval) ******
    
    if(timerA0_flag) //inter-event interval or timerA1_flag
    {
      event_count++;
      result = evaluate_event();
      if((P1IN & BIT2))
      {
        disable_detectorISRs();
        tx_buffer[0] = 57;
        tx_buffer[1] = WALDO_ID;
        tx_buffer[2] = event_count;  //inter-event time count
        tx_buffer[3] = result;
        tx_buffer[4] = ch1_start & 0xFF;    tx_buffer[5] = ch1_start >> 8;
        tx_buffer[6] = ch1_end & 0xFF;      tx_buffer[7] = ch1_end >> 8;
        tx_buffer[8] = ch2_start & 0xFF;    tx_buffer[9] = ch2_start >> 8;
        tx_buffer[10] = ch2_end & 0xFF;     tx_buffer[11] = ch2_end >> 8;
        tx_buffer[12] = 0;
        //tx_buffer[12] = comB & 0xFF;       tx_buffer[13] = comB >> 8;
        //tx_buffer[14] = comC & 0xFF;       tx_buffer[15] = comC >> 8;
        //tx_buffer[16] = accumBdown;         tx_buffer[17] = accumCdown;
        //send to pkt
        send_radio_pkt(tx_buffer, TX_BUFFER_SIZE);
        delay_timerB0(TIMER_HZ);   // 1s = 4096, /8 seem to work well here.
        //delay_timerB(1 * TIMER_HZ);   // 1s = 4096,
      }
      
      iet_ct = 0;  ///moved out of send loop       
      timerA0_flag = 0;
      
      ch1_start = ch1_end = -1;
      ch2_start = ch2_end = -1;
      ch1_st_temp = ch2_st_temp = -1;
      ch1_len = ch2_len = 0;
      dist_end = dist_st = 0;
      //ct_Bdown = ct_Cdown = 0;
      //ct_Bup = ct_Cup = 0;
      //flipB = flipC = 0;
      //accumBdown = accumCdown = 0;
      //comB = comC = 0;
      
      P1OUT ^= BIT0;
      enable_detectorISRs();
    }//*/
    
    if(interrupt_flag)
    {                  // Triggers only when Port ISR sets interrupt_flag
      if(!timer_start)
      {                  // If it's the first one to trigger (timer hasn't been started yet)
          start_timerA0();                  // Start Timer_A
          timerA0_flag = 0; /// this flag may need to be moved
          //timerA1_flag = 0;  //added
          P1OUT ^= BIT0; 
      }
          
      if(interrupt_channel == 1)
      {         // Hi-Lo Channel 1 interrupt triggered  //B
        if(ch1_start == -1)
        {
          ch1_start = TA0R;
          //ch1_st_temp = ch1_start;
          P3IES &= ~BIT2;                 // Invert triggering edge to Lo-Hi
          //flipB = 1;
        }
        /*else if(flipB == 0)
        {     // Hi-Lo Channel 1 interrupt triggered
          ch1_st_temp = TA0R;
          P3IES &= ~BIT2;                 // Invert triggering edge to Lo-Hi
          flipB = 1;
          ct_Bup += (ch1_st_temp - ch1_end);
        }//*/
        else
        {
          ch1_end = TA0R;
          //P3IES |= BIT2;                  // Trigger on Hi-Lo
          /*flipB = 0;
          ct_Bdown += (ch1_end - ch1_st_temp);

          if(ch1_end - ch1_st_temp < BLIP_THRESHOLD //2 or 488microseconds  
            && ct_Bdown < 12) //Reset for blip
            {
              accumBdown = ct_Bdown;
              ch1_start = ch1_st_temp;
            }//*/
        }
      }
      else if(interrupt_channel == 2)  //C
      {
        if(ch2_start == -1)
        {
          ch2_start = TA0R;
          //ch2_st_temp = ch2_start;
          P3IES &= ~BIT5;                 // Invert triggering edge to Lo-Hi
          //flipC = 1;
        }
        /*else if(flipC == 0)
        {     // Hi-Lo Channel 1 interrupt triggered
          ch2_st_temp = TA0R;
          P3IES &= ~BIT5;                 // Invert triggering edge to Lo-Hi
          flipC = 1;
          ct_Cup += (ch2_st_temp - ch2_end);
        }//*/
        else
        {
          ch2_end = TA0R;
          //P3IES |= BIT5;                  // Trigger on Hi-Lo
          /*flipC = 0;
          ct_Cdown += (ch2_end - ch2_st_temp);
          
          if(ch2_end - ch2_st_temp < BLIP_THRESHOLD //2 or 488microseconds  
            && ct_Cdown < 12) //Reset for blip
            {
              accumCdown = ct_Cdown;
              ch2_start = ch2_st_temp;
            }//*/
        }
      }//end if-else
      
      interrupt_channel = 0;
      interrupt_flag = 0;
    }//end if//*/
  }//end while

  return 0;
}//end main

void initialize_system_pins()
{
  // Port Interrupt Setup
  P3IE |= BIT2;            // HL1 Interrupt Enable
  P3IE |= BIT5;            // HL2 Interrupt Enable
  P3IES |= BIT2;            // Trigger on Hi-Lo
  P3IES |= BIT5;
  P3IFG &= ~BIT2;            // Clear Interrupt Flag
  P3IFG &= ~BIT5;

  // GPIO Setup
  P4DIR |= (BIT0 + BIT1);           // GPIOs P4.0 and P4.1
  P4OUT &= (~BIT1 + ~BIT1);

  // Radio Port Setup - Radio_UFOP_Int P1.2
  P1DIR &= ~BIT2;     // radio int
  P1DIR |= BIT1;      // radio gate

  P1DIR |= (BIT1 + BIT3 + BIT5);     // 1.3: GDO0 | 1.1: Radio Gate | 1.5: Radio CSN
  //P1OUT |= BIT3;                            // Set GDO0
  P1OUT &= ~BIT1;                     // Reset Radio Gate
}//end initialize_pins function

void initialize_system_clock()
{
  // Configure one FRAM waitstate as required by the device datasheet for MCLK
  // operation beyond 8MHz _before_ configuring the clock system.
  FRCTL0 = FRCTLPW | NWAITS_1;
  PJSEL0 = BIT4 | BIT5;                     // For XT1
  // Clock System Setup
  //CSCTL0 = CSKEY;
  CSCTL0_H = CSKEY >> 8;
  
  CSCTL1 = DCORSEL | DCOFSEL_4;             // Set DCO to 16MHz
  //__delay_cycles(60);                       // Let it settle

  CSCTL2 = SELA__LFXTCLK | SELS__DCOCLK | SELM__DCOCLK;  // Set SMCLK = DCO/2; MCLK = DCO
                                                        // ACLK = LFXTCLK @ 32.768kHz
  CSCTL3 = DIVA__1 | DIVS__32 | DIVM__1;     // Set all dividers to 1, smclk div by 32
  CSCTL4 &= ~LFXTOFF;

  /* Start timerA2 that interrupts every 50ms. Clock is from SMCLK. 1ms=250, since
	   SMCLK was divided by 32 (16MHz/32) and we will again divide by 2 here (so 16MHz/64) above */
  TA2R = 0;
  TA2CCTL0 = CCIE;                          /* CCR0 interrupt enabled */
  TA2CCR0 =  12500;             						/* Set timer for 50ms = 12500 */
  TA2CTL = TASSEL__SMCLK + MC__UP + ID__2;  /* SMCLK, upmode, /2 */
  TA2CTL |= TAIE;                           /* Enable Timer A2 interrupt */

  do
  {
    __bis_SR_register(LPM1_bits+GIE);       /* Go to sleep and enable interrupts */

    CSCTL5 &= ~LFXTOFFG;                    // Clear XT1 fault flag
    SFRIFG1 &= ~OFIFG;
  }while (SFRIFG1&OFIFG);                   // Test oscillator fault flag

  // Stop timer
  TA2CCTL0 = ~CCIE;                 /* CCR0 interrupt disabled */
  TA2CCR0 = 0;
  TA2CTL = TACLR + MC__STOP;     		/* clear TAR, the clock divider logic and count direction remains unchanged */

  // Now that osc is running enable fault interrupt
  SFRIE1 |= OFIE;
  CSCTL0_H = 0;     // Lock CS registers
  //*/
}//end setup_clock_module function

void optimize_unused_pins()
{
  P1SEL0 = P2SEL0 = P3SEL0 = P4SEL0 = PJSEL0 = 0x00;
  P1SEL1 = P2SEL1 = P3SEL1 = P4SEL1 = PJSEL1 = 0x00; 
  
  P1DIR = 0x02;        //zero is input/ one is output
  P1REN = 0b11111010;  //one is pull-up/pull-down, zero is floating
  P1OUT = 0x00;        //value one is pull up or zero is pull down; output high or output low if dir is set to output

  P2DIR = 0x00;
  P2REN = 0xff;
  P2OUT = 0x00;

  P3DIR = 0b00000000;
  P3REN = 0b11011011; //pins connected to hi-lo need to be left unpulled down. 
  P3OUT = 0b00000000;

  P4DIR = 0x00;
  P4REN = 0xff;  
  P4OUT = 0x00;

  PJDIR = 0x00;
  PJREN = 0b11001111;
  PJOUT = 0x00;
}//end optimize_unused_pins function

void delay_timerA0(int delay_time)
{
  // Start Timer_A0
  TA0R = 0;
  TA0CCTL0 = CCIE;                              // CCR0 interrupt enabled
  TA0CCR0 = delay_time * TIMER_HZ;              // TIMER_HZ = timer_cycles per second.  
                                                    //If VLO, it is 1s = 1250 (10kHz/8); 
                                                    //else if XTAL, 1s = 4096 (32.768kHz / 8), 1ms = 1.25,  max = 65536/4096 = 16s
  TA0CTL = TASSEL__ACLK + MC__UP + ID__8;       // ACLK, upmode, /8
  TA0CTL |= TAIE;

  _BIS_SR(LPM3_bits+GIE);     //go to sleep

  // Stop timer
  TA0CCTL0 = ~CCIE;
  TA0CTL |= TACLR + MC__STOP;
  TA0CTL &= ~TAIE;
}//end delay_timerA0 function

void delay_timerB0(int delay_time)
{
  // Start Timer_B0
  TB0R = 0;
  TB0CCTL0 = CCIE;                              // CCR0 interrupt enabled
  TB0CCR0 =  delay_time;                        // 1s = 4096 (32.768kHz / 8), 1ms = 1.25,  max = 65536/4096 = 16s
  TB0CTL = TBSSEL__ACLK + MC__UP + ID__8;       // ACLK, upmode, /8
  TB0CTL |= TBIE;

  _BIS_SR(LPM3_bits+GIE);

  // Stop timer
  TB0CCTL0 = ~CCIE;
  TB0CTL &= ~TBIE;
}//end delay_timerB0 function

void send_radio_pkt(uint8_t *tx_data, uint8_t size)//unsigned char transmit_length, unsigned char transmit_byte)
{
  //P1OUT |= BIT1;                           // Set Radio Gate: Turns on power to the radio
  
  // Turn off signal interrupts so that the power dip caused by radio isn't recorded as an event
  //disable_detectorISRs();
  
  // Radio startup
  P1DIR &= ~BIT2;								// Set radio_int pin as input
  if(P1IN & BIT2)
  {							// Confirm that radio is fully charged, takes at least 150ms
    
    P1OUT |= BIT1;							// Turn on radio
    P1DIR |= BIT1;
    __delay_cycles(64);
    Init();
    SetDataRate(3); 			// Needs to be the same in Tx and Rx
    SetLogicalChannel(2); // Needs to be the same as receiver
    SetTxPower(3);				// 7 dBm 11.9 mA
    SendData(tx_data, size);
    P1OUT &= ~BIT1;		// Open radio's gate to cut power
    
    // // Set Radio SPI bus to input
    P1DIR &= ~(BIT3 | BIT4 | BIT5 | BIT6 | BIT7);
    P2DIR &= ~BIT2;

    P1REN &= ~(BIT3 | BIT4 | BIT5 | BIT6 | BIT7);
    P2REN &= ~BIT2;
    P1DIR |= BIT0;

    //delay_timerB(2*TIMER_HZ);   // 1s = 1205
  }

  //enable_detectorISRs();
}//end send_radio_pkt function

uint8_t evaluate_event()
{
  uint8_t event_res = -1;
  // Compute width of Hi-Lo signals
  ch1_len = ch1_end - ch1_start;
  ch2_len = ch2_end - ch2_start;
  dist_st = (ch1_start - ch2_start);
  dist_st = dist_st * ((dist_st>0) - (dist_st<0));
  dist_end = (ch1_end - ch2_end);
  dist_end = dist_end * ((dist_end>0) - (dist_end<0));
  //rel_dist_st = (dist_st * 100) / ch2_len;
  //rel_dist_end = (dist_st * 100) / ch2_len;
  //comB = ct_Bup - ct_Bdown;
  //comC = ct_Cup - ct_Cdown;

  FRAM_buffer[0]++;  //increment event total seen so far

  if(event_count == 1)
  {
      restarts++;  //reboot
  }

  //Thresholds calculated using a decision tree trained on data minus major outliers (max depth = 4)
  if(ch1_len == 1 && ch2_len == 0)
  {
    event_res = 0; //close_door;
  }
  else if(ch1_start == -1 || ch2_start == -1 || ch1_end <= 561)
  {
    event_res = 1; //passby_out;
  }
  else if(ch1_end > 6710 && ch1_start > 2)
  {
    event_res = 9; //ins_9; confident
  }
  else if(ch1_end > 6710 && ch1_start <= 2 && dist_end > 393 && ch1_end > 7576)
  {
    if(ch1_end > ch2_end)
    {
      event_res = 8; //ins_8; confident
    }
    else
    {
      event_res = 13; //out; confident
    }
  }
  else if(ch1_end > 6710 && ch1_start <= 2 && dist_end > 393 && ch1_end <= 7576)
  {
    if(ch1_end > ch2_end)
    {
      event_res = 12; //ins
    }
    else
    {
      event_res = 6; //out; confident
    }
  }
  else if(ch1_end > 6710 && ch1_start <= 2 && dist_end <= 393)
  {
    event_res = 7; //pbin; confident
  }
  else if(ch1_end <= 6710 && ch1_end > 561 && dist_end > 427 && ch2_end > 4847)
  {
    if(ch1_start > 1000 || ch1_end > ch2_end)
    {
      event_res = 11; //ins
    }
    else
    {
      event_res = 5; //out; mostly******
    }
  }
  else if(ch1_end <= 6710 && ch1_end > 561 && dist_end > 427 && ch2_end <= 4847)
  {
    if(dist_st < 2 && ch2_end > ch1_end)
    {
      event_res = 14; //out; maybe******
    }
    else
    {
      event_res = 4; //in; maybe******
    }
  }
  else if(ch1_end <= 6710 && ch1_end > 561 && dist_end <= 427 && dist_end > 1)
  {
    event_res = 3; //pbin; confident
  }
  else if(ch1_end <= 6710 && ch1_end > 561 && dist_end <= 427 && dist_end <= 1)
  {
    event_res = 2; //pbin; maybe******
  }
  else
  {
    event_res = 10; //other++;
  }
  
  // Reset variables
  //lpm_flag = 1;
  interrupt_channel = 0;
  interrupt_flag = 0;
  timerA0_flag = 0;
  timer_start = 0;
  
  /*ch1_start = ch1_end = -1;
  ch2_start = ch2_end = -1;
  ch1_len = ch2_len = 0;
  dist_end = dist_st = 0;*/
  
  P3IES |= BIT2;            // Revert Trigger edge back to Hi-Lo for next event detection
  P3IES |= BIT5;

  return event_res;
}//end evaluate_event function

void start_timerA0()
{
  TA0CTL |= TACLR + MC__STOP;
  TA0R = 0;
  TA0CCTL0 = CCIE;                                // CCR0 interrupt enabled
  TA0CCR0 =  TIMER_THRESHOLD;                     // Set timer for 5s
  TA0CTL = TASSEL__ACLK + MC__UP + ID__8;         // ACLK, upmode, /8
  TA0CTL |= TAIE;

  timer_start = 1;
  //lpm_flag = 0;
}//end start_timerA0 function

void start_timer_A1()  //Setup 10s timer
{
  //TA1CTL |= TACLR + MC__STOP;
  TA1R = 0;
  TA1CCTL0 = CCIE;                                // CCR0 interrupt enabled
  TA1CCR0  = TIMERA1_THRESHOLD;                   // Set timer for 10s   Largest able to have is (2^16 = 65,536)
  TA1CTL   = TASSEL__ACLK + MC__UP + ID__8;       // ACLK, upmode, /8
  TA1CTL  |= TAIE;
}//end start_timerA1 function//*/

void stop_timer_A1()
{
  TA1CTL |= TACLR + MC__STOP;
  TA1R = 0;
  TA1CCTL0 = CCIE;                                // CCR0 interrupt enabled
  TA1CCR0 =  TIMERA1_THRESHOLD;                     // Set timer for ??
  TA1CTL = TASSEL__ACLK + MC__STOP + ID__8;         // ACLK, stop, /8
  TA1CTL &= ~TAIE;
  timerA1_flag = 0;
}//*/

void disable_detectorISRs()
{
  P3IE &= ~BIT2;            // HL1 Interrupt Disable (P3.2)
  P3IE &= ~BIT5;            // HL2 Interrupt Disable (P3.5)
}

void enable_detectorISRs()
{
  P3IFG &= ~BIT2;
  P3IE |= BIT2;            // HL1 Interrupt Enable
  P3IFG &= ~BIT5;
  P3IE |= BIT5;            // HL2 Interrupt Enable
  interrupt_flag = 0;
}

void go_to_sleep()
{
    _BIS_SR(LPM3_bits+GIE);
}


////////////////////////////////////////////////////////////////////////////////////////////////////////

/****** ISR Definitions ******/
void __attribute__ ((interrupt(PORT3_VECTOR))) Port_3(void)  // ISR for Port 3
{
  interrupt_flag = 1;

  if( P3IFG & BIT2 ) //B
  {
    P3IFG &= ~BIT2;
    interrupt_channel = 1;
  }
  else if( P3IFG & BIT5 )  //C
  {
    P3IFG &= ~BIT5;
    interrupt_channel = 2;
  }

  // Wake up from LPM3
  __bic_SR_register_on_exit(LPM3_bits+GIE);
}//end Port 4 ISR*/

void __attribute__ ((interrupt(TIMER0_A0_VECTOR))) Timer_A0(void)  // ISR for Timer A
{
  disable_detectorISRs();

  // Stop Timer
  TA0CCTL0 = ~CCIE;
  TA0CTL |= TACLR + MC__STOP;
  TA0R = 0;
  TA0CTL &= ~TAIE;
  TA0CTL &= ~TAIFG;
  
  timer_start = 0;
  timerA0_flag = 1;
  timerA1_flag = 0;

  __bic_SR_register_on_exit(LPM3_bits + GIE);  // Wake up from LPM3
}//end Timer A0 ISR

/* ISR for Timer A1 used for inter-event timing*/
void __attribute__ ((interrupt(TIMER1_A0_VECTOR))) Timer_A1(void)  // ISR for Timer A
{
  TA1CTL |= TACLR;
  TA1CTL &= ~TAIFG;
  
  //P1OUT ^= BIT0;
  iet_ct++;

  if(iet_ct % WAITTIME == 0)
  {
    timerA1_flag = 1;
    __bic_SR_register_on_exit(LPM3_bits + GIE);
  }
}//end Timer A1 ISR//*/

/* ISR for Timer A2 used in System LFXT Clock setup*/
void __attribute__ ((interrupt(TIMER2_A0_VECTOR))) Timer_A2(void)
{
  __bic_SR_register_on_exit(LPM1_bits);
  TA2CTL |= TACLR;                  /* clear TAR, the clock divider logic and count direction remains unchanged */
  TA2CTL &= ~TAIFG;                 /* clear TimerA2 interrupt flag */
}//end Timer A2 ISR//*/

void __attribute__ ((interrupt(TIMER0_B0_VECTOR))) Timer_B0(void)  // ISR for Timer B
{
  // Stop Timer
  TB0CCTL0 = ~CCIE;
  TB0CTL |= TBCLR + MC__STOP;
  TB0CTL &= ~TBIE;
  TB0CTL &= ~TBIFG;

  __bic_SR_register_on_exit(LPM3_bits + GIE);  // Wake up from LPM3
}//end Timer B0 ISR*/

////////////////////////////////////////////////////////////////////////////////////////////////////////

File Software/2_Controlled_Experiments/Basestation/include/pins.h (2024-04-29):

#ifndef PINS_h
#define PINS_h

#if defined (__MSP430FR5739__)

/* ------------------------------------------------------------------------------------------------
 *                                      GDO0 Pin Configuration
 * ------------------------------------------------------------------------------------------------
 */
#define GDO0_BIT__                     4
#define GDO0_PORT__                    3
#define CONFIG_GDO0_PIN_AS_INPUT()       st( INFIX( P, GDO0_PORT__, SEL0 ) &= ~BV(GDO0_BIT__); ) /* clear pin special function default */
#define GDO0_PIN_IS_HIGH()               ( INFIX( P, GDO0_PORT__, IN ) & BV(GDO0_BIT__))


#define GDO0_INT_VECTOR                  INFIX( PORT, GDO0_PORT__, _VECTOR )
#define ENABLE_GDO0_INT()                st( INFIX( P, GDO0_PORT__, IE )  |=  BV(GDO0_BIT__); ) /* atomic operation */
#define DISABLE_GDO0_INT()               st( INFIX( P, GDO0_PORT__, IE )  &= ~BV(GDO0_BIT__); ) /* atomic operation */
#define GDO0_INT_IS_ENABLED()             (  INFIX( P, GDO0_PORT__, IE )  &   BV(GDO0_BIT__) )
#define CLEAR_GDO0_INT_FLAG()            st( INFIX( P, GDO0_PORT__, IFG ) &= ~BV(GDO0_BIT__); ) /* atomic operation */
#define GDO0_INT_FLAG_IS_SET()            (  INFIX( P, GDO0_PORT__, IFG ) &   BV(GDO0_BIT__) )
#define CONFIG_GDO0_RISING_EDGE_INT()    st( INFIX( P, GDO0_PORT__, IES ) &= ~BV(GDO0_BIT__); ) /* atomic operation */
#define CONFIG_GDO0_FALLING_EDGE_INT()   st( INFIX( P, GDO0_PORT__, IES ) |=  BV(GDO0_BIT__); ) /* atomic operation */


/* ------------------------------------------------------------------------------------------------
 *                                      GDO2 Pin Configuration
 * ------------------------------------------------------------------------------------------------
 */
#define GDO2_BIT__                     6
#define GDO2_PORT__                    3
#define CONFIG_GDO2_PIN_AS_INPUT()       st( INFIX( P, GDO2_PORT__, SEL0 ) &= ~BV(GDO2_BIT__); ) /* clear pin special function default */
#define GDO2_PIN_IS_HIGH()               ( INFIX( P, GDO2_PORT__, IN ) & BV(GDO2_BIT__))

#define GDO2_INT_VECTOR                  INFIX( PORT, GDO2_PORT__, _VECTOR )
#define ENABLE_GDO2_INT()                st( INFIX( P, GDO2_PORT__, IE )  |=  BV(GDO2_BIT__); ) /* atomic operation */
#define DISABLE_GDO2_INT()               st( INFIX( P, GDO2_PORT__, IE )  &= ~BV(GDO2_BIT__); ) /* atomic operation */
#define GDO2_INT_IS_ENABLED()             (  INFIX( P, GDO2_PORT__, IE )  &   BV(GDO2_BIT__) )
#define CLEAR_GDO2_INT_FLAG()            st( INFIX( P, GDO2_PORT__, IFG ) &= ~BV(GDO2_BIT__); ) /* atomic operation */
#define GDO2_INT_FLAG_IS_SET()            (  INFIX( P, GDO2_PORT__, IFG ) &   BV(GDO2_BIT__) )
#define CONFIG_GDO2_RISING_EDGE_INT()    st( INFIX( P, GDO2_PORT__, IES ) &= ~BV(GDO2_BIT__); ) /* atomic operation */
#define CONFIG_GDO2_FALLING_EDGE_INT()   st( INFIX( P, GDO2_PORT__, IES ) |=  BV(GDO2_BIT__); ) /* atomic operation */


/* ------------------------------------------------------------------------------------------------
 *                                      SPI Configuration
 * ------------------------------------------------------------------------------------------------
 */

/* CSn Pin Configuration */
#define SPI_CSN_GPIO_BIT__             3
#define SPI_CONFIG_CSN_PIN_AS_OUTPUT()   st( P1DIR |=  BV(SPI_CSN_GPIO_BIT__); )
#define SPI_DRIVE_CSN_HIGH()             st( P1OUT |=  BV(SPI_CSN_GPIO_BIT__); ) /* atomic operation */
#define SPI_DRIVE_CSN_LOW()              st( P1OUT &= ~BV(SPI_CSN_GPIO_BIT__); ) /* atomic operation */
#define SPI_CSN_IS_HIGH()                 (  P1OUT &   BV(SPI_CSN_GPIO_BIT__) )

/* SCLK Pin Configuration */
#define SPI_SCLK_GPIO_BIT__            2
#define SPI_CONFIG_SCLK_PIN_AS_OUTPUT()  st( P2DIR |=  BV(SPI_SCLK_GPIO_BIT__); )
#define SPI_DRIVE_SCLK_HIGH()            st( P2OUT |=  BV(SPI_SCLK_GPIO_BIT__); )
#define SPI_DRIVE_SCLK_LOW()             st( P2OUT &= ~BV(SPI_SCLK_GPIO_BIT__); )

/* SI Pin Configuration */
#define SPI_SI_GPIO_BIT__              6
#define SPI_CONFIG_SI_PIN_AS_OUTPUT()    st( P1DIR |=  BV(SPI_SI_GPIO_BIT__); )
#define SPI_DRIVE_SI_HIGH()              st( P1OUT |=  BV(SPI_SI_GPIO_BIT__); )
#define SPI_DRIVE_SI_LOW()               st( P1OUT &= ~BV(SPI_SI_GPIO_BIT__); )

/* SO Pin Configuration */
#define SPI_SO_GPIO_BIT__              7
#define SPI_CONFIG_SO_PIN_AS_INPUT()     st( P1DIR &= ~BV(SPI_SO_GPIO_BIT__);)
#define SPI_SO_IS_HIGH()                 ( P1IN & BV(SPI_SO_GPIO_BIT__) )

/* SPI Port Configuration */
#define SPI_CONFIG_PORT()                st( P1SEL1 |= BV(SPI_SI_GPIO_BIT__)   |  \
                                                           BV(SPI_SO_GPIO_BIT__); \
                                                  P2SEL1 |= BV(SPI_SCLK_GPIO_BIT__); )
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

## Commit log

2024-04-26 Initial Pass for CleanUp
    [(FINAL) Extention and 20 Degree Body Assembly.stl, (FINAL) Waldo Slide-On Cap.stl, BOM.xlsx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]
2024-04-30 pcb pdfs
2024-04-30 Update with ReadMe
    [PCB_Housing.stl, PCB_Housing_Cap.stl, PCB_Housing_and_20_DegBody_Assembly.stl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]
2024-05-01 Updating Readme and train model code
    [Sample_Training_Data.csv]
2024-05-01 Updating how to build text
    [PCB_Housing.stl, PCB_Housing_Cap.stl, PCB_Housing_and_20_DegBody_Assembly.stl]
2024-05-01 Hardware ReadMes done
    [Ray_BOM.xlsx]
2024-05-01 Cleaning up folder and Updating Readme. Hardware Folder done
    [(FINAL) Extention and 20 Degree Body Assembly.stl, (FINAL) Waldo Slide-On Cap.stl, BOM.xlsx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]
2024-05-01 pushing updates...
    [Sample_Training_Data.csv, Sample_Training_Data_W_ClosedDoor.csv]
2024-05-01 Removing folder
    [(DRAWINGS) Extention to Waldo.dwg, (DRAWINGS) Waldo Slide-On Cap.0003.dwg, (DRAWINGS) Waldo Slide-On Cap.dwg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]
2024-05-14 Adding sample controlled data and summaries for ITW table
2024-05-14 Adding Data Excel files (Only modification to the files since creation is adding labels to the table columns)
    [W1_GT_All_Hallway1_Results.xlsx, W2_GT_All_Hallway2_Results.xlsx, W3_GT_All_Stairs_Results.xlsx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]
2024-05-16 adding samples of manual matching sensor data to ground truth
2024-05-16 Update description for controlled sample file

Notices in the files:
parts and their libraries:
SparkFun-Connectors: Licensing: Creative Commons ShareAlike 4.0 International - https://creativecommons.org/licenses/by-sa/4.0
